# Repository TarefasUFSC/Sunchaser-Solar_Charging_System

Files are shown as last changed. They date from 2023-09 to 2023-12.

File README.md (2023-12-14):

# Sunchaser-Solar_Charging_System: Controle de Carga PWM com ESP32 e Placa Fotovoltaica

## Introdução

Este projeto foi desenvolvido como parte de um trabalho para Projeto de Sistemas Ubiquos na UFSC, para o controle eficiente da carga de baterias de chumbo-ácido ou de lítio, utilizando uma placa fotovoltaica de 20W. O sistema emprega uma metodologia de modulação de largura de pulso (PWM) controlada por um ESP32 para regular a tensão e a corrente fornecida pela placa solar, assegurando uma tensão estável na bateria. Os dados de carregamento são monitorados e transmitidos para um Broker MQTT, integrando-se ao projeto do Pluviômetro existente. Adicionalmente, um aplicativo móvel fornece acesso local aos dados através de uma API REST.

O projeto é dividido em várias etapas de desenvolvimento, com testes dedicados para cada componente, seguindo princípios de orientação a objetos. Esta documentação fornece uma visão detalhada da estrutura do projeto, descrições de hardware e software, além de instruções operacionais e de diagnóstico.

## Descrição do Projeto

O sistema é projetado para operar em locais remotos, onde a estabilidade da conexão de internet pode ser intermitente. Portanto, ele armazena dados localmente e tenta transmitir informações retroativas quando uma conexão está disponível. A abordagem de design permite o acesso local aos dados do ESP32, que pode alternar entre modos cliente e servidor para facilitar a interação com o usuário por meio de um aplicativo móvel.

### Objetivos

- Manter uma tensão estável de 12V na bateria, conforme especificações técnicas do fabricante.
- Monitorar e armazenar dados de corrente e tensão para análises de longo prazo.
- Permitir o acesso local aos dados via aplicativo móvel para monitoramento e controle.
- Transmitir dados acumulados para um sistema centralizado quando conectado à internet.

Continue lendo para uma visão detalhada da implementação do projeto, incluindo instruções de montagem de hardware, configuração de software, e operação do sistema.

### Visão de Alto Nível do Sistema

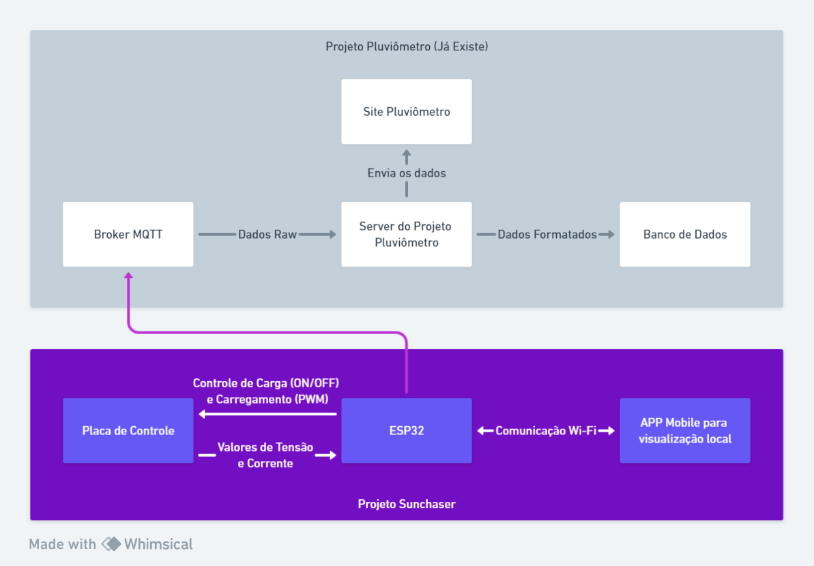
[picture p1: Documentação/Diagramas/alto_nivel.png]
Diagrama Alto Nivel


## [Hardware](https://github.com/TarefasUFSC/Sunchaser-Solar_Charging_System/tree/main/Placa%20de%20Controle/Controle%20de%20Carga%20PWM)

**FEITO COM PROTEUS 8.9**

### Visão Geral

O coração do projeto Sunchaser é uma solução de hardware meticulosamente projetada para o controle eficiente de carga de baterias através de energia solar. Este sistema é construído com um conjunto de placas interconectadas, cada uma desenhada para executar funções específicas dentro do mecanismo de carga.

### Compatibilidade do Proteus

Importante frisar que todo o design foi realizado utilizando o Proteus 8.9. Versões mais recentes do Proteus podem abrir os arquivos do projeto, mas há uma incompatibilidade retroativa: projetos salvos em versões mais novas do software não poderão ser reabertos na versão 8.9. Esta informação é crucial para a manutenção e futuras iterações do projeto por outras equipes.

### [Estruturação Modular do Projeto](https://github.com/TarefasUFSC/Sunchaser-Solar_Charging_System/tree/main/Placa%20de%20Controle/Controle%20de%20Carga%20PWM/hardware_sep_by_function)

O design inicial foi acomodado na pasta `Placa de Controle/Controle de Carga PWM/hardware proteus 8.9`. Para superar desafios encontrados durante os testes, optou-se por uma abordagem modular, segmentando o hardware em diferentes funções:

- ESP com Sensores
- Controle PWM
- Controle da Carga
- Reguladores

Esta estruturação facilitou a identificação e solução de problemas, permitindo testes isolados e otimização de cada módulo.

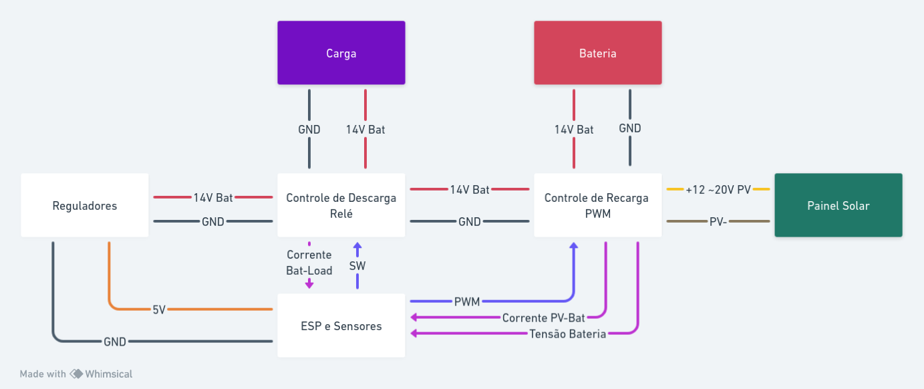
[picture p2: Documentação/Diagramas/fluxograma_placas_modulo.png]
Modularização das Placas


<details>
  <summary><b>Imagens e Descrições dos Circuitos</b></summary>
  Abaixo, as imagens dos circuitos correspondem às seções descritas, proporcionando uma representação visual dos componentes e sua disposição.

#### [ESP e Sensores](https://github.com/TarefasUFSC/Sunchaser-Solar_Charging_System/tree/main/Placa%20de%20Controle/Controle%20de%20Carga%20PWM/hardware_sep_by_function/esp_and_sensors)

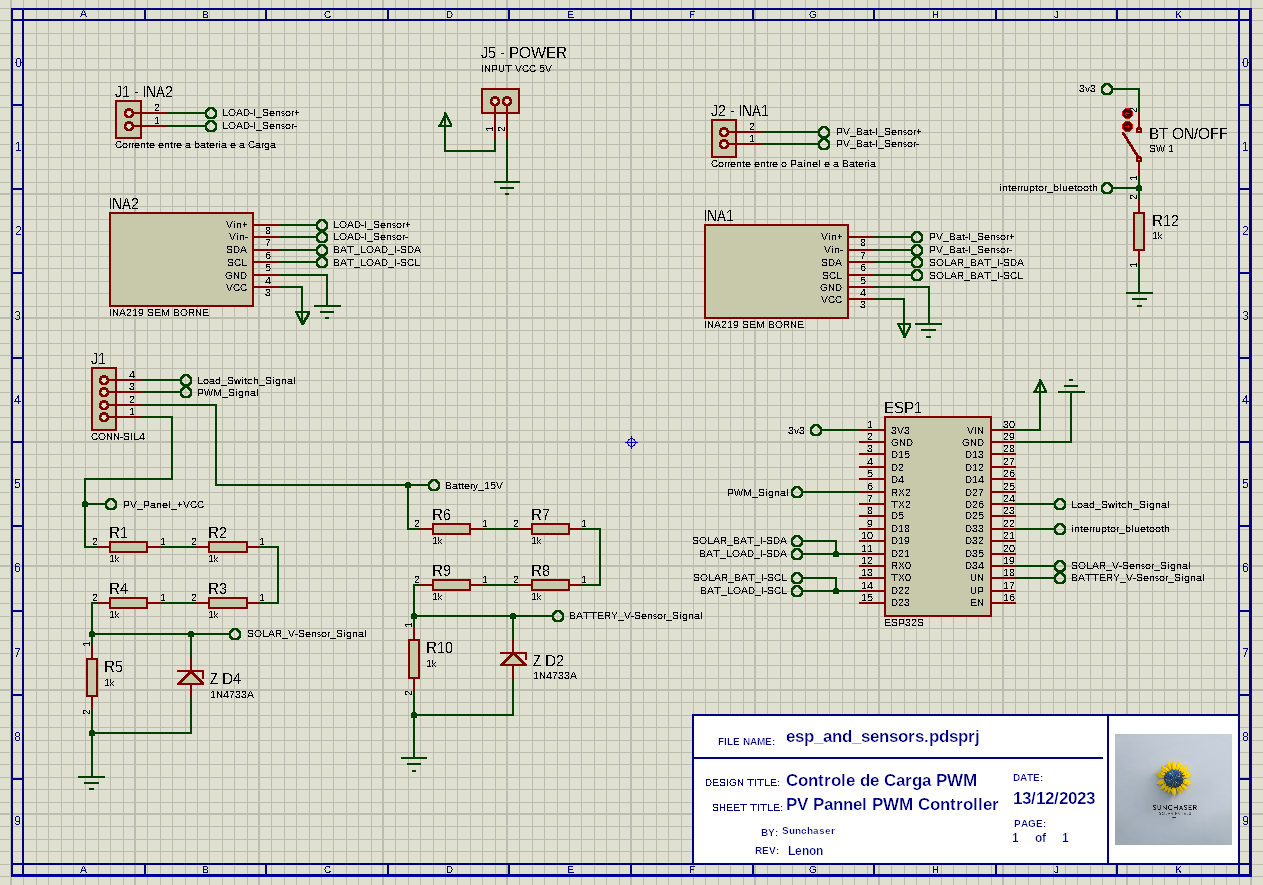
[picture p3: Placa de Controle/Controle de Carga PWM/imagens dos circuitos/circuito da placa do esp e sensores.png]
Circuito da Placa do ESP e Sensores


O circuito do ESP e sensores constitui o núcleo de processamento e coleta de dados, onde o ESP32 opera como a unidade central, gerenciando tanto a comunicação quanto o processamento dos dados de sensores.

#### [Controle PWM](https://github.com/TarefasUFSC/Sunchaser-Solar_Charging_System/tree/main/Placa%20de%20Controle/Controle%20de%20Carga%20PWM/hardware_sep_by_function/controle_de_pot-P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)

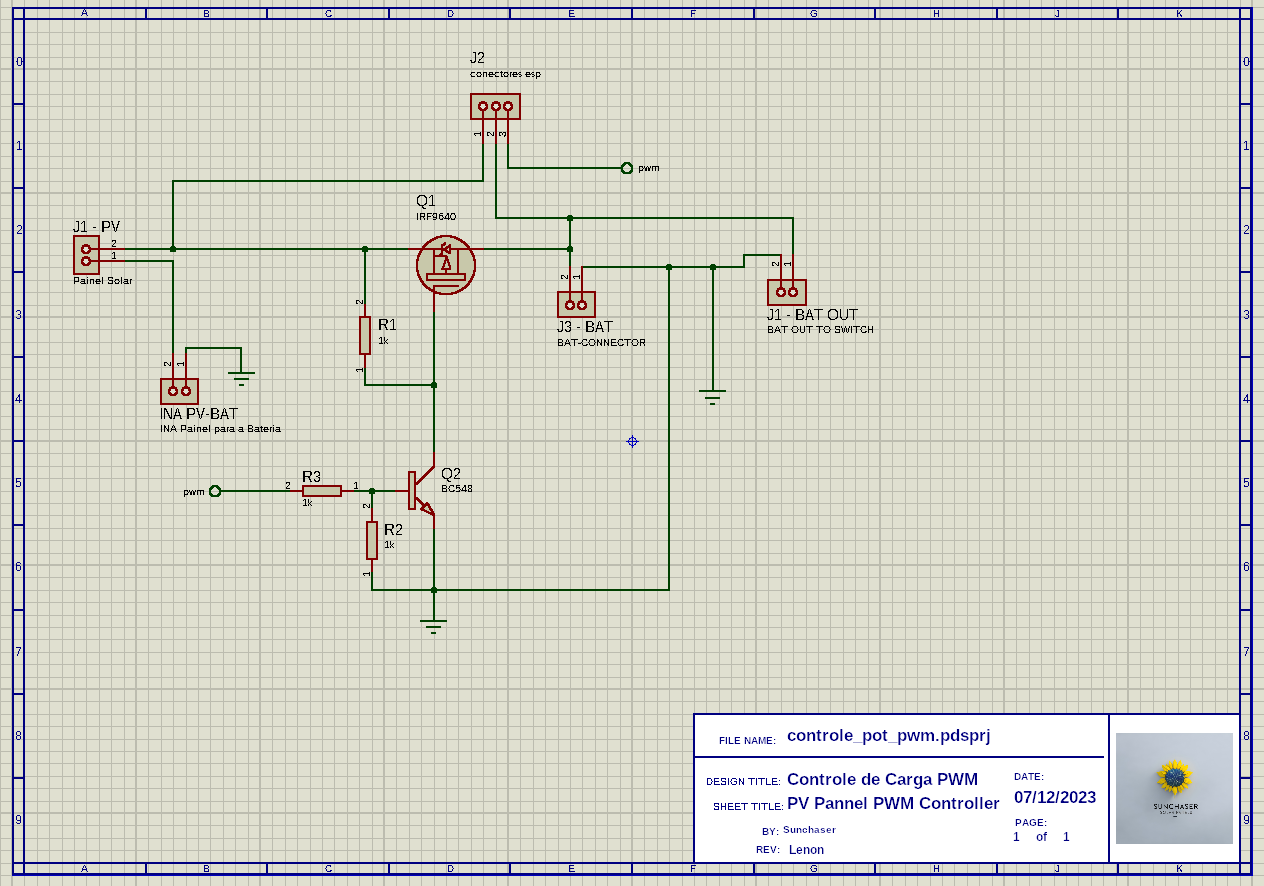
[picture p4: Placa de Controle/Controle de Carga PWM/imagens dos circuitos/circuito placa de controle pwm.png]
Circuito Controle PWM


O circuito de controle PWM manipula a tensão fornecida pela placa fotovoltaica à bateria, utilizando um MOSFET de canal P para modular a carga com precisão, baseando-se nas leituras de tensão da bateria.

#### [Controle do Switch da Carga](https://github.com/TarefasUFSC/Sunchaser-Solar_Charging_System/tree/main/Placa%20de%20Controle/Controle%20de%20Carga%20PWM/hardware_sep_by_function/controle_de_pot-S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)

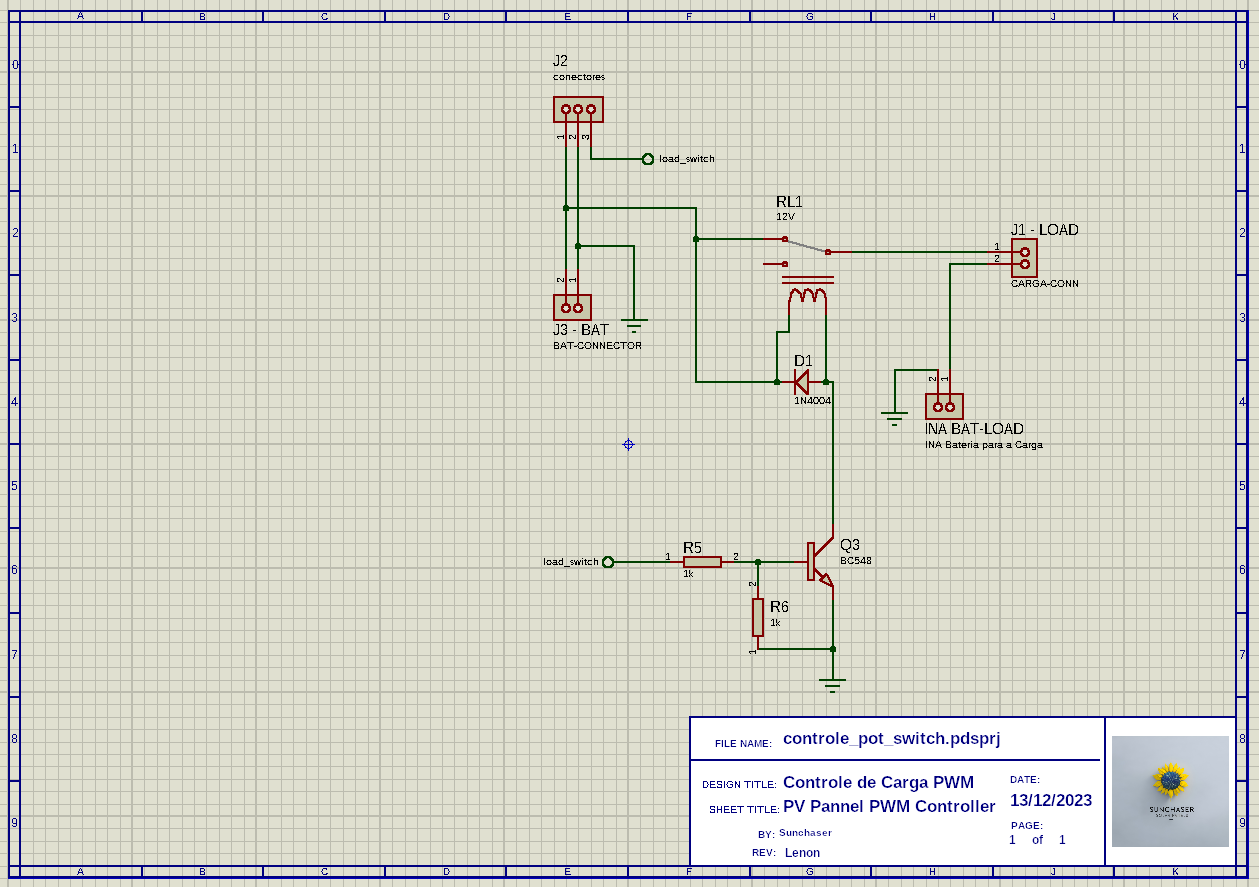
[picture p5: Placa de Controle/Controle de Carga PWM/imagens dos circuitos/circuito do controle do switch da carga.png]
Circuito Controle do Switch da Carga


Esta parte do hardware gerencia a conectividade entre a bateria e a carga, assegurando que a transferência de energia seja feita de maneira eficaz e segura, pois o Relé é aberto caso a tensão da bateria seja muito baixa (o que danifica a vida uti dela) e caso a corrente seja alta demais para a bateria.

#### [Reguladores](https://github.com/TarefasUFSC/Sunchaser-Solar_Charging_System/tree/main/Placa%20de%20Controle/Controle%20de%20Carga%20PWM/hardware_sep_by_function/reguladores_de_te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)

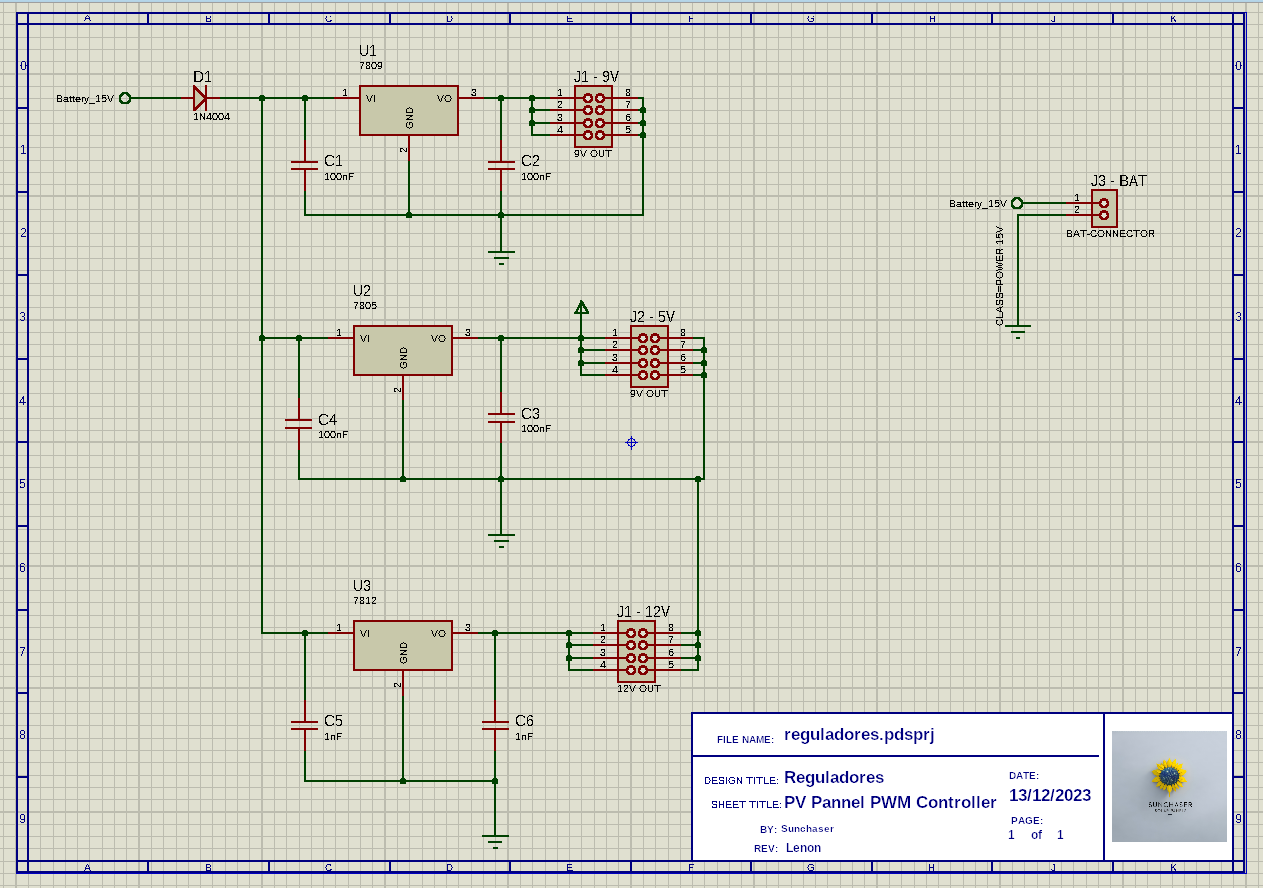
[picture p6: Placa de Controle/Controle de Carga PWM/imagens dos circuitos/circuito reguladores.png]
Circuito Reguladores


Os reguladores de tensão são componentes cruciais do projeto, desempenhando um papel vital ao fornecer tensões DC estáveis de 5V, 9V e 12V. Esta placa reguladora é uma unidade modular, projetada para ser flexível e potencialmente integrável em outros projetos. Recebendo uma tensão de entrada variando de 12 a 20V, os reguladores asseguram a estabilização nas saídas especificadas, proporcionando uma alimentação confiável e segura para todos os componentes eletrônicos do sistema.

#### [Circuito Geral](https://github.com/TarefasUFSC/Sunchaser-Solar_Charging_System/tree/main/Placa%20de%20Controle/Controle%20de%20Carga%20PWM/hardware%20proteus%208.9)

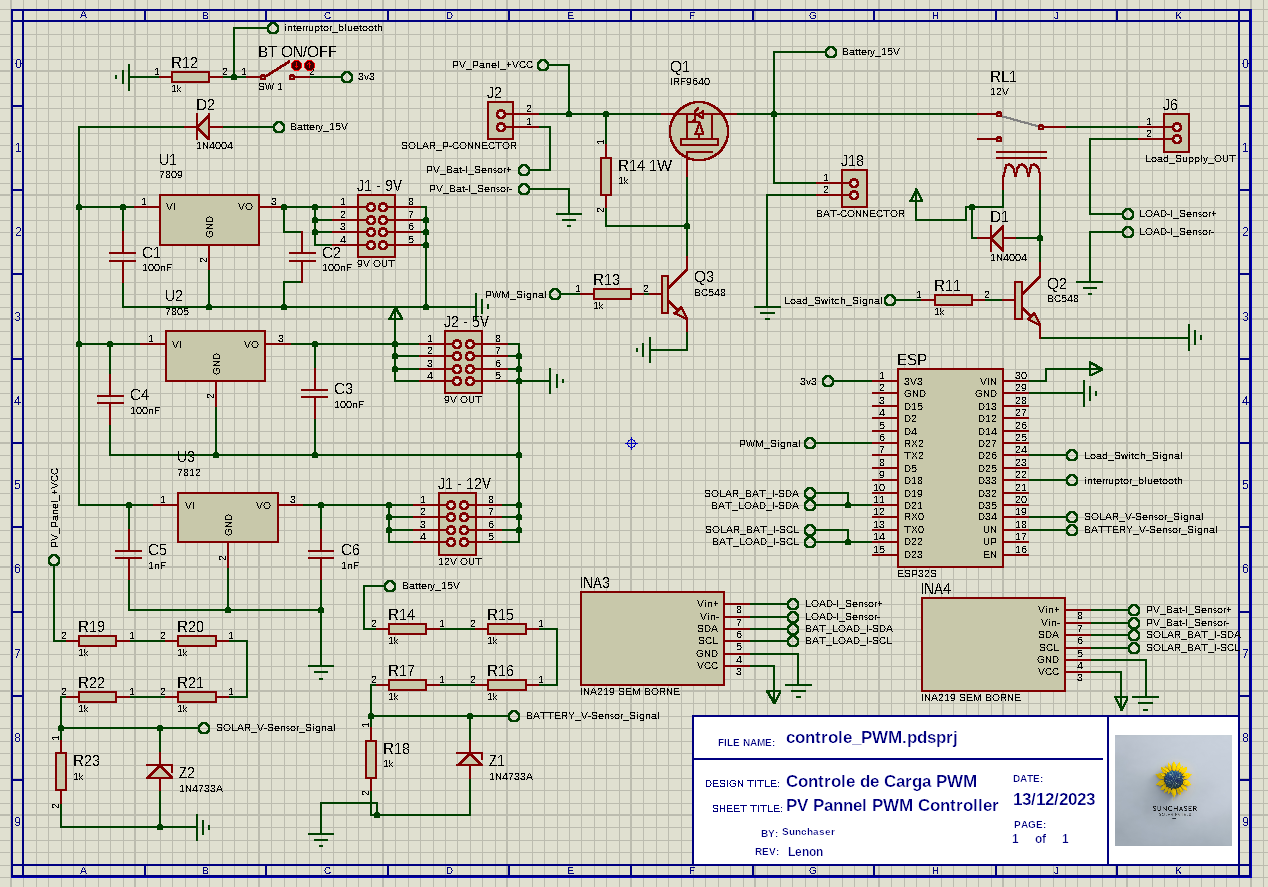
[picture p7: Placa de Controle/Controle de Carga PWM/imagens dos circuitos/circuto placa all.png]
Circuito Visão Geral


</details>

### Observações Técnicas Importantes

- A presença de uma resistência interna na simulação da bateria é vital para o comportamento adequado das tensões no circuito. A ausência desta foi contornada com a implementação de um resistor em paralelo com a fonte de alimentação durante os testes.
- A utilização do ADC1 é obrigatória para leituras analógicas, pois o ADC2 se torna inoperante quando o Wi-Fi do ESP32 está ativado. Ademais, foi observado que a entrada de 5V em qualquer pino do ADC1 pode ocasionar leituras incorretas nos outros pinos. Para resolver isso, a tensão de pulldown da interrupção foi ajustada para 3.3V.

### Futuras Melhorias e Iterações

O projeto é configurado para ser altamente escalável e adaptável. Recomenda-se que futuras equipes expandam as capacidades do sistema, incorporando novas configurações e aprimorando as especificações técnicas, como as relacionadas à bateria, para atender a novas demandas ou melhorar a eficiência do controle de carga usando MPPT.

## Configuração de Software

### Pinagem

| Pino (Nome no Código) | Número do Pino | Arquivo de Declaração | Observações |
| --- | --- | --- | --- |
| `PWM_Pin` | 16 | BatteryControl.h | Utilizado para controle PWM. |
| `S2_Pin` | 26 | BatteryControl.h | - |
| `interrupt_pin` | 33 | communicator.h | Não pode ser 5V para evitar problemas com ADC1. |
| `Battery_Voltage_Pin` | 39 | Sensors.h | Pino de leitura de tensão da bateria, deve estar no ADC1. |
| `Solar_Voltage_Pin` | 34 | Sensors.h | Pino de leitura de tensão do painel solar, deve estar no ADC1. |
| `INA219_Sensor1_SCL`  | 11 | Obrigatório | SCL do primeiro sensor INA219. |
| `INA219_Sensor1_SDA`  | 10 | Obrigatório | SDA do primeiro sensor INA219. |
| `INA219_Sensor2_SCL`  | 11 | Obrigatório | SCL do segundo sensor INA219. |
| `INA219_Sensor2_SDA`  | 10 | Obrigatório | SDA do segundo sensor INA219. |

Observações Gerais:

- Os pinos de leitura analógica devem estar no ADC1 devido ao uso do Wi-Fi, que interfere com o ADC2.
- O pino `interrupt_pin` não deve receber 5V para evitar conflitos com outras leituras no ADC1.

### Ambiente de Desenvolvimento

O código-fonte foi desenvolvido na Arduino IDE, uma plataforma de desenvolvimento que permite a escrita, compilação e upload de programas para placas compatíveis com Arduino, como o ESP32 utilizado neste projeto.

### Instalação

1. Instale a última versão da Arduino IDE a partir do [site oficial](https://www.arduino.cc/en/software).
2. Configure a Arduino IDE para suportar o ESP32 seguindo as instruções disponíveis na [documentação do ESP32](https://docs.espressif.com/projects/arduino-esp32/en/latest/installing.html).
3. Instale todas as bibliotecas necessárias mencionadas nos arquivos `package.json` e `yarn.lock` localizados na pasta `App Mobile/mobile`.

### Descrição dos Programas de Teste

Os programas de teste localizados em `Programas ESP/Desenvolvimento` são fundamentais para validar o funcionamento individual de cada componente do sistema. Cada subdiretório contém um exemplo de código que pode ser compilado e carregado separadamente para testar sensores, comunicação, controle PWM, entre outros.

### Programa Final

A pasta `Programas ESP/ProgramaFinal` contém o código-fonte consolidado que será executado no ESP32. Inclui a integração das classes desenvolvidas, a lógica de controle PWM e a comunicação com o Broker MQTT.

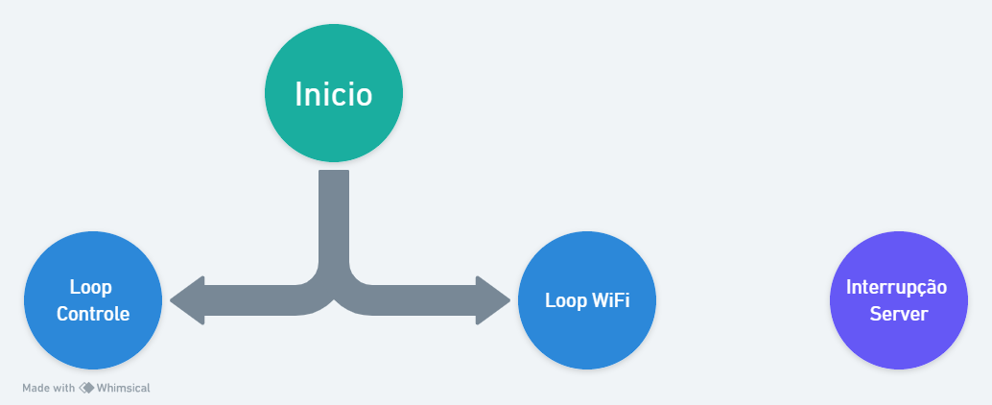
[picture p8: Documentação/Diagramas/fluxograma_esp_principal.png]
Funcionamento Geral


# Documentação do Código

O software do projeto é composto por várias classes, cada uma responsável por uma parte específica da lógica de controle e comunicação do sistema. Abaixo estão os arquivos principais e a descrição de suas responsabilidades e operações:

<details>
  <summary><b>Classe BatteryControl</b></summary>
  
  - **Arquivos**: `BatteryControl.cpp`, `BatteryControl.h`
  - **Responsabilidade**: Controla o processo de carregamento da bateria ao modular a tensão fornecida pelo painel solar. Garante a manutenção da tensão da bateria nos níveis ideais para otimizar o carregamento e a vida útil da bateria.
  - **Métodos Principais**:
    - `PWM_init()`: Inicializa a configuração do PWM.
    - `battery_loop()`: Executa o loop principal de controle da bateria, ajustando o PWM conforme necessário.
    - `check_error(float error)`: Verifica e lida com erros no sistema de carregamento.
    - `stopCharging()`: Interrompe o processo de carregamento da bateria.
    - `bulk_stage()`, `absorption_stage()`, `float_stage()`: Gerenciam as diferentes fases do processo de carregamento.
    - `charging_control()`: Controle lógico para a regulação do carregamento da bateria.
    - `load_connection()`: Gerencia a conexão e desconexão da carga da bateria.
    - `changeDutyCycle()`: Ajusta o ciclo de trabalho do PWM para regular a tensão.

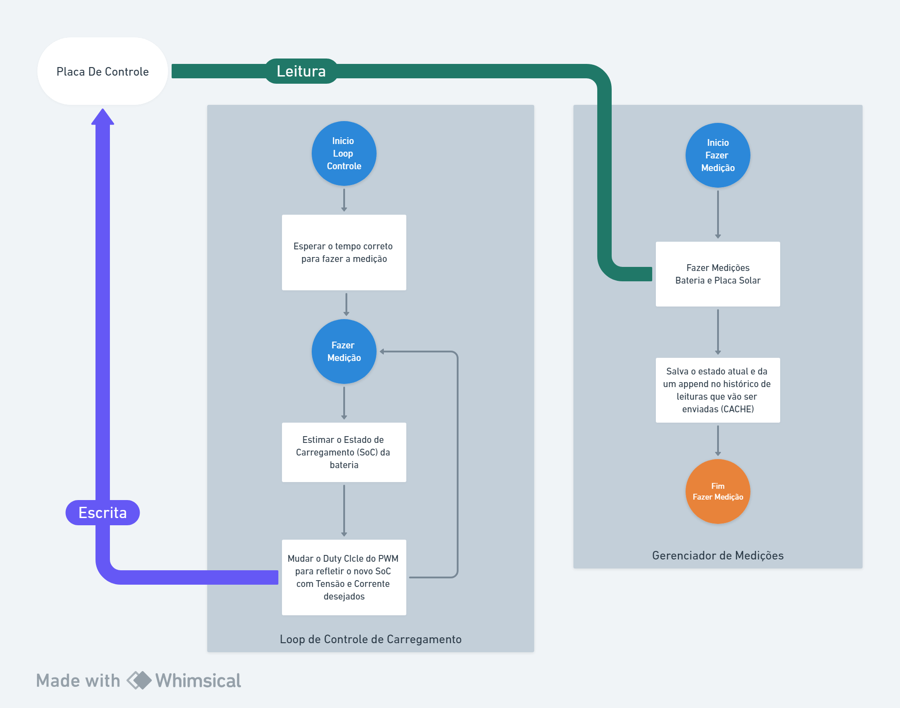
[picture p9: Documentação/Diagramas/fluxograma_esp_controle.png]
Diagrama do Cotrole de Carga


</details>

<details>
  <summary><b>Classe Sensors</b></summary>

- **Arquivos**: `Sensors.cpp`, `Sensors.h`
- **Responsabilidade**: Realiza a leitura da corrente e tensão da bateria e do painel solar.
- **Métodos Principais**:
  - `INA_init()`: Inicializa os sensores INA219.
  - `battery_current()`, `pv_current()`: Retorna a corrente medida pela bateria e pelo sensor do painel solar.
  - `battery_voltage()`, `pv_voltage()`: Retorna a tensão medida pela bateria e pelo sensor do painel solar.
  </details>

<details>
  <summary><b>Classe TimeConfigurations</b></summary>

- **Arquivo**: `TimeConfigurations.h`
- **Responsabilidade**: Armazena as configurações de tempo relacionadas ao intervalo de leitura, tamanho máximo do cache e memória de longo prazo.
</details>

<details>
  <summary><b>Classe TimerInterrupt</b></summary>

- **Arquivos**: `TimerInterrupt.cpp`, `TimerInterrupt.h`
- **Responsabilidade**: Gerencia as interrupções do temporizador para realizar operações periódicas.
- **Métodos Principais**:

  - `timer_init()`: Inicializa o timer.
  - `timer_interruption()`: Método chamado em cada interrupção do temporizador.
  - `tryToSendCacheToServer()`: Tenta enviar dados do cache para o servidor.
  </details>
  <details>
    <summary><b>Classe SaveToFlash</b></summary>

- **Arquivos**: `SaveToFlash.cpp`, `SaveToFlash.h`
- **Responsabilidade**: Gerencia o armazenamento e recuperação de dados de leituras na memória flash.
- **Métodos Principais**:
  - `mountLittleFS()`: Monta o sistema de arquivos LittleFS.
  - `saveToCache()`, `saveToLongTerm()`: Salva as leituras no cache ou na memória de longo prazo.
  - `get_readings_from_cache()`, `get_readings_from_longterm()`: Recupera leituras do cache ou da memória de longo prazo.

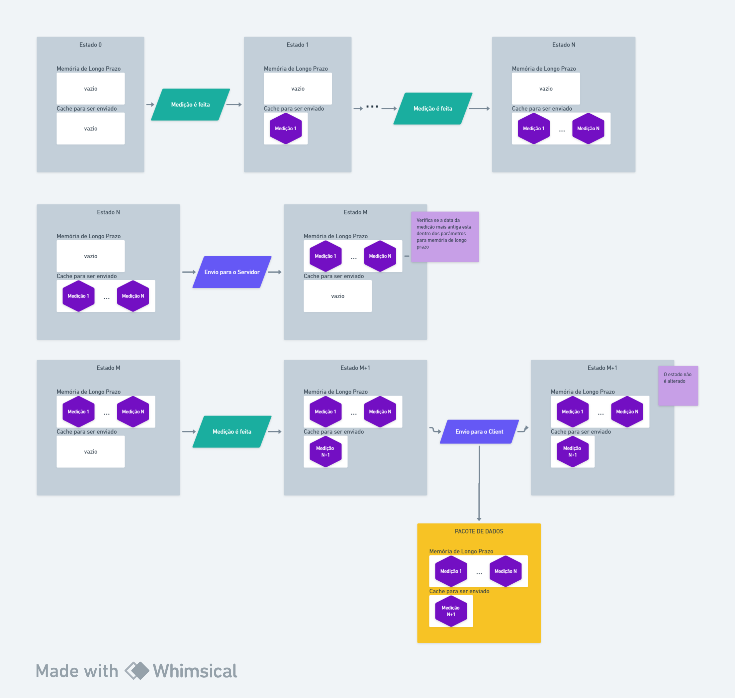
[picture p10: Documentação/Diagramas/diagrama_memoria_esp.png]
Diagrama Memoria


</details>

<details>
  <summary><b>Classe Communicator</b></summary>

- **Arquivos**: `communicator.cpp`, `communicator.h`, `communicator_client_module.cpp`, `communicator_interruption_module.cpp`, `communicator_mqtt_module.cpp`, `communicator_server_module.cpp`
- **Responsabilidade**: Esta classe gerencia toda a comunicação do ESP32, atuando como um cliente para se conectar ao Broker MQTT, e como um servidor para interagir com o aplicativo móvel. A classe também gerencia a transição entre o modo de economia de energia e operação normal e lida com interrupções externas que podem sinalizar a necessidade de mudança no estado de operação.

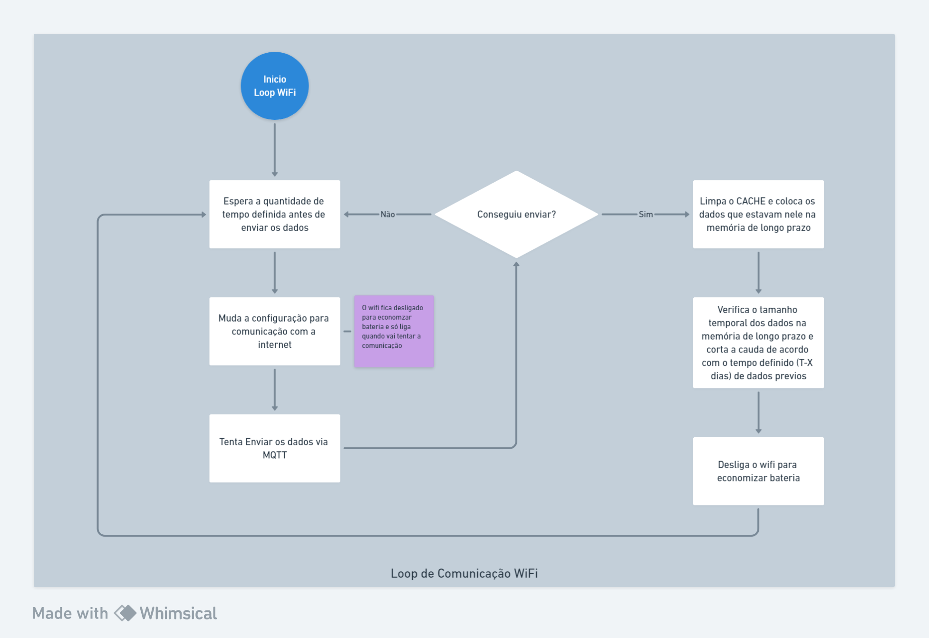
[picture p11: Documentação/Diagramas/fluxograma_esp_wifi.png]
Diagrama do Wifi Client

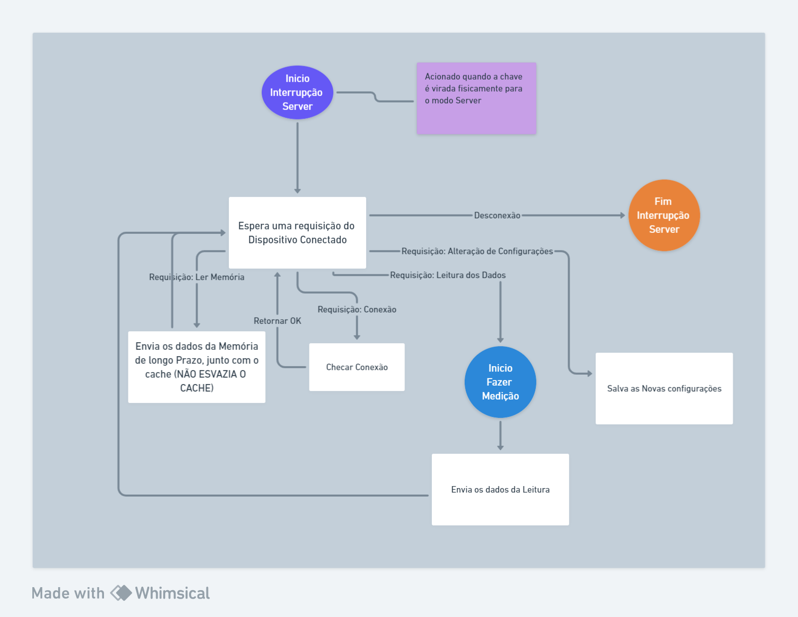
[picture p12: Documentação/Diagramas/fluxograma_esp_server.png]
Diagrama do Wifi Server


### Métodos Principais

- `init()`: Configura os componentes necessários e inicia a conexão Wi-Fi.
- `sleep()`: Desativa o Wi-Fi para economizar energia.
- `reconnect_client()`: Reconecta o ESP32 à rede Wi-Fi e ao broker MQTT após o período de sono.
- `attach_interruption()`: Configura a interrupção externa que permite ao ESP32 alternar entre os modos cliente e servidor.
- `check_interruption_flag()`: Verifica se uma interrupção ocorreu, indicando que o estado de operação deve ser alterado.
- `startServer()`: Inicia o servidor HTTP para comunicação local com o aplicativo móvel.
- `connectToMQTT()`: Estabelece conexão com o Broker MQTT e gerencia a reconexão se necessário.
- `handleClientRequests()`: Processa as requisições recebidas quando o ESP32 está operando como servidor HTTP.
- `_setup_mqtt()`: Configura o cliente MQTT com o servidor e porta corretos, e define a função de callback para mensagens recebidas.
- `_mqtt_loop()`: Mantém a conexão MQTT ativa e processa qualquer mensagem recebida.
- `_wifi_ap_config()`: Configura o ponto de acesso Wi-Fi quando o ESP32 está no modo servidor.
- `_stop_ap()`: Desativa o ponto de acesso Wi-Fi e o servidor HTTP quando não são mais necessários.

### Observações

- O método `sleep()` é crítico para a conservação de energia, especialmente em ambientes remotos onde a energia é limitada.
- O sistema de interrupção permite que o dispositivo mude dinamicamente entre os modos de operação sem a necessidade de reinicialização ou interação manual.
- A implementação do MQTT é robusta, com mecanismos de reconexão e callbacks para garantir a entrega de mensagens mesmo em condições de rede instáveis.
</details>

# Operação do Programa

O ciclo de execução principal do programa é controlado pelo arquivo `ProgramaFinal.ino`, que coordena as operações das classes e gerencia o fluxo de controle do sistema. O arquivo contém a função `setup()` para inicialização e a função `loop()` para o ciclo de execução contínuo.

- Na função `setup()`, o sistema inicia conectando-se à rede Wi-Fi e sincronizando o horário para garantir que os dados sejam timestamped corretamente.
- Em seguida, os módulos de controle de carga e sensores são inicializados, preparando o sistema para começar o monitoramento e controle.
- A função `loop()` entra em um ciclo onde:
  - A lógica de controle de carga é executada para ajustar o PWM e manter a tensão da bateria.
  - As leituras dos sensores são feitas e armazenadas periodicamente no cache local.
  - O sistema tenta enviar dados acumulados para o Broker MQTT e, em caso de sucesso, transfere esses dados para a memória de longo prazo.
  - Se o switch de acesso local for ativado, o ESP32 muda para o modo servidor, permitindo que o aplicativo móvel se conecte e interaja com o sistema.

### Documentação das APIs

A comunicação com o ESP32 pode ser realizada através das seguintes APIs, disponíveis quando o ESP está em modo servidor:

| Operação | Rota | Query Params  | Body | Retorno | Observações |
| --- | --- | --- | --- | --- | --- |
| GET | /cache | page: Numeric | - | JSON: Lista de leituras do cache, total de itens, itens por página (10) | Máximo de 10 itens por página |
| GET | /ltm | page: Numeric | - | JSON: Lista de leituras da memória, total de itens, itens por página (10) | Máximo de 10 itens por página |
| POST | /reading  | - | - | JSON: Novas medições | - |
| POST | /settings | - | JSON: Novas configurações | - | O app verifica o sucesso pela resposta do status code |
| GET | /settings | - | - | JSON: Configurações atuais | - |
| GET | /check | - | - | String: "conectado!" | Utilizado para verificar a conexão com o ESP |

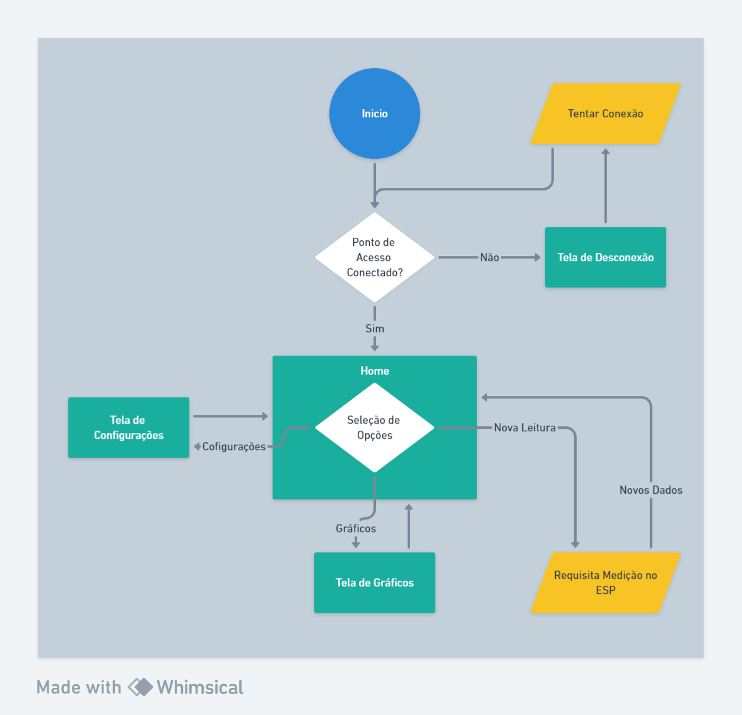
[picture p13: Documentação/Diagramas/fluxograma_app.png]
Diagrama do Aplicativo


### Diagnóstico de Problemas e Soluções

Durante o desenvolvimento, foram identificados e solucionados diversos desafios:

- **Problema de Versão do Proteus**: Limitação da versão 8.9 do Proteus para salvar e abrir arquivos sem perder a compatibilidade.
- **Comportamento Inesperado de Tensões**: Solucionado com a inclusão de uma resistência em paralelo à fonte de bancada.
- **Limitações dos ADCs do ESP32**: Ajustes nas leituras analógicas para evitar conflitos entre o ADC2 e o uso do Wi-Fi e erros causados por tensões altas nos pinos do ADC1.

### Melhorias e Manutenção

Algumas sugestões para melhorias futuras incluem:

- Inclusão de novas configurações na classe de ajustes, como especificações técnicas variáveis da bateria.
- Aumento da robustez do sistema contra falhas de conectividade.
- Interface de usuário aprimorada no aplicativo móvel para facilitar a interação e o monitoramento.

Manter a documentação atualizada e criar testes para novas funcionalidades são essenciais para a manutenção contínua do projeto.

## Estrutura de Arquivos

O projeto está organizado em diretórios que separam cada componente e fase de desenvolvimento, facilitando a navegação e compreensão do sistema como um todo. Abaixo está a árvore de arquivos com a descrição de cada diretório e arquivo-chave:

<details>
  <summary><b>Mostrar File Tree</summary>

  ```
.
├── App Mobile
│   └── mobile
│       ├── App.js
│       ├── app.json
│       ├── babel.config.js
│       ├── package.json
│       ├── src
│       │   ├── assets
│       │   │   ├── *.png
│       │   ├── components
│       │   │   └── components.js
│       │   ├── pages
│       │   │   ├── graph.js
│       │   │   ├── home.js
│       │   │   └── settings.js
│       │   └── routes
│       │       └── routes.js
│       └── yarn.lock
├── Documentação
│   ├── Cronograma/
│   ├── Diagramas/
│   ├── Planejamento/
│   ├── Relatorios/
│   └── Revisão de Lietratura/
├── logo/
├── Placa de Controle
│   ├── Controle de Carga PWM
│   │   ├── ESP32-Pinout.jpg
│   │   ├── hardware/ -> (Antigo)
│   │   ├── hardware proteus 8.9/ -> Placa Geral com tudo incluso
│   │   ├── hardware_sep_by_function
│   │   │   ├── controle_de_pot/
│   │   │   ├── controle_de_pot-PWM/
│   │   │   ├── controle_de_pot-SWITCH/
│   │   │   ├── esp_and_sensors/
│   │   │   └── reguladores_de_tensao/
│   │   ├── imagens dos circuitos/
│   │   ├── teste controle MOSFETs/
│   ├── Cuk Converter/ -> Testes do inicio do projeto usando o conversor cuk (Não é usado mais)
├── Programas ESP
│   ├── Desenvolvimento
│   │   ├── 1-CurrentSensorExample/
│   │   ├── 2-VoltageReadingExample/
│   │   ├── 3-Current_Voltage_reading/
│   │   ├── 4-PWMControlExample/
│   │   ├── 5-BatteryControl/
│   │   ├── 6-TimerInterrupt/
│   │   ├── 7-BLE_server/
│   │   ├── 8-LittleFS/
│   │   ├── ESP-GetTime/
│   │   ├── MainProject/
│   │   └── Wifi-Server_Client/
│   ├── ProgramaFinal
│   │   ├── BatteryControl.cpp
│   │   ├── BatteryControl.h
│   │   ├── communicator_client_module.cpp
│   │   ├── communicator.cpp
│   │   ├── communicator.h
│   │   ├── communicator_interruption_module.cpp
│   │   ├── communicator_mqtt_module.cpp
│   │   ├── communicator_server_module.cpp
│   │   ├── FinalProgram.md
│   │   ├── FinalProgram.xml
│   │   ├── ProgramaFinal.ino
│   │   ├── PubSubClient.cpp
│   │   ├── PubSubClient.h
│   │   ├── SaveToFlash.cpp
│   │   ├── SaveToFlash.h
│   │   ├── Sensors.cpp
│   │   ├── Sensors.h
│   │   ├── TimeConfigurations.h
│   │   ├── TimerInterrupt.cpp
│   │   └── TimerInterrupt.h
│   └── pubsubclient-master.zip
├── README.md
└── Referencias que o professor deu no inicio
    ├── *.pdf

```

</details>

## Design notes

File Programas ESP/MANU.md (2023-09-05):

Cria um branch e trabalha nessa pasta.
para cada teste crie uma pasta separada e depois junta tudo na pasta `Programa Final`

Seria interessante voce ja ir fazendo as coisas usando modularização com funções o maximo possivel, tipo `float get_voltage_value_sensorX()` (ou vc pode passar um identificador do sensor como referencia, sla. É só pra facilitar a sua vida)

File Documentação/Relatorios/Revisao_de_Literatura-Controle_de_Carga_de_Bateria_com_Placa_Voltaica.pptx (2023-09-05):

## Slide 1

Controle de Carga de Bateria com Placa Voltaica

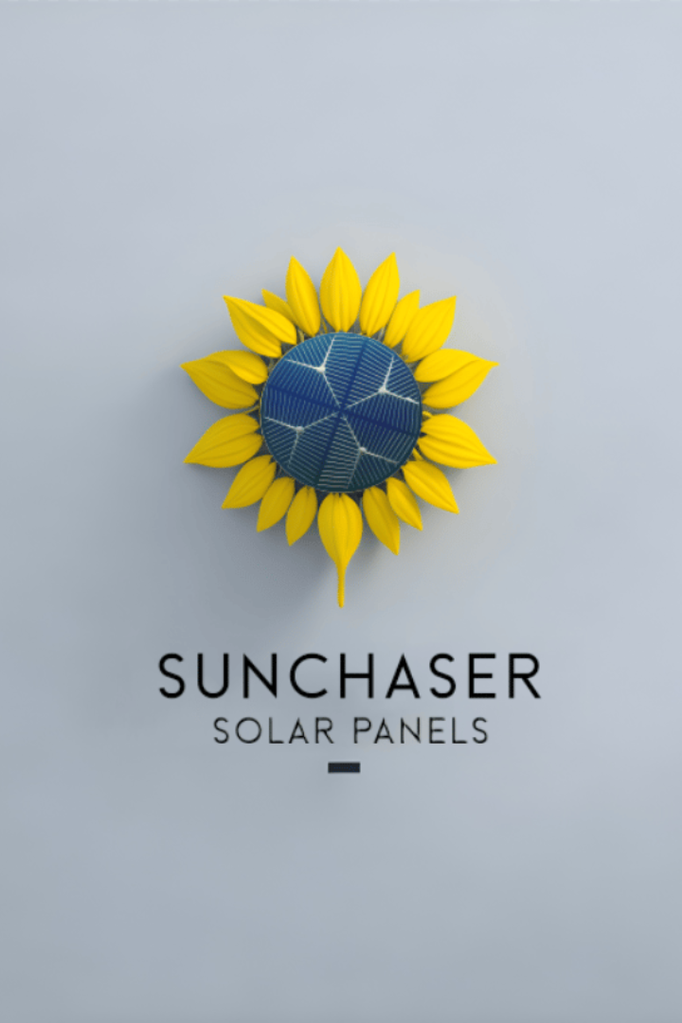
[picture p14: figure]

- Lucas Eduardo Schlenert de Oliveira

- Manoella Rockembach

- Rodrigo Ferraz Souza

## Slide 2

Introdução

Gestão eficiente de energia é uma prioridade de nosso mundo. Em um esforço para soluções mais sustentáveis, este projeto foca no controle de carga de bateria de Chumbo-Ácido (12V 5Ah) usando uma placa fotovoltaica. Com este objetivo, o controle PWM é utilizado para gerenciar tensão e corrente.

A integração com sistemas externos é possível via MQTT Broker, e o acesso local aos dados pode ser realizado através de um aplicativo móvel com Bluetooth.

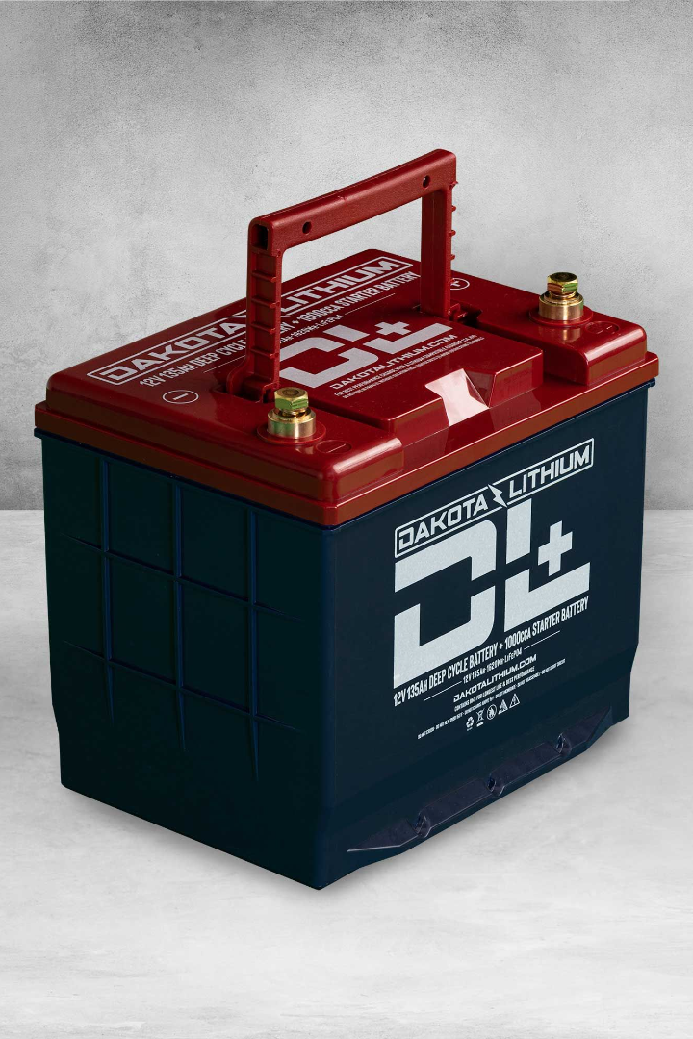
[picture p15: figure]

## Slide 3

Gerenciamento de tensão e corrente na carga da bateria usando um ESP32

Broker MQTT utilizado para comunicação com o servidor do Pluviômetro

Utilização de um aplicativo móvel com Bluetooth

Notificações push no aplicativo mobile usando o Google Firebase

Objetivos do Projeto

Uso do controle PWM

Integração com sistemas externos

Acesso local aos dados

Alertas (Opcional)

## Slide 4

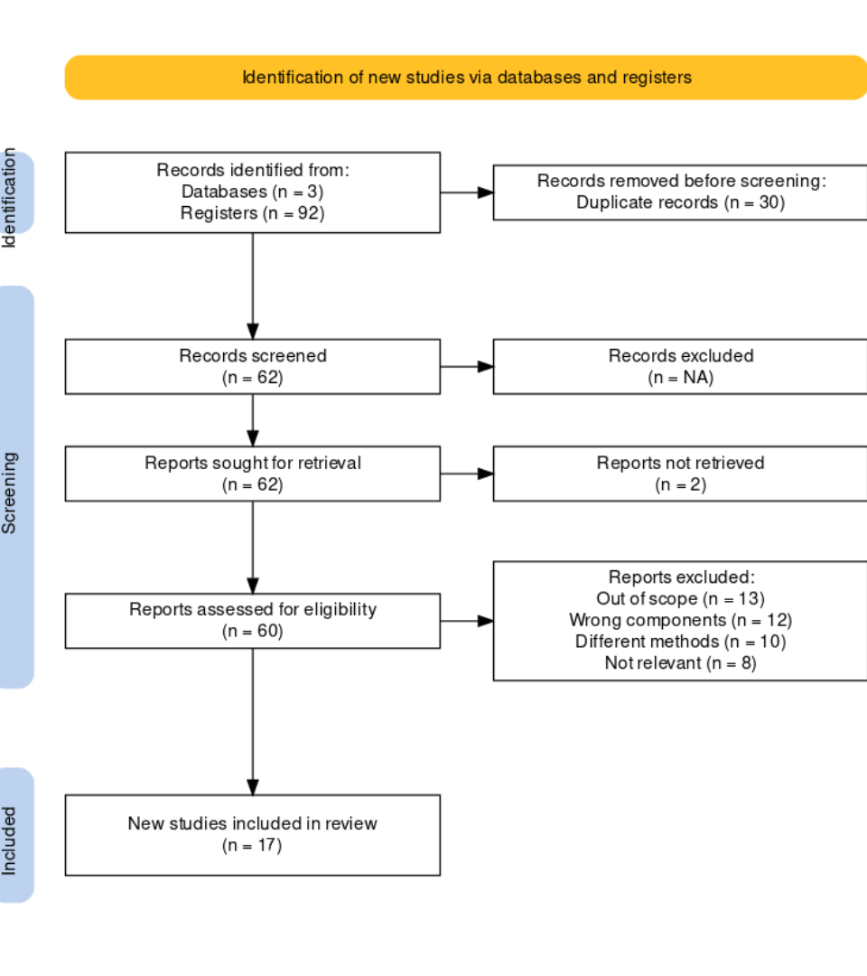
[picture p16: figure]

Revisão de Literatura

62 artigos analisados

Nas bases IEEE, Web of Science e Scopus

17 artigos inclusos

Após análise de escopo, componentes usados, metodologia e relevância

Principais temas abordados

Eficiência energética, métodos de controle e estimativa do SoC.

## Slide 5

Cronograma - Agosto, Setembro e Outubro

Aqui está o cronograma para os meses de agosto, setembro e outubro:Visualizar a planilha do cronograma (https://docs.google.com/spreadsheets/d/1eAHwZ90z7WzfCC42r8mtiiq0TJHsQQWhFocUj3pGwtQ/edit?usp=sharing)

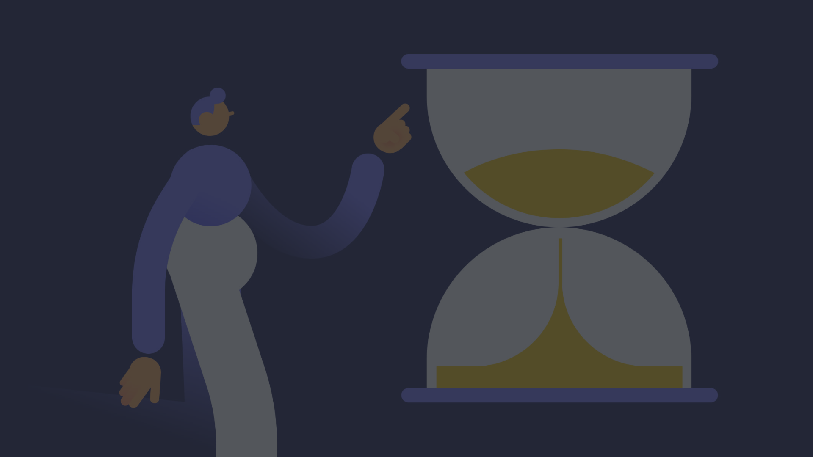
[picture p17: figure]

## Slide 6

- Carregamento adaptativo para otimizar a bateria de chumbo ácido, como destacado por [Lavety et al. 2019]

- Sistemas de monitoramento [Lin et al. 2016] para melhorar a vida útil da bateria em configurações PWM

- Algoritmos para otimizar o carregamento da bateria, enfatizados por [Belarbi et al. 2019] e [Yoomak et al. 2018]

- O projeto visa otimizar o armazenamento e uso de energia solar

- Combinação de estratégias avançadas pode levar a um sistema mais eficiente

- Recomenda-se testes para validar e refinar o sistema

Conclusão

Estratégias de Carregamento:

Monitoramento e Feedback:

Integração com Painel Solar:

Considerações Finais:

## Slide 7

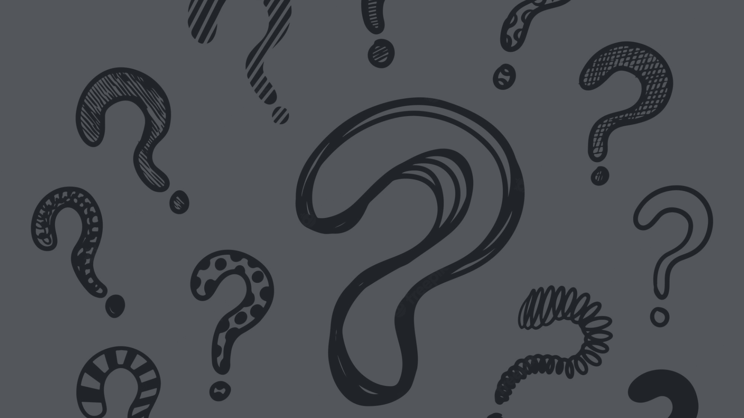
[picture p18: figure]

Perguntas?

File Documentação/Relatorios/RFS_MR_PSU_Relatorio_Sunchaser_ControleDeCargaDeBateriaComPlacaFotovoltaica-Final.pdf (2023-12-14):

## Controle de Carga de Bateria com Placa Voltaica

Lucas Eduardo Schlenert de Oliveira¹

, Manoella Rockembach¹

, Rodrigo Ferraz Souza¹

1Universidade Federal de Santa Catarina (UFSC)

engcomp.lucasedu@gmail.com

manu.rockemba@gmail.com

dev.rodrigofs@gmail.com

Abstract. This report delves into the development of a battery charge control system using a voltaic plate, specifically for a Lead-Acid battery (12V 5Ah). The core of this project revolves around the use of PWM control to manage the voltage and current from the plate to the battery, ensuring efficient energy management. The system aims to control the battery’s charging in various States of Charging, ensuring efficient and safe charging. Furthermore, the project seeks to integrate communication with external systems, transmitting voltage and current data to a rain gauge project server via an MQTT Broker. A mobile application will also allow local access to charging data via Acess point to the ESP server. Advanced features, such as alert systems, are proposed, but due to time constraints, they might not be incorporated.

Resumo. Este relatorio aprofunda-se no desenvolvimento de um sistema de ´ controle de carga de bateria usando uma placa voltaica, especificamente para uma bateria de Chumbo-Acido (12V 5Ah). O cerne deste projeto gira em torno ´ do uso do controle PWM para gerenciar a tensao e a corrente da placa para ˜ a bateria, garantindo uma gestao eficiente de energia. O sistema visa con- ˜ trolar o carregamento da bateria em varios Estados de Carga, assegurando ´ um carregamento eficiente e seguro. Alem disso, o projeto busca integrar a ´
comunicaçao com sistemas externos, transmitindo dados de tens ˜ | ao e corrente ˜
para um servidor de projeto de pluviometro via um Broker MQTT. Um aplicativo ˆ
movel tamb ´ | em permitir ´ | a o acesso local aos dados de carregamento via Ponto ´
de Acesso ao servidor do ESP. Funcionalidades avançadas, como sistemas de
alerta, sao propostas, mas devido a limitaç ˜ | oes de tempo, elas podem n ˜ | ao ser ˜
incorporadas.

### 1. Introduçaõ

Em um mundo crescentemente voltado para soluçoes sustent ˜ | aveis, a gest ´ | ao eficiente de ˜
energia torna-se uma prioridade. Neste contexto, o presente documento aborda o desenvolvimento de um sistema de controle de carga de bateria de Chumbo-Acido (12V 5Ah) ´
utilizando uma placa voltaica. O cerne deste projeto e a utilizaç ´ | ao de um controle PWM ˜
para gerenciar a tensao e corrente da placa em direç ˜ | aõ a bateria, garantindo uma gest ` | aõ
eficaz da energia.
O sistema controlara o carregamento da bateria em diversos ´ | States of Charging,
assegurando um carregamento eficiente e seguro, o que contribui para maximizar o tempo

de vida da bateria. Alem da efici ´ | encia no controle de energia, o projeto visa uma ˆ
comunicaçao integrada com sistemas externos. Os dados de tens ˜ | ao e corrente ser ˜ | ao trans- ˜
mitidos para um servidor do projeto do pluviometro por meio de um ˆ | Broker MQTT. Adi-
cionalmente, um aplicativo movel permitir ´ | a o acesso local aos dados de carregamento via ´
ponto de acesso ao servidor do ESP. Como um diferencial, ha a proposta de implementar ´ um sistema de alertas. No entanto, devido a limitaçoes de tempo, essa funcionalidade ˜
pode nao ser incorporada. Caso seja, os alertas ser ˜ | ao gerados pelo servidor j ˜ | a existente, ´
com base nas entradas de dados dos sensores. Uma inovaçao desejada ˜ | e que, ao identi- ´
ficar uma situaçao cr ˜ | ítica, uma notificaçao de alerta seja enviada ao aplicativo m ˜ | ovel do ´
usuario por meio do ´ | Google Firebase.
Neste documento, apos a introduç ´ | ao, apresentaremos uma seç ˜ | ao dedicada ˜ | a re- `
visao metodol ˜ | ogica. Nela, discutiremos a metodologia adotada para a realizaç ´ | ao da re- ˜
visao, incluindo os crit ˜ | erios de inclus ´ | ao e exclus ˜ | ao, bem como o processo de seleç ˜ | ao de ˜
estudos relevantes. Uma analise aprofundada dos resultados obtidos ser ´ | a realizada, onde ´
as principais descobertas serao sintetizadas. ˜
Na sequencia, introduziremos uma seç ˆ | ao sobre o desenvolvimento do projeto. ˜
Esta parte detalhara o planejamento, desenvolvimento e testes realizados, oferecendo uma ´
visao abrangente de todas as etapas e processos envolvidos na execuç ˜ | ao do projeto, ga- ˜
rantindo transparencia e compreens ˆ | ao claras de nossas metodologias e resultados. ˜
2. Revisao R ˜ | apida ´

### 2.1. Metodologia

Com o intuito de realizar uma revisao r ˜ apida, as seguintes strings de pesquisa foram cons- ´ truidas e aplicadas nas bases de referencia IEEE, Web of Science e Scopus: ˆ

- (”photovoltaic”OR ”solar panel”OR ”PV”) AND (”PWM”OR ”Pulse Width Modulation”) AND (”charge controller”OR ”charge regulator”OR ”charging technique”) AND (”lead-acid”OR ”VRLA”)
- (”battery charging”OR ”charge regulation”OR ”charge control”) AND (”SoC”OR ”State of Charging”OR ”charging state”OR ”battery status”) AND (”lead-acid”OR ”Pb-acid”OR ”VRLA”) AND (”efficiency”OR ”safety”OR ”parameters”OR ”measures”OR ”best practices”)

As strings encontraram ao todo 62 artigos nas bases usadas, excluindo os 30 artigos duplicados dectados pelo Rayyan, a ferramenta usada para as seleçao primaria da ˜ literatura encontrada.

2.1.1. Criterios de Inclus ´ | ao e Exclus ˜ | aõ
Para orientar a seleçao dos artigos e a extraç ˜ | ao das informaç ˜ | oes, foram utilizadas as per- ˜
guntas de pesquisa mostradas abaixo:
1. Quais sao os m ˜ | etodos mais eficientes e amplamente utilizados para controlar a ´
tensao e corrente de placas fotovoltaicas usando PWM? ˜
2. Quais sao os m ˜ | etodos mais precisos e confi ´ | aveis para estimar o estado de carre- ´
gamento (SoC) de baterias, especialmente de chumbo-acido, em sistemas fotovol- ´ taicos autonomos? ˆ

3. Quais parametros e medidas s ˆ | ao essenciais para carregar uma bateria com ˜
eficiencia e segurança utilizando controle PWM? ˆ
4. Existem diferenças significativas no carregamento de baterias de lítio e chumbo-acido quando utilizadas em sistemas fotovoltaicos com controle PWM? ´
5. Qual e a efic ´ | acia do controle PWM em comparaç ´ | ao com outros m ˜ | etodos de con- ´
trole em sistemas fotovoltaicos?
6. Considerando a flexibilidade da arquitetura proposta, quais sao os desafios asso- ˜
ciados a sua implementaç ` | ao e manutenç ˜ | ao em um ambiente real? ˜

Com base nestas perguntas, regras para seleçao foram criadas e organizadas em ˜
uma tabela de criterios de inclus ´ | ao e exclus ˜ | ao de artigos, mostrado a seguir. ˜
Criterio ´ | Cumpre o Criterio ´ | Nao Cumpre ˜ o Criterio ´
Utiliza metodos para controlar a ´ tensao e corrente de placas ˜ fotovoltaicas usando PWM? | Proximo crit ´ erio. ´ | Exclusao. ˜
Utiliza metodos para estimar o estado ´ de carregamento (SoC) de baterias em sistemas fotovoltaicos autonomos? ˆ | Proximo crit ´ erio. ´ | Exclusao. ˜
Utiliza de baterias de chumbo-acido? ´ | Inclusao. ˜ | Proximo crit ´ erio. ´
Discute quais parametros e medidas s ˆ ao essenciais ˜ para carregar uma bateria com eficiencia ˆ e segurança utilizando controle PWM? | Inclusao. ˜ | Exclusao. ˜

### 2.1.2. Seleçao de Estudos ˜

A partir da leitura dos resumos dos artigos, e considerando as perguntas de pesquisa, foram analisados todos os 62 artigos. Destes, 17 artigos foram inclusos na revisao e ˜
43 artigos foram descartados. Os motivos para exclusao s ˜ | ao os seguintes: 13 artigos ˜
estao fora do escopo de pesquisa, 12 usam componentes errados, 10 aplicam m ˜ | etodos ´
diferentes, 8 nao s ˜ | ao relevantes para esta revis ˜ | ao e 2 n ˜ | ao foi possivel obter o PDF. ˜
A analise quantitativa de cada etapa no processo de seleç ´ | ao de artigos pode ser ˜
melhor visualizada no diagrama a seguir:

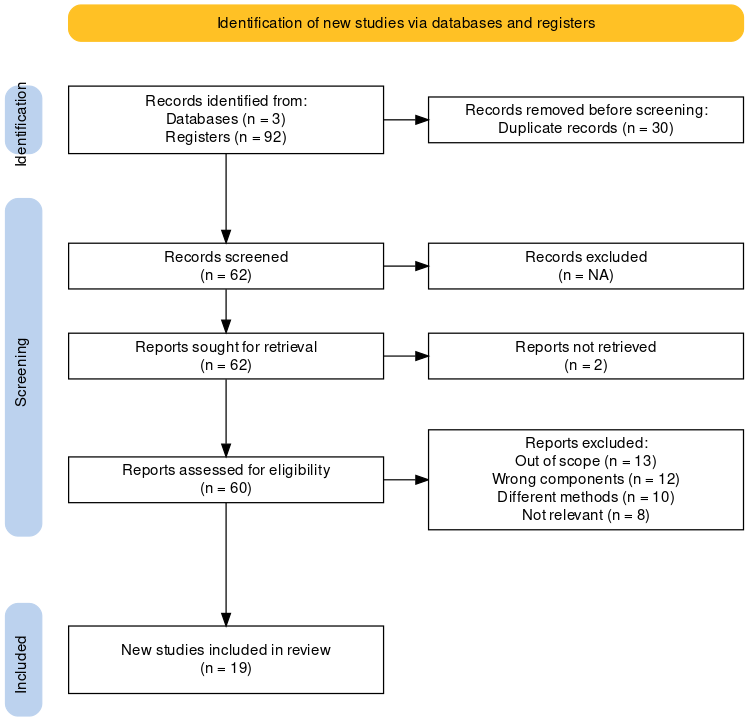
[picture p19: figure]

Figura 1. Diagrama gerado no PRISMA

### 2.2. Resultados e Discussaõ

### 2.2.1. Tipos de Baterias Estudadas

A predominancia das baterias de chumbo- ˆ | acido nos estudos reflete sua ampla utilizaç ´ | aõ
na industria e pesquisa. [Wang et al. 2021] exploraram a determinaç ´ | | | ao online do es- ˜
tado das baterias de chumbo-acido para a gest ´ | ao energ ˜ | etica de ve ´ | ículos. | No en-
tanto, baterias de lítio e VRLA tambem foram mencionadas, indicando uma diversi- ´ dade de aplicaçoes e contextos de pesquisa [Alvarez Anton et al. 2013, Faiz et al. 2021, ˜ Chmielewski et al. 2018, Lavety et al. 2019, Lin et al. 2016].

### 2.2.2. Metodos de Controle ´

Os metodos de controle variam desde t ´ | ecnicas tradicionais, como PWM, at ´ | e abor- ´
dagens mais inovadoras. [Faiz et al. 2021] utilizaram a Modulaçao por Largura de ˜ Pulso (PWM) em um controlador de carga solar, enquanto [Singh and Mishra 2013] propuseram um carregador bidirecional de bateria otimizado com feedback-clamped. Outros estudos, como [Dufo-Lopez et al. 2015, Victor et al. 2019, Antonov et al. 2019, Yoomak et al. 2018, Teo et al. 2013, Belarbi et al. 2019], tambem destacaram a im- ´
portancia e efic ˆ | acia de diferentes t ´ | ecnicas de controle para otimizar a carga da bateria. ´

### 2.2.3. Estimaçao do SoC ˜

A estimativa do SoC e crucial para a gest ´ | ao eficaz da bateria. [Wang et al. 2021] em- ˜
pregaram um algoritmo de estimativa colaborativa para determinar o estado das bate-
rias de chumbo-acido. Por outro lado, [Alvarez Anton et al. 2013] utilizaram M ´ | aquinas ´
de Vetores de Suporte para estimar o SoC de uma bateria de lítio. | Alem disso, ´
[Dufo-Lopez et al. 2015] e [Maithili et al. 2021] tambem abordaram a import ´ | ancia da es- ˆ
timativa precisa do SoC para garantir a eficiencia e longevidade da bateria. ˆ
2.2.4. Eficiencia Energ ˆ | etica ´
A eficiencia energ ˆ | etica ´ | e um pilar central nos estudos revisados. [Singh and Mishra 2013] ´
relataram eficiencias m ˆ | aximas de 90,24% e 92,7% em diferentes modos de operaç ´ | aõ
de seu prototipo. [Faiz et al. 2021] destacaram uma efici ´ | encia de 94% para carga de ˆ
bateria e 93% para carga total em seu controlador de carga solar. Outros estudos, como [Huang et al. 2010, Lin et al. 2016, Yoomak et al. 2018], tambem enfatizaram a ´
importancia da efici ˆ | encia energ ˆ | etica na gest ´ | ao de baterias. ˜

### 2.2.5. Desafios de Implementaçaõ

A implementaçao de sistemas de bateria eficientes n ˜ | ao est ˜ | a isenta de desafios. [Gies 2009] ´
explorou a necessidade de ventilaçao de g ˜ | as hidrog ´ | enio em equipamentos el ˆ | etricos con- ´
tendo baterias de chumbo-acido. Por outro lado, [Victor et al. 2019] discutiram a im- ´
portancia de escolher o controlador de carga correto para otimizar a efici ˆ | encia. Al ˆ | em´
disso, [Akbar et al. 2016] e [Teo et al. 2013] abordaram os desafios associados a modela- `
gem dinamica e otimizaç ˆ | ao de sistemas de geraç ˜ | ao de energia aut ˜ | onomos. ˆ
2.2.6. Tecnicas e Estrat ´ | egias de Carregamento ´

Diversas estrategias de carregamento foram exploradas nos estudos. [Lavety et al. 2019] ´
propos uma estrat ˆ | egia de carregamento de corrente constante multi-etapa para ba- ´
terias VRLA. [Lin et al. 2016] apresentou um sistema de carregamento de bateria
eficiente baseado em uma estrategia ideal de m ´ | ultiplos estados. | Enquanto isso, ´
[Belarbi et al. 2019] discutiu os limites operacionais dos controladores de carga da bateria, e [Yoomak et al. 2018] projetou um carregador solar que desafia varios n ´ íveis de irradiancia solar e temperatura para armazenamento de energia. ˆ

### 2.2.7. Aplicaçoes e Contextos de Pesquisa ˜

A diversidade de aplicaçoes e contextos de pesquisa em gest ˜ | ao de baterias ˜ | e evidente ´
nos estudos revisados. [Chmielewski et al. 2018] investigaram a aplicaçao de baterias em ˜ sistemas de armazenamento de energia renovavel, enquanto [Alvarez Anton et al. 2013] ´ focaram em sistemas de backup de energia para infraestruturas críticas. Alem disso, ´ [Huang et al. 2010] e [Akbar et al. 2016] exploraram a integraçao de baterias em micro- ˜
redes e sistemas de geraçao de energia distribu ˜ | ída, respectivamente.

### 2.2.8. Estrategias Avançadas de Carregamento ´

Alem das estrat ´ | egias tradicionais de carregamento, novas abordagens est ´ | ao sendo explo- ˜
radas para melhorar a eficiencia e a vida ˆ | util das baterias. [Lavety et al. 2019] introduziu ´
uma estrategia de carregamento adaptativo baseada em feedback para baterias de ´ | íon-
lítio. [Lin et al. 2016] propos um m ˆ | etodo de carregamento r ´ | apido que minimiza o estresse ´
termico na bateria. [Belarbi et al. 2019] e [Yoomak et al. 2018] discutiram estrat ´ | egias de ´
carregamento otimizadas para baterias em sistemas solares fotovoltaicos.
2.3. Conclusoes da Revis ˜ | aõ
A gestao eficiente de baterias ˜ | e fundamental para otimizar a integraç ´ | ao de fontes de ener- ˜
gia renovavel, como pain ´ | eis solares, em sistemas de armazenamento de energia. Este es- ´
tudo revisou extensivamente a literatura sobre gestao de baterias, modelagem, simulaç ˜ | ao e ˜
estrategias avançadas de carregamento. Com base nessa revis ´ | ao, podemos extrair insights ˜
cruciais para o projeto em questao, que visa desenvolver um controlador PWM usando ˜
MOSFET para uma bateria de chumbo acido estacion ´ | aria de 15V com um painel solar de ´
20W.
Estrategias de Carregamento: ´ | Como destacado por [Lavety et al. 2019], a
implementaçao de estrat ˜ | egias de carregamento adaptativo pode ser crucial para maxi- ´
mizar a eficiencia do carregamento da bateria de chumbo ˆ | acido, especialmente quando ´
alimentada por um painel solar de 20W. Considerando as variaçoes na geraç ˜ | ao de energia ˜
solar, um carregamento adaptativo pode ajustar dinamicamente a taxa de carregamento para garantir a saude da bateria. ´

Monitoramento e Feedback: A integraçao de sistemas de monitoramento, como ˜ proposto por [Lin et al. 2016], pode ser benefica para o projeto. Monitorar a temperatura ´
e outros parametros vitais da bateria pode ajudar a prevenir situaç ˆ | oes de estresse t ˜ | ermico ´
e prolongar a vida util da bateria. onfiguraç ´ | oes do controlador PWM para otimizar o ˜
desempenho da bateria.
Integraçao com Painel Solar: ˜ | O trabalho de [Belarbi et al. 2019] e
[Yoomak et al. 2018] sobre estrategias de carregamento para baterias em sistemas solares ´
fotovoltaicos e particularmente relevante. A implementaç ´ | ao de algoritmos que conside- ˜
rem a variaçao na geraç ˜ | ao de energia solar pode ajudar a otimizar o carregamento da ˜
bateria e garantir uma operaçao eficiente. ˜
Consideraçoes Finais: ˜ | O projeto proposto e uma combinaç ´ | ao de hardware e soft- ˜
ware que visa otimizar o armazenamento e a utilizaçao de energia solar. Com base na li- ˜
teratura revisada, e evidente que a combinaç ´ | ao de estrat ˜ | egias avançadas de carregamento, ´
monitoramento em tempo real e comunicaçao eficiente via MQTT pode levar a um sis- ˜
tema robusto e eficiente. Recomenda-se tambem a realizaç ´ | ao de testes extensivos em ˜
condiçoes variadas para validar e refinar o sistema proposto. ˜

### 3. Desenvolvimento do Projeto

Nesta seçao, apresentaremos a descriç ˜ | ao funcional e o diagrama de alto n ˜ | ível do sistema,
detalhando a estrutura e os requisitos fundamentais do projeto. Em seguida, exploraremos
a logica de controle e comunicaç ´ | ao do ESP, e por fim, o design e a navegabilidade do ˜
aplicativo movel e suas telas, oferecendo uma vis ´ | ao da interface do usu ˜ | ario. ´

### 3.1. Descriçao Funcional ˜

A descriçao funcional tem o objetivo de descrever todas as caracter ˜ | ísticas e restriçoes do ˜
projeto. Essa descriçaõ e comumente dividida em requisitos funcionais, requisitos n ´ | aõ
funcionais e regras de negocio. ´

### 3.1.1. Requisitos Funcionais

Os requisitos funcionais descrevem as funçoes espec ˜ | íficas que um sistema deve ter. Eles
definem o que o sistema deve fazer do ponto de vista do usuario ou de outros componen- ´
tes do sistema. Geralmente, os requisitos funcionais sao expressos em termos de aç ˜ | oes ou ˜
operaçoes que o sistema deve realizar, bem como em termos de entradas e sa ˜ | ídas espera-
das. Sao requisitos funcionais do projeto Sunchaser: ˜
1. Mediçao de Corrente e Tens ˜ | ao: ˜
- O sistema deve medir a corrente entre o painel solar e a bateria, e entre a bateria e a carga usando sensores INA219.
- Deve medir as tensoes do painel e da bateria. ˜
- Os sensores INA219 devem ser calibrados atraves de uma m ´ | edia de dez ´
mediçoes para minimizar o ru ˜ | ído.
- O ESP32 deve monitorar as mediçoes de tens ˜ | ao e corrente. ˜
2. Controle de Carga:
- O sistema deve controlar a carga de uma bateria de chumbo-acido de 12V ´ usando um painel solar e um ESP32.
- A carga deve ser controlada via PWM utilizando um MOSFET IRF9640.
- O sistema deve ter a capacidade de ligar/desligar a carga atraves de um ´ rele.´
- O ESP32 deve abrir o rele para interromper o uso da bateria pela carga ´ caso a corrente entre a bateria e a carga atingir ou exceder 1.1A.
3. Segurança e Precisao: ˜
- O sistema deve garantir a precisao das mediç ˜ | oes de tens ˜ | ao atrav ˜ | es de divi- ´
sores de tensao. ˜
- Diodos zener devem ser utilizados para proteger o ESP32 contra sobretensoes. ˜
4. Gerenciamento de Dados:
- O ESP32 deve armazenar dados de mediçao em uma mem ˜ | oria cache antes ´
de envia-los para o broker. ´
- Os dados do cache devem ser transferidos para a memoria de longo prazo ´ apos o envio, e o cache deve ser limpo. ´
5. Aplicativo Movel: ´
- Tela Sem Conexao: ˜ | Exibida quando o ponto de acesso ao servidor do ESP
esta desconectado, com um bot ´ | ao para tentar a conex ˜ | ao. ˜
- Tela Home: Exibida quando conectado, permite aos usuarios ver os valo- ´
res da ultima mediç ´ | ao, solicitar uma nova mediç ˜ | ao e acessar outras opç ˜ | oes. ˜
- Tela de Graficos: ´ | Acessível atraves da barra de opç ´ | oes, permite visualizar ˜
diferentes medidas.

- Tela de Configuraçoes: ˜ Permite aos usuarios ajustar o intervalo entre as ´ mediçoes, o intervalo entre os envios ao servidor e o tempo de dados ar- ˜ mazenados na memoria de longo prazo. ´
6. Integraçao e Compatibilidade: ˜
- O sistema deve ser integrado ao sistema existente do pluviometro e ao ˆ broker MQTT ja estabelecido. ´
- Deve aderir aos protocolos de comunicaçao preestabelecidos para garantir ˜ compatibilidade e interoperabilidade.
7. Gestao de Conectividade: ˜
- O WiFi e o Ponto de Acesso ao servidor do ESP devem permanecer desli-
gados ate que sejam necess ´ | arios. ´
- O WiFi deve ser ativado de acordo com o intervalo estabelecido para as tentativas de envio ao servidor.
- O ponto de acesso ao servidor do ESP deve ser ativado apenas quando um interruptor físico na placa for acionado, gerando uma interrupçao no ˜ ESP32 e colocando-o no loop de comunicaçao do ponto de acesso ao ser- ˜ vidor do ESP.
- O Ponto de Acesso ao servidor do ESP deve ser desligado quando a chave estiver desligada.

### 3.1.2. Requisitos Nao Funcionais ˜

Os requisitos nao funcionais descrevem as caracter ˜ | | ísticas do sistema que afetam a quali-
dade, o desempenho, a segurança e outros aspectos do sistema que nao est ˜ | ao diretamente ˜
relacionadas as funç ` | oes espec ˜ | íficas. Estes requisitos se concentram em qualidades do sis-
tema, como escalabilidade, disponibilidade, usabilidade, desempenho, segurança e confi-
abilidade. Os requisitos nao funcionais podem ser mais dif ˜ | íceis de medir e testar do que
os requisitos funcionais, pois muitas vezes envolvem criterios subjetivos. S ´ | ao requisitos ˜
nao funcionais do projeto Sunchaser: ˜
1. Hardware:
- A placa de circuito impresso personalizada deve ser de dupla face e feita de fenolite.
- Trilhas de 60th para ser possível fazer PCBs com o metodo de trans- ´
ferencia t ˆ | ermica sem erros e para que elas n ´ | ao descolem da placa de feno- ˜
lite ao serem soldadas.
2. Operacional:
- O sistema naõ possui mecanismos específicos para lidar com variaçoes ˜
extremas de temperatura ou interferencias eletromagn ˆ | eticas externas. ´
- Esta destinado a operar em ´ | | areas remotas e deve ser alojado em uma caixa ´
protetora contra os elementos.
3. Manutençao e Atualizaç ˜ | | oes: ˜
- O sistema naõ requer gestao espec ˜ | ífica do desgaste da memoria flash. ´
- As atualizaçoes de software, se necess ˜ | arias, devem ser realizadas manual- ´
mente.
4. Segurança:

- Deve utilizar logicas booleanas integradas para alertar os usu ´ | arios sobre ´
possíveis problemas ou falhas.
- O layout da placa deve ser projetado para minimizar a interferencia no ˆ ESP32 causada pelo chaveamento PWM do circuito de potencia. ˆ
5. Desempenho:
- O sistema deve garantir a eficiencia energ ˆ | etica e a segurança operacional. ´
- O ESP32 e respons ´ | avel por garantir que a bateria nunca atinja um n ´ | ível
criticamente baixo e por administrar o carregamento seguro e eficiente da bateria.

### 3.1.3. Regras de Negocio ´

Regras de negocio s ´ | ao diretrizes que estabelecem os procedimentos e as restriç ˜ | oes que ˜
governam as operaçoes e o comportamento de um sistema. Elas desempenham um papel ˜ fundamental na definiçao de como um sistema opera e interage com outros sistemas. As ˜
regras de negocio orientam como o software deve funcionar e interagir com os usu ´ | arios e ´
outros sistemas. Sao regras de neg ˜ | ocio do projeto Sunchaser: ´
1. Controle de Energia:
- A energia do painel solar so deve ser usada para carregar a bateria quando ´ a condiçao de carga for adequada, conforme determinado pelo ESP32. ˜
- O sistema deve colocar o carregamento em estado de Flutuaçaõ para evitar sobrecarga.
2. Mediçoes: ˜
- As mediçoes de corrente e tens ˜ | ao devem ser realizadas em intervalos es- ˜
pecíficos, conforme configurado no aplicativo movel. ´
- As mediçoes devem ser calibradas para garantir precis ˜ | ao e minimizar o ˜
ruído.
3. Conectividade:
- O WiFi deve ser ativado apenas durante os períodos de envio de dados ao servidor, conforme configurado no aplicativo movel. ´
- O ponto de acesso ao servidor do ESP so pode ser ativado por meio de ´ um interruptor físico na placa e deve ser desativado quando o interruptor estiver desligado.
- O sistema deve ser compatível com o sistema existente do pluviometro e o ˆ broker MQTT, aderindo aos protocolos de comunicaçao preestabelecidos. ˜
4. Aplicativo Movel: ´
- O aplicativo movel deve permitir aos usu ´ | arios visualizar dados de mediç ´ | aõ
e configurar intervalos de mediçao e envio de dados ˜
- O aplicativo so pode se conectar ao ESP32 via ponto de acesso ao servidor ´ do ESP quando o interruptor físico na placa estiver ativado.
5. Segurança:
- Mecanismos de segurança, como diodos zener e dividores de tensao, de- ˜ vem ser implementados para proteger o ESP32 e outros componentes sensíveis de sobretensoes. ˜
6. Armazenamento de Dados:

- Os dados de mediçao devem ser armazenados temporariamente em um ˜ cache antes de serem enviados ao broker MQTT.
- Apos o envio, os dados devem ser transferidos para a mem ´ | oria de longo ´
prazo no ESP32.

### 3.2. Diagrama de Alto Nível do Sistema

A Figura 2 ilustra o Diagrama de Alto Nível do Sistema, proporcionando uma visaõ simplificada da arquitetura integrada do projeto em desenvolvimento e do projeto do
pluviometro existente. Neste diagrama, os componentes em ˆ | | | roxo representam as par-
tes que estao sendo desenvolvidas neste projeto, focadas no ESP, na placa de controle e ˜
no aplicativo mobile. Eles sao respons ˜ | aveis pelo gerenciamento e controle eficiente da ´
energia, garantindo operaçao otimizada e segura. ˜ | Os elementos em cinza, por outro
lado, sao componentes j ˜ | a existentes do ´ | projeto do pluviometro ˆ | , incluindo o broker, o
servidor e o site, que facilitam a comunicaçao e o armazenamento de dados. ˜

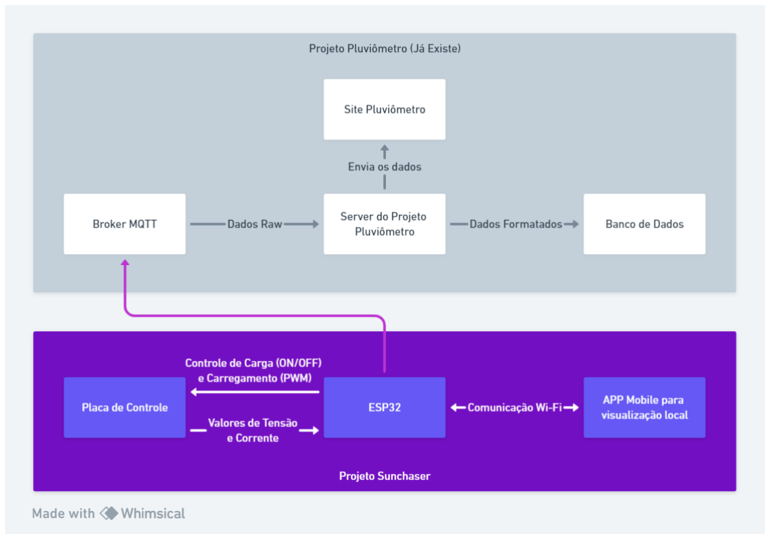
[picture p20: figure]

Figura 2. Diagrama do Sistema de Alto Nível

### 3.3. Funcionamento e Diagramas do programa do ESP

A logica de controle e comunicaç ´ | ao do ESP ˜ | e detalhadamente ilustrada atrav ´ | es de uma ´
serie de fluxogramas, cada um destacando um aspecto espec ´ | | | ífico do funcionamento in-
terno do ESP.

Na Figura 3, e apresentada a estrutura principal do programa do ESP. O ESP opera ´
em dois loops principais simultaneos: o loop de controle e o loop de WiFi, al ˆ | | | em de uma ´
interrupçao ativada fisicamente, que gera o ponto de acesso (AP) ao servidor do ESP. ˜

A Figura 4 detalha o loop de controle. Este loop inicia requisitando uma mediçao, ˜ processa os dados coletados para ajustar o PWM conforme os estados de carga da bate-
ria e, em seguida, altera o duty cycle do PWM antes de requisitar a proxima mediç ´ | ao, ˜
respeitando o intervalo de tempo definido no aplicativo.
Esse controle e feito por software atrav ´ | es da classe ´ | BatteryControl, que realiza o
controle de carregamento da bateria atraves dos seguintes m ´ | etodos: ´
PWM init() e respons ´ | avel por inicializar o PWM (Pulse Width Modulation) para ´
controlar a tensao de carga da bateria. Ele configura o pino ˜ | S2 Pin, o qual e o pino que ´
controla o rele que conecta a carga, como sa ´ | ída e configura as funcionalidades do PWM

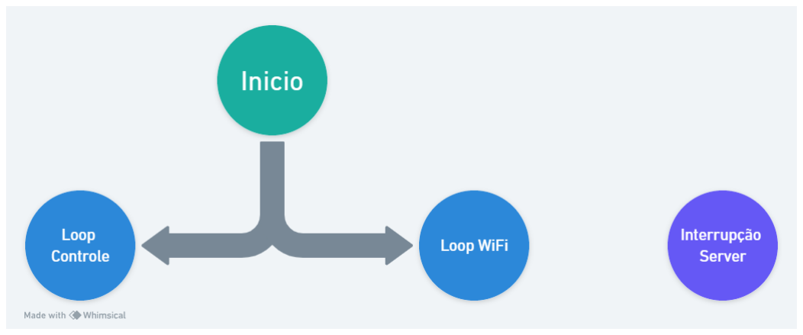
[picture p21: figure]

Figura 3. Fluxograma Principal do ESP

usando a funçaõ ledcSetup(). Em seguida, o canal PWM e anexado ao pino ´ | PWM Pin
usando a funçaõ ledcAttachPin().
changeDutyCycle() e respons ´ | avel por alterar o ciclo de trabalho do sinal PWM. ´
Ele verifica se o ciclo de trabalho esta acima de 255 e o limita para 255. Da mesma forma, ´
se o ciclo de trabalho estiver abaixo de 0, ele e limitado para 1. Em seguida, o m ´ | etodo usa ´
a funçaõ ledcWrite() para definir o ciclo de trabalho do canal PWM.
check error() e respons ´ | avel por verificar o erro entre a tens ´ | ao da bateria e um ˜
valor de referencia. Se o erro for maior que 0, o ciclo de trabalho ˆ | e diminu ´ | ído em 1 para
reduzir a tensao de carga. Se o erro for menor que 0, o ciclo de trabalho ˜ | e aumentado em ´
1 para aumentar a tensao de carga. ˜
bulk stage() e respons ´ | avel por definir o ciclo de trabalho como 255, que repre- ´
senta a fase de carga em massa da bateria. Ele chama o metodo ´ | changeDutyCycle() para
atualizar o ciclo de trabalho.
absorption stage() e respons ´ | avel por manter a tens ´ | ao da bateria com um valor ˜
de referencia chamado ˆ | AV (Absorption Voltage: 12 V) durante a fase de absorçao. Ele ˜
calcula o erro entre a tensao da bateria e AV, chama o m ˜ | etodo ´ | check error() para ajustar
o ciclo de trabalho e, em seguida, chama o metodo ´ | changeDutyCycle() para atualizar o
ciclo de trabalho.
float stage() e respons ´ | avel por manter a tens ´ | ao da bateria no n ˜ | ível de tensao de ˜
flutuaçaõ FV (Float Voltage: 10V) durante a fase de flutuaçao. Ele calcula o erro entre ˜
a tensao da bateria e FV, chama o m ˜ | etodo ´ | check error() para ajustar o ciclo de trabalho
e, em seguida, chama o metodo ´ | changeDutyCycle() para atualizar o ciclo de trabalho.
Contudo, como o datasheet da Bateria que utilizamos nao possui indicaç ˜ | ao do uso de uma ˜
tensao de Flutuaç ˜ | ao, seguimos as recomendaç ˜ | oes do Fabricante e mantivemos a Tens ˜ | aõ
na bateria na Absorption Voltage de 12V.
charging control() e respons ´ | avel por controlar o processo de carga da bateria. Ele ´
le a corrente da bateria e a tens ˆ | ao da bateria usando o objeto ˜ | read sensors da classe Sen-
sors. Em seguida, ele verifica as condiçoes para determinar em qual fase de carga a bateria ˜
esta e chama os m ´ | etodos correspondentes ´ | (bulk stage(), absorption stage(), float stage())
para ajustar o ciclo de trabalho do PWM.
A funçaõ load connection() e respons ´ | avel por controlar a conex ´ | ao da carga com ˜

a bateria, verificando a tensao e a corrente por meio do objeto ˜ | read sensors. Ela decide
sobre a desconexao ou reconex ˜ | ao da carga com base em duas condiç ˜ | oes espec ˜ | íficas: a
funçao desconecta a carga se a tens ˜ | ao da bateria for inferior ˜ | a tens ` | ao m ˜ | ínima de descarga
de 9V, conforme especificado pelo fabricante, ou se a corrente exceder o limite maximo ´
de 1.1A. Esse controle e realizado atrav ´ | es da atuaç ´ | ao no pino ˜ | S2 Pin.
battery loop() e respons ´ | avel por executar o loop principal do controle da bate- ´
ria. Ele verifica se o processo de carga ja foi iniciado. Se n ´ | ao, ele define o ciclo de ˜
trabalho como 255 para a fase de carga em massa. Em seguida, ele chama os metodos ´ charging control() e load connection() para controlar o processo de carga e a conexao da ˜ carga, respectivamente.
stopCharging() e respons ´ | avel por interromper o processo de carga da bateria. Ele ´
define o ciclo de trabalho como 0 para desligar completamente o PWM.
O codigo de funcionamento completo pode ser visto na p ´ | agina do GitHub ´
| | | | 1 do
projeto, assim como todas as outras funcionalidades do sistema criado.


Figura 4. Fluxograma do Loop de Controle do ESP

O loop de WiFi, como mostrado na Figura 5, e respons ´ | avel pela comunicaç ´ | ao com ˜
o broker. Ele aguarda o tempo definido, tenta enviar os dados armazenados no cache para o broker e, se bem-sucedido, move os dados para a memoria de longo prazo e limpa o ´ cache.
A interrupçao para o AP do servidor do ESP ˜ | e detalhada na Figura 6. Quando ´
ativada, o ESP entra em um loop onde aguarda requisiçoes do aplicativo m ˜ | ovel, podendo ´
enviar dados, realizar mediçoes manuais ou alterar configuraç ˜ | oes. As rotas da API REST ˜
no Access Point do ESP32 pode ser vista na Tabela 1

1https://github.com/TarefasUFSC/Sunchaser-Solar Charging System

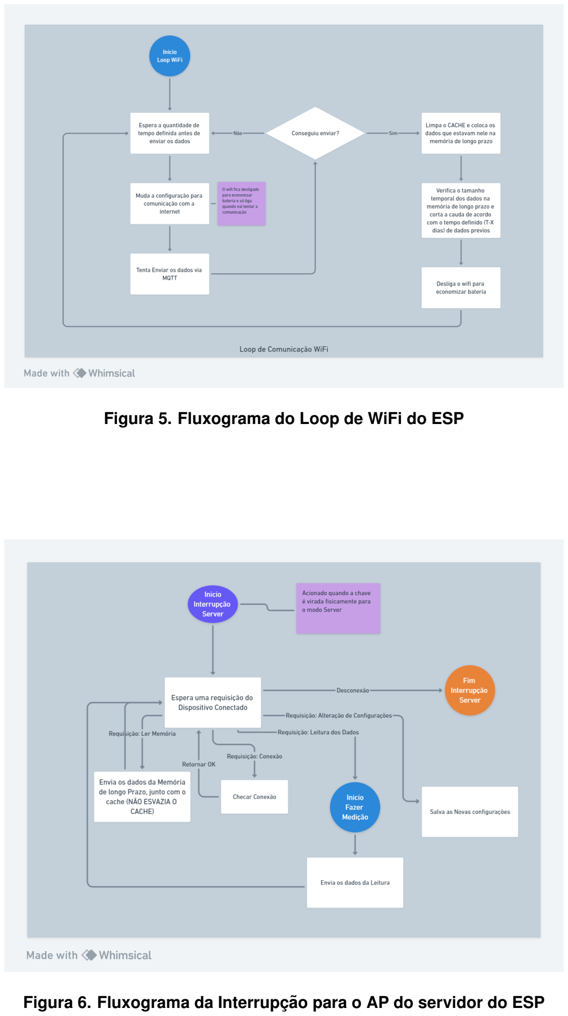
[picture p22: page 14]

Figura 5. Fluxograma do Loop de WiFi do ESP

Figura 6. Fluxograma da Interrupçao para o AP do servidor do ESP ˜

Tipo | Rota | Query Params | Body | Retorno | Observaçoes ˜
GET | /cache | page: Numeric | - | JSON: Lista de leituras do cache, total de itens, itens por pagina ´ (10) | Maximo de ´ 10 itens por pagina ´
GET | /ltm | page: Numeric | - | JSON: Lista de leituras da memoria, total de ´ itens, itens por pagina (10) ´ | Maximo de ´ 10 itens por pagina ´
POST | /reading | - | - | JSON: Novas mediçoes ˜ | -
POST | /settings | - | JSON: Novas configuraçoes ˜ | - | O app verifica o sucesso pela res-posta do status code
GET | /settings | - | - | JSON: Configuraçoes ˜ atuais | -
GET | /check | - | - | String: ”conec-tado!” | Utilizado para ve-rificar a conexaõ com o ESP
Tabela 1. Descriçao das Operaç ˜ | oes e Rotas ˜

3.3.1. Gestao da Mem ˜ | oria do ESP ´
A gestao da mem ˜ | oria do ESP ´ | e ilustrada em um conjunto adicional de diagramas. A Fi- ´
gura 7 mostra o preenchimento do cache durante as mediçoes. A Figura 8 ilustra a trans- ˜
ferencia de dados do cache para a mem ˆ | oria de longo prazo durante o envio bem-sucedido ´
ao broker. A Figura 9 destaca que as operaçoes ao servidor do ESP n ˜ | ao afetam o cache ˜
ou a memoria de longo prazo, mas podem acessar e transmitir os dados armazenados. ´

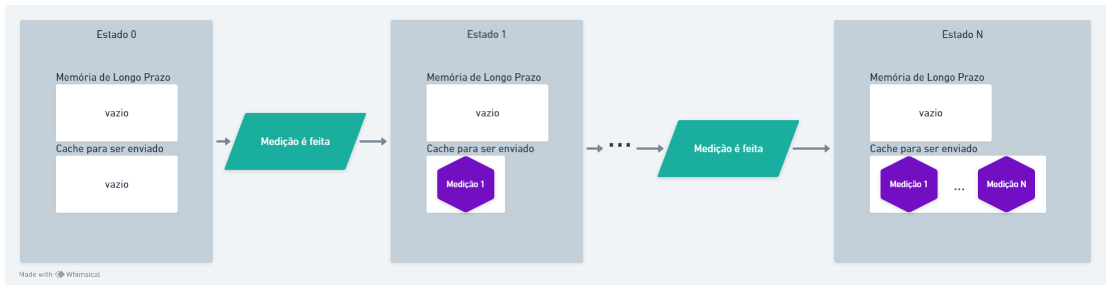
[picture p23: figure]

Figura 7. Diagrama da Memoria do ESP durante as Mediç ´ | oes ˜

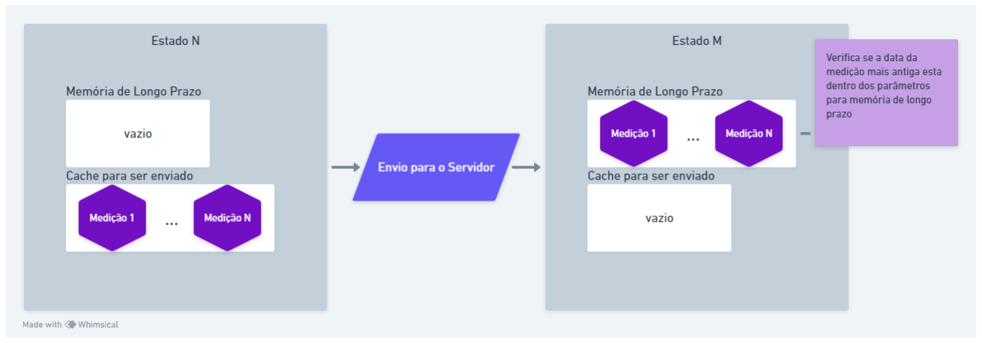
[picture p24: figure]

Figura 8. Diagrama da Memoria do ESP durante o Envio ao Servidor ´

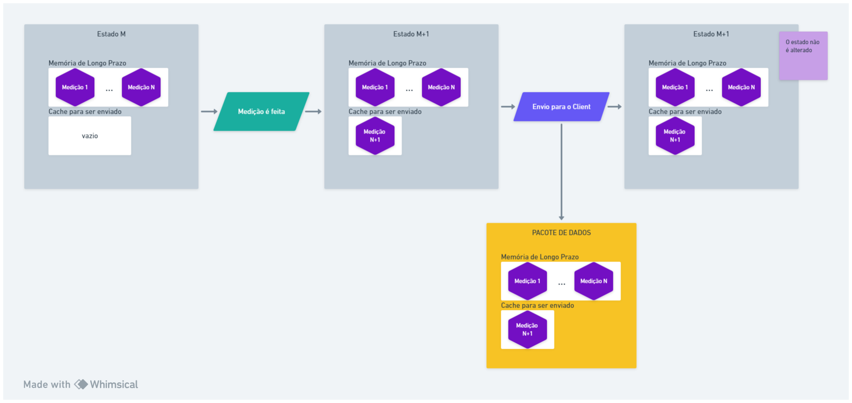
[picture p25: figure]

Figura 9. Diagrama da Memoria do ESP durante a Comunicaç ´ | ao com o servidor ˜
do ESP

### 3.4. Funcionamento e Diagramas do Aplicativo Mobile

O aplicativo movel, cujo fluxograma de navegaç ´ | aõ e mostrado na Figura 10, ´ | e projetado ´
para oferecer acesso local aos dados de carregamento atraves de um ponto de acesso ao ´

servidor gerado localmente no ESP. A primeira tela solicita ao usuario que estabeleça uma ´
conexao com o servidor do ESP. Uma vez conectado, o usu ˜ | ario ´ | e levado para a tela inicial, ´
onde pode navegar para outras seçoes do aplicativo que oferecem insights detalhados e ˜ visualizaçoes gr ˜ aficas dos dados de carregamento. ´


Figura 10. Fluxograma de Navegaçao no Aplicativo Mobile ˜

### 3.4.1. Design Final das Telas do Aplicativo Mobile

As Figuras 11 a 14 mostram o design final das telas do aplicativo movel. A Tela 1 ´ | é
a interface inicial onde os usuarios s ´ | ao solicitados a conectar o aplicativo ao ESP. Uma ˜
vez estabelecida a conexao, os usu ˜ | arios s ´ | ao direcionados para a Tela 2, a tela inicial, ˜
que oferece uma visao geral das leituras mais recentes e opç ˜ | oes para navegar para outras ˜
seçoes do aplicativo. ˜
A Tela 3 apresenta graficos detalhados das leituras de carregamento. Os usu ´ | arios ´
podem selecionar diferentes metricas atrav ´ | es de um menu dropdown para visualizar ´
graficos espec ´ | íficos. A navegabilidade entre as telas e facilitada por uma barra de menu ´
na parte inferior, permitindo aos usuarios alternar facilmente entre as diferentes seç ´ | oes do ˜
aplicativo.

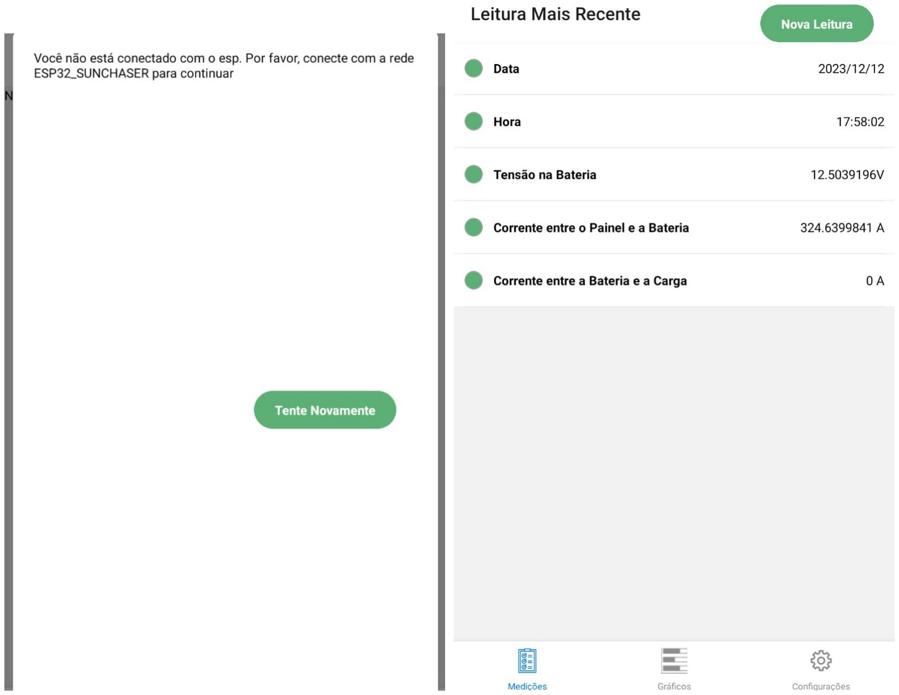
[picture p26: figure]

Figura 11. Tela Sem
Conexaõ

Figura 12. Home com
Leitura mais Recente

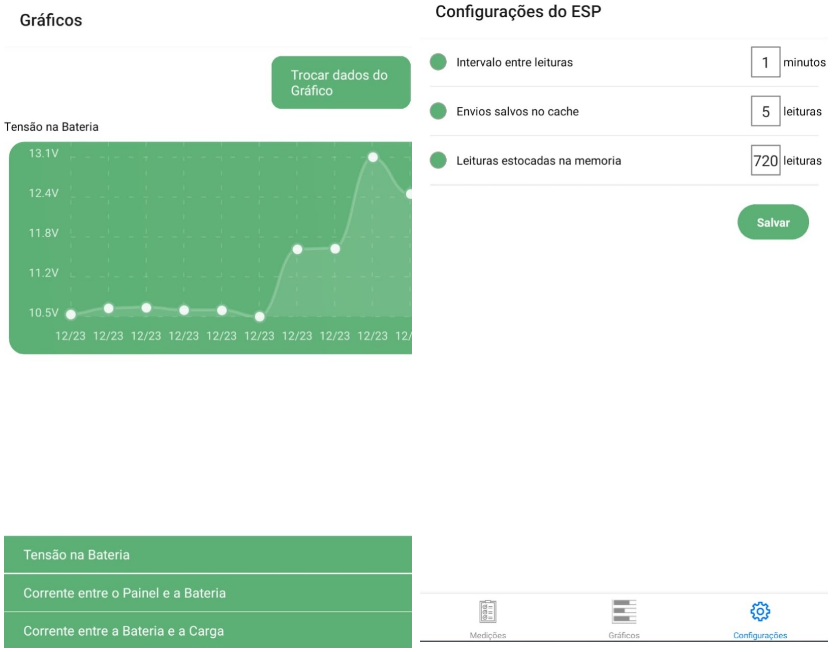
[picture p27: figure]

Figura 13. Graficos ´
de Leituras

Figura 14. Tela de
Configuraçoes ˜

Figura 15. Design Final das Telas do Aplicativo Mobile

### 3.5. Desenvolvimento da Placa de Controle

A placa de controle foi desenvolvida utilizando Proteus 8.9, com o intuito de facilitar
a implementaçao pr ˜ | atica do projeto. Esta placa engloba todos os circuitos e componen- ´
tes necessarios para atingir os objetivos do projeto. Ela se conecta ao ´ | Painel Solar e à
Bateria, incluindo tambem um conector para uma ´ | Saída para Carga de Alta Potencia ˆ | ,
controlada por um switch.
O circuito e respons ´ | avel por regular o carregamento da bateria a partir da energia ´
solar, utilizando um PWM controlado por um MOSFET Canal-P IRF9640. Alem disso, ´
gerencia o uso da bateria na carga, atraves de um rel ´ | e, que se abre quando a tens ´ | ao na ˜
bateria esta muito baixa ( ´ | LDV no codigo) ou quando a corrente excede o limite seguro ´
para a bateria (LDC no codigo). ´

Inicialmente, o circuito completo, incluindo as conexoes para o ESP, os INA’s, ˜
reguladores e controles de potencia, foi implementado em uma ˆ | unica placa de fenolite de ´
dupla face, produzida na UFSC de Florianopolis. Contudo, enfrentamos problemas du- ´
rante os testes, cujas causas nao foram identificadas. Isso nos levou a optar pela divis ˜ | ao do ˜
circuito em placas modulares, com objetivos específicos, facilitando assim a identificaçaõ
e correçao de erros. A divis ˜ | ao modular est ˜ | a ilustrada no diagrama da figura 16. ´

As placas desenvolvidas incluem:

- Placa do ESP e Sensores (Figura 17): A placa principal, contendo dois INA219 para medir as correntes entre o Painel Solar e a Bateria, e entre a Bateria e a Carga. Esta placa controla a Placa de Controle de Descarga e Carregamento.
- Placa de Controle de Carregamento PWM (Figura 18): Possui conexoes para o ˜
Painel Solar e para a Bateria, alem de uma conex ´ | ao para o INA219 localizado na ˜
Placa do ESP e Sensores.
- Placa de Controle de Descarga com Rele ( ´ Figura 19): Conecta-se a Bateria e ` | à
carga, controlando a abertura ou fechamento desta conexao, conforme a tens ˜ | ao e ˜
a corrente adequadas para a bateria. Dispoe tamb ˜ | em de uma sa ´ | ída de tensao da ˜
bateria para a placa de Reguladores e uma saída para conectar o INA219 da Placa do ESP e Sensores.
- Placa de Reguladores de Tensao ( ˜ | Figura 20): Recebe a tensao da Bateria, forne- ˜
cendo tensao est ˜ | avel de 5V, 9V e 12V. ´

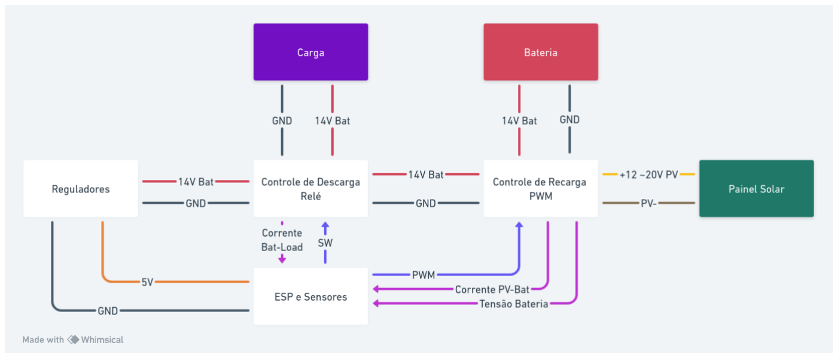
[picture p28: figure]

Figura 16. Diagrama da Divisao das Placas de Forma Modular ˜

### 3.5.1. Placa do ESP e Sensores


Figura 17. Circuito no Proteus da Placa do ESP e Sensores

A Figura 17 ilustra o circuito da Placa do ESP e Sensores no Proteus. Esta placa é
essencial para a conexao dos sensores INA219, configurados nos endereços ˜ | | 0x40 e 0x41.
Ela tambem inclui divisores de tens ´ | ao, protegidos por diodos Zener, garantindo que o ESP ˜
leia as tensoes da bateria e do painel solar de forma segura. Outro componente importante ˜ nesta placa e a chave que alterna o comportamento do ESP entre Cliente e Servidor WiFi. ´
A implementaçao desta placa foi crucial para o diagn ˜ | ostico de dois problemas es- ´
pecíficos. Primeiramente, observamos que o uso do pino 33 para interrupçao, que faz ˜ parte do ADC1, interferia nas leituras do painel solar e da bateria. Isso ocorria porque o circuito de pulldown aplicava 5V ao pino 33, prejudicando as leituras analogicas do Con- ´
versor Analogico Digital do ESP. Al ´ | em disso, constatamos que, ao empregar a biblioteca ´
WiFi.h do ESP32, torna-se impossível a utilizaçao de qualquer pino do ADC2. ˜

A Tabela 2 detalha os pinos utilizados no ESP:

### 3.6. Placa de Controle de Carregamento PWM

O circuito de controle de carregamento PWM e detalhadamente representado na ´ | Figura

### 18. Este utiliza um MOSFET Canal-P, especificamente o modelo IRF9640, para gerir

o controle PWM da corrente entre o Painel Solar e a Bateria. A escolha do Canal P é estrategica, visto que o Projeto SUNCHASER adota um sistema de controle PWM em ´
serie para o carregamento. Como o circuito apresenta duas fontes de tens ´ | ao, apenas um ˜
MOSFET do tipo Canal P pode efetivamente gerir a corrente em serie. Isso se deve ao ´ fato de que o MOSFET Canal-N exige que o seu terminal Source esteja conectado ao Ground, o que, neste caso, resultaria em um curto-circuito.
Alem disso, o comportamento do Gate do MOSFET ´ | e tal que ele se torna con- ´
dutor (”abre”) quando a tensao entre o Gate e o Source ˜ | e 0V, e se torna n ´ | ao-condutor ˜

Pino (Nome no Codigo) ´ | Numero do ´ Pino GPIO | Arquivo de Declaraçaõ | Observaçoes ˜
PWM Pin | 16 | BatteryControl.h | Utilizado para controle PWM.
S2 Pin | 26 | BatteryControl.h | -
interrupt pin | 33 | communicator.h | Nao deve receber 5V para ˜ evitar problemas com ADC1.
Battery Voltage Pin | 39 | Sensors.h | Pino de leitura de tensao da ˜ bateria, deve estar no ADC1.
Solar Voltage Pin | 34 | Sensors.h | Pino de leitura de tensao do ˜ painel solar, deve estar no ADC1.
INA219 Sensor1 SCL | 11 | Obrigatorio ´ | SCL do primeiro sensor INA219.
INA219 Sensor1 SDA | 10 | Obrigatorio ´ | SDA do primeiro sensor INA219.
INA219 Sensor2 SCL | 11 | Obrigatorio ´ | SCL do segundo sensor INA219.
INA219 Sensor2 SDA | 10 | Obrigatorio ´ | SDA do segundo sensor INA219.

Tabela 2. Pinagem do ESP no Projeto SUNCHASER

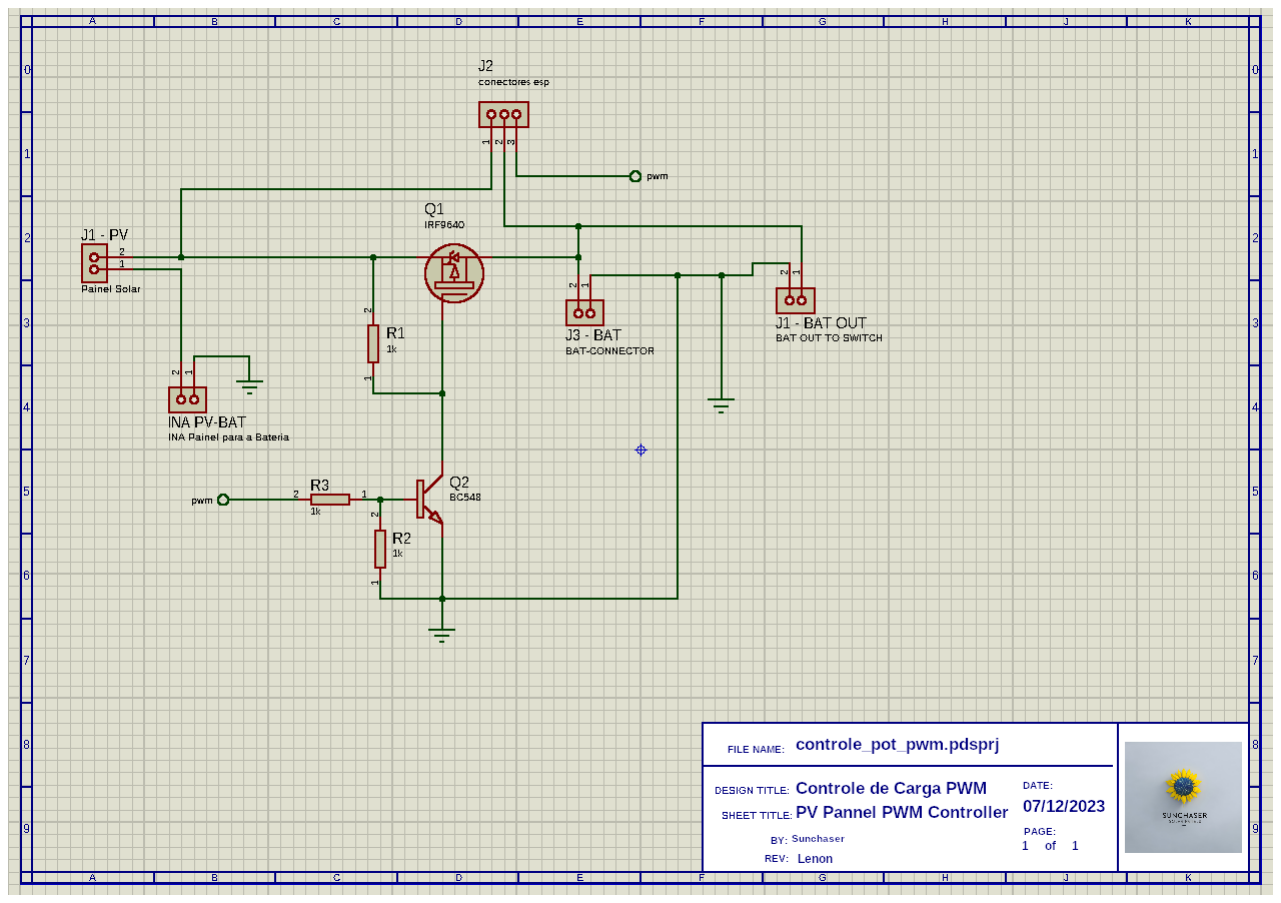
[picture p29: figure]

Figura 18. Circuito no Proteus da Placa de Controle de Carregamento PWM

(”fecha”) com uma tensao de ˜ | -15V (quinze volts negativos) entre o Gate e o Source. Essa
característica e descrita pela equaç ´ | ao: ˜

Vg − Vs

Para adequar o sinal PWM gerado pelo ESP ao controle do MOSFET, foi implementado um circuito inversor utilizando um transistor BC548. Este circuito converte o sinal PWM de forma a controlar efetivamente o MOSFET.

Durante os testes desta placa, identificou-se uma peculiaridade: o circuito naõ opera conforme o esperado quando o dispositivo conectado ao terminal da Bateria naõ possui uma carga significativa. Exemplificando, uma bateria convencional, devido a sua ` capacidade de ser recarregada e de demandar corrente, apresenta uma resistencia interna ˆ inerente. No entanto, ao substituir a bateria por uma fonte de bancada, que atua exclusivamente como um gerador de tensao e corrente sem consumir corrente do circuito, o ˜ comportamento do sistema se torna anormal. Para contornar essa situaçao, sempre que ˜
uma fonte de bancada for utilizada no lugar de uma bateria, e recomend ´ | avel a inclus ´ | ao de ˜
uma carga em paralelo com o circuito. No nosso caso, utilizamos um resistor de 1k5 ohm para esta finalidade.

### 3.6.1. Placa de Controle de Descarga com Relé


Figura 19. Circuito no Proteus da Placa de Controle de Descarga

O circuito de controle de descarga com relé e ilustrado na ´ | Figura 19. Este circuito
incorpora um diodo 1N4004, cuja funçaõ e proteger contra a corrente reversa gerada pela ´
transiçao de estados do solenoide do rel ˜ | e. Tal solenoide ´ | e capaz de gerar uma tens ´ | aõ
transiente extremamente alta (teoricamente infinita) durante a mudança de estado, o que demanda a proteçao mencionada. ˜

### 3.6.2. Placa de Reguladores de Tensaõ

A Placa de Reguladores de Tensao, representada na ˜ | Figura 20, emprega reguladores de
tensaõ 7805, 7809 e 7812 para converter uma tensao de entrada superior a 12V nas tens ˜ | oes ˜
de saída de 5V, 9V e 12V. Alem disso, a placa integra um diodo 1N4004 para prevenir a ´ corrente reversa que pode ser gerada pelo ESP, especialmente quando este e alimentado ´ simultaneamente por uma conexao USB e pelos 5V fornecidos por esta placa. ˜


Figura 20. Circuito no Proteus da Placa de Reguladores

### 3.6.3. Unificaçao das Placas Modulares Com os Problemas Corrigidos ˜

Apos a conclus ´ | ao dos testes em todas as placas modulares e a resoluç ˜ | ao de todos os ˜
problemas, procedemos a unificaç ` | ao dos circuitos em uma ˜ | unica placa. Devido ´ | a comple- `
xidade e ao tamanho significativamente maior desta placa unificada, tornou-se inviavel a ´
confecçao em uma ˜ | unica camada de cobre, sendo necess ´ | ario o uso de, no m ´ | ínimo, duas
camadas. O circuito completo desta placa unificada e apresentado na ´ | Figura 21, e o seu
layout de Placa de Circuito Impresso (PCB) e exibido na ´ | Figura 22.

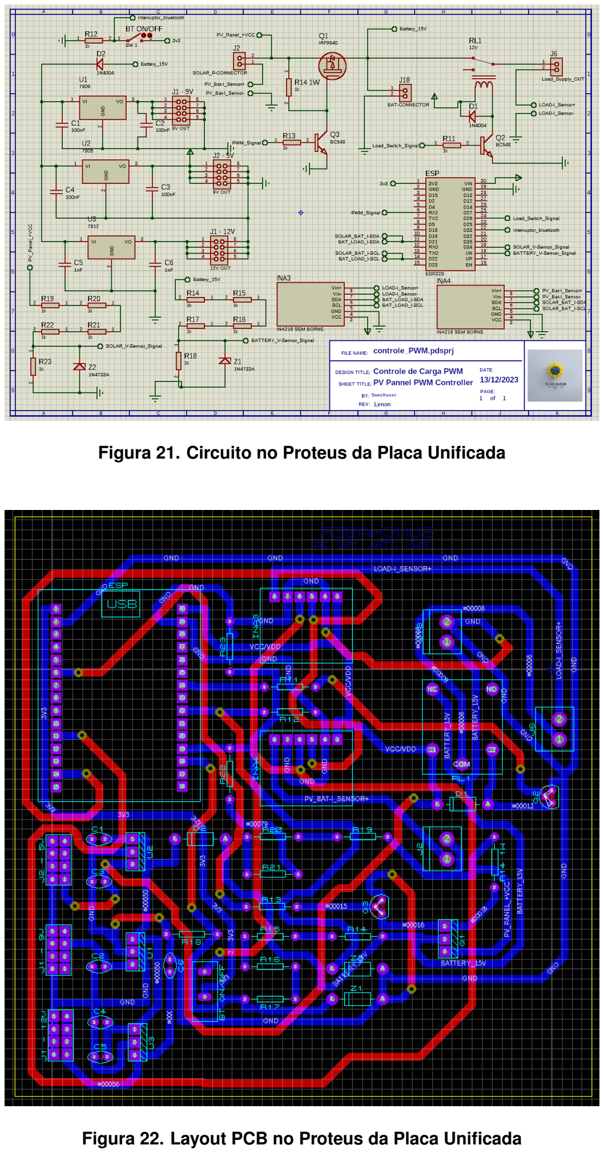
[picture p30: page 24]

Figura 21. Circuito no Proteus da Placa Unificada

Figura 22. Layout PCB no Proteus da Placa Unificada

### 3.7. Desafios e Soluçoes ˜

A adoçao de uma estrutura modular no projeto de hardware, que segmenta as funç ˜ | oes em ˜
modulos distintos (ESP com sensores, controle do PWM, controle da carga e reguladores ´
de tensao), revelou-se uma estrat ˜ | egia eficaz na identificaç ´ | ao e resoluç ˜ | ao de problemas. ˜
Esta abordagem permitiu testes isolados e a otimizaçao de cada m ˜ | odulo individualmente. ´
A analise detalhada de cada m ´ | odulo conduziu a descobertas t ´ | ecnicas significativas: ´
- Identificou-se a importancia de uma resist ˆ | encia interna na simulaç ˆ | ao da bateria ˜
para o comportamento adequado das tensoes no circuito. A aus ˜ | encia dessa re- ˆ
sistencia foi contornada com a inclus ˆ | ao de um resistor em paralelo ˜ | a fonte de `
alimentaçao durante os testes. ˜
- Constatou-se que o uso do ADC1 e essencial para leituras anal ´ | ogicas, dado que o ´
ADC2 torna-se inoperante quando o Wi-Fi do ESP32 esta ativo. ´
- Observou-se que a aplicaçao de 5V em qualquer pino do ADC1 pode resultar ˜ em leituras incorretas nos outros pinos. Para mitigar esse problema, ajustou-se a
tensao de pulldown da interrupç ˜ | ao para 3.3V. ˜

Inicialmente, o projeto visava estabelecer uma conexao entre o aplicativo e o ˜ ESP via Bluetooth Low Energy (BLE). No entanto, diante dos desafios encontrados na
implementaçao dessa tecnologia, optou-se por estabelecer a comunicaç ˜ | | | ao entre o ESP e o ˜
aplicativo por meio de uma rede de internet. Neste cenario, o ESP atua como servidor e ´ ponto de acesso, enquanto o aplicativo funciona como cliente.

Um aspecto adicional merece destaque no contexto da impressao de placas: trilhas ˜ com largura de 30 mils (milesimos de polegada) apresentam maior complexidade e sensi- ´ bilidade durante o processo de soldagem em placas de fenolite. Essa característica exige
especial atençao e experi ˜ | encia para assegurar uma conex ˆ | ao adequada, evitando o risco ˜
de as trilhas se soltarem e danificarem permanentemente a PCB. Assim, recomenda-se a
fabricaçao de placas de circuito impresso com trilhas de no m ˜ | | | ínimo 40 mils, idealmente
60 mils, para prevenir danos durante a montagem. Adicionalmente, as trilhas de 30 mils foram produzidas com uma fresa industrial na UFSC de Florianopolis. Para PCBs con- ´
feccionadas pelo metodo de transfer ´ | encia t ˆ | ermica em placas de fenolite, recomenda-se ´
trilhas com no mínimo 60 mils.

### 4. Conclusoes e Trabalhos Futuros ˜

Este relatorio tem o objetivo de apresentar a proposta de desenvolvimento de um con- ´ trole por modulaçao de largura de pulso (PWM), voltado para o eficiente gerenciamento ˜
da tensao e corrente em uma bateria de Chumbo- ˜ | Acido de 12V 5Ah. Para alcançar ´
esse proposito, utilizou-se a combinaç ´ | ao de um microcontrolador ESP32 com sensores ˜
INA219, responsaveis pela supervis ´ | ao e controle dos processos. A equipe de desenvol- ˜
vimento teve sucesso na concepçao do sistema, composto por quatro placas distintas e ˜ um aplicativo movel. Testes minuciosos foram realizados para verificar o desempenho do ´ sistema, o qual se mostrou eficaz em diversas condiçoes de teste. ˜
No entanto, devido as restritas limitaç ` | oes temporais, a implementaç ˜ | aõ opcional do
sistema de alertas tornou-se impraticavel, permanecendo como um t ´ | opico adequado para ´
investigaçoes futuras. Outros temas recomendados para an ˜ | alise subsequente incluem: ´
- Incorporaçao de um Sistema Operacional para Paralelizar as Verificaç ˜ | oes: ˜
Explorar a introduçao de um sistema operacional com o prop ˜ | osito de realizar ´
verificaçoes de forma paralela, buscando uma otimizaç ˜ | ao adicional do processo. ˜
Essa abordagem tem o potencial de aprimorar a eficiencia do controle e monitora- ˆ mento do sistema em diversas situaçoes. ˜
- Inserçao de um Cart ˜ | ao SD para Armazenamento de Dados: ˜
Investigar a possibilidade de integrar um cartao SD para substituir o armazena- ˜ mento em memoria flash, proporcionando uma capacidade de armazenamento ´ prolongada para os dados coletados. Essa medida visa atender as demandas de ` registro de informaçoes em longo prazo de maneira mais eficiente. ˜
- Adiçao de Funcionalidades para Alteraç ˜ | ao de Configuraç ˜ | oes da Bateria: ˜
Desenvolver e implementar funcionalidades que permitam a personalizaçao das ˜
configuraçoes da bateria, como a tens ˜ | ao de carga final, corrente m ˜ | axima de des- ´
carga, tensao m ˜ | ínima de descarga e tensao de reconex ˜ | ao da carga. Essa flexibi- ˜
lidade proporcionaria uma adaptaçao mais espec ˜ | ífica as caracter ` | ísticas da bateria
em questao. ˜
Essas consideraçoes indicam direç ˜ | oes promissoras para o aprimoramento futuro ˜
do sistema, ampliando sua funcionalidade e robustez diante das exigencias operacionais ˆ e expectativas.

Referencias ˆ

[Akbar et al. 2016] Akbar, N., Islam, M., Ahmed, S., and Hye, A. (2016). Dynamic model of battery charging. IEEE Region 10 Annual International Conference, Proceedings/TENCON, 2016. Export Date: 03 September 2023; Cited By: 4.
[Alvarez Anton et al. 2013] Alvarez Anton, J., Garcia Nieto, P., Blanco Viejo, C., and Vilan Vilan, J. (2013). Support vector machines used to estimate the battery state of charge. IEEE Transactions on Power Electronics, 28(12):5919–5926. Export Date: 03 September 2023; Cited By: 316 — RAYYAN-LABELS: to find out the difference between state of CHARGE and state of CHARGING.
[Antonov et al. 2019] Antonov, I., Kanchev, H., and Hinov, N. (2019). Study of pwm solar charge controller operation modes in autonomous dc system. 2019 International Conference on High Technology for Sustainable Development, HiTech 2019. Export Date: 03 September 2023; Cited By: 4.

[Belarbi et al. 2019] Belarbi, M., Kacher, A. D. E., and Hallouz, Z. (2019). Operating limits of battery charge controllers - 2019 8th international conference on renewable energy research and applications (icrera 2019). pages 749–754. International Conference on Renewable Energy Research and Applications, Brasov, ROMANIA, NOV 03-06, 2019.
[Chmielewski et al. 2018] Chmielewski, A., Mozaryn, J., Piorkowski, P., and ´ Bogdzinski, K. (2018). Comparison of narx and dual polarization models for esti- ´ mation of the vrla battery charging/discharging dynamics in pulse cycle. Energies, 11(11). Export Date: 03 September 2023; Cited By: 3.
[Dufo-Lopez et al. 2015] Dufo-Lopez, R., Artal-Sevil, J., Bernal-Agustin, J., and Dominguez-Navarro, J. (2015). Effect of the mppt and soc control of the charge controller in pv systems. 2015 17th European Conference on Power Electronics and Applications, EPE-ECCE Europe 2015. Export Date: 03 September 2023; Cited By: 2.
[Faiz et al. 2021] Faiz, M., Kusumaningdyah, J., and Razak, F. (2021). Charging characteristics of solar panels with charging system using pulse width modulation control. 7th International Conference on Electrical, Electronics and Information Engineering: Technological Breakthrough for Greater New Life, ICEEIE 2021. Export Date: 03 September 2023; Cited By: 0.
[Gies 2009] Gies, D. (2009). Safety of electrical equipment containing lead acid batteries. 2009 IEEE Symposium on Product Compliance Engineering, pages 1–7. [Huang et al. 2010] Huang, B., Hsu, P., Wu, M., and Ho, P. (2010). System dynamic model and charging control of lead-acid battery for stand-alone solar pv system. Solar Energy, 84(5):822–830. Export Date: 03 September 2023; Cited By: 43.
[Lavety et al. 2019] Lavety, S., hya, Keshri, R. K., and Given, M. A. C. (2019). Multistep constant current charging strategy for a valve regulated lead-acid battery - 2019 ieee transportation electrification conference (itec-india). IEEE Transportation Electrification Conference (ITEC-India), Bengaluru, INDIA, DEC 17-19, 2019.
[Lin et al. 2016] Lin, H. C., He, Y. J., and Liu, C. W. (2016). Design of an efficient battery charging system based on ideal multi-state strategy - 2016 international symposium on computer, consumer and control (is3c). pages 956–959. 3rd International Symposium on Computer, Consumer and Control (IS3C), Natl Chin Yi Univ Technol, Xian, PEOPLES R CHINA, JUL 04-06, 2016.
[Maithili et al. 2021] Maithili, P., Kavitha, R., Nithishkumar, R., Ganeshbharathi, T., Kannan, S. V., and Kumar, R. M. (2021). Intelligent battery management system. 2021 International Conference on Advancements in Electrical, Electronics, Communication, Computing and Automation (ICAECA), pages 1–5.
[Singh and Mishra 2013] Singh, R. and Mishra, S. (2013). A magnetically coupled feedback-clamped optimal bidirectional battery charger. IEEE Transactions on Industrial Electronics, 60(2):422–432. Export Date: 03 September 2023; Cited By: 69. [Teo et al. 2013] Teo, K. T. K., Goh, H. H., Chua, B. L., Tang, S. K., and Tan, M. K. (2013). Modelling and optimisation of stand alone power generation at rural area. 2013 IEEE International Conference on Consumer Electronics - China, pages 51–56. RAYYAN-LABELS: it’s possible to learn about the SoC with fuzy logic.
[Victor et al. 2019] Victor, A., Mahato, D., Pundir, A., and Saxena, G. (2019). Design, simulation and comparative analysis of different types of solar charge controllers for optimized efficiency. Proceedings - 2019 Women Institute of Technology Conference on Electrical and Computer Engineering, WITCON ECE 2019, pages 17–21. Export Date: 03 September 2023; Cited By: 1.
[Wang et al. 2021] Wang, Y., Huang, F., Pan, B., Li, Y., and Liu, B. (2021). Augmented system model-based online collaborative determination of lead–acid battery states for energy management of vehicles. Measurement and Control (United Kingdom), 54(1):88–101. Export Date: 03 September 2023; Cited By: 4.
[Yoomak et al. 2018] Yoomak, S., Jettanasen, C., and Ngaopitakkul, A. (2018). Design of solar charger challenging various solar irradiance and temperature levels for energy storage. INTERNATIONAL JOURNAL OF INNOVATIVE COMPUTING INFORMA-TION AND CONTROL, 14(6):2071–2090.

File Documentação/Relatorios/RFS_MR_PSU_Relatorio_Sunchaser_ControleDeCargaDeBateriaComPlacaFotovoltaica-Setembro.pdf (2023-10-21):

## Controle de Carga de Bateria com Placa Voltaica

Lucas Eduardo Schlenert de Oliveira¹

, Manoella Rockembach¹

, Rodrigo Ferraz Souza¹

1Universidade Federal de Santa Catarina (UFSC)

engcomp.lucasedu@gmail.com

manu.rockemba@gmail.com

dev.rodrigofs@gmail.com

Abstract. This report delves into the development of a battery charge control system using a voltaic plate, specifically for a Lead-Acid battery (12V 5Ah). The core of this project revolves around the use of PWM control to manage the voltage and current from the plate to the battery, ensuring efficient energy management. The system aims to control the battery’s charging in various States of Charging, ensuring efficient and safe charging. Furthermore, the project seeks to integrate communication with external systems, transmitting voltage and current data to a rain gauge project server via an MQTT Broker. A mobile application will also allow local access to charging data via Bluetooth. Advanced features, such as alert systems, are proposed, but due to time constraints, they might not be incorporated.

Resumo. Este relatorio aprofunda-se no desenvolvimento de um sistema de ´ controle de carga de bateria usando uma placa voltaica, especificamente para uma bateria de Chumbo-Acido (12V 5Ah). O cerne deste projeto gira em torno ´ do uso do controle PWM para gerenciar a tensao e a corrente da placa para ˜ a bateria, garantindo uma gestao eficiente de energia. O sistema visa con- ˜ trolar o carregamento da bateria em varios Estados de Carga, assegurando ´ um carregamento eficiente e seguro. Alem disso, o projeto busca integrar a ´
comunicaçao com sistemas externos, transmitindo dados de tens ˜ | ao e corrente ˜
para um servidor de projeto de pluviometro via um Broker MQTT. Um aplicativo ˆ
movel tamb ´ | em permitir ´ | a o acesso local aos dados de carregamento via Blueto- ´
oth. Funcionalidades avançadas, como sistemas de alerta, sao propostas, mas ˜
devido a limitaçoes de tempo, elas podem n ˜ | ao ser incorporadas. ˜

### 1. Introduçaõ

Em um mundo crescentemente voltado para soluçoes sustent ˜ | aveis, a gest ´ | ao eficiente de ˜
energia torna-se uma prioridade. Neste contexto, o presente documento aborda o desenvolvimento de um sistema de controle de carga de bateria de Chumbo-Acido (12V 5Ah) ´
utilizando uma placa voltaica. O cerne deste projeto e a utilizaç ´ | ao de um controle PWM ˜
para gerenciar a tensao e corrente da placa em direç ˜ | aõ a bateria, garantindo uma gest ` | aõ
eficaz da energia.
O sistema controlara o carregamento da bateria em diversos ´ | States of Charging,
assegurando um carregamento eficiente e seguro, o que contribui para maximizar o tempo
de vida da bateria. Alem da efici ´ | encia no controle de energia, o projeto visa uma ˆ

comunicaçao integrada com sistemas externos. Os dados de tens ˜ | ao e corrente ser ˜ | ao trans- ˜
mitidos para um servidor do projeto do pluviometro por meio de um ˆ | Broker MQTT. Adi-
cionalmente, um aplicativo movel permitir ´ | a o acesso local aos dados de carregamento via ´
bluetooth. Como um diferencial, ha a proposta de implementar um sistema de alertas. ´
No entanto, devido a limitaçoes de tempo, essa funcionalidade pode n ˜ | ao ser incorporada. ˜
Caso seja, os alertas serao gerados pelo servidor j ˜ | a existente, com base nas entradas de ´
dados dos sensores. Uma inovaçao desejada ˜ | e que, ao identificar uma situaç ´ | ao cr ˜ | ítica,
uma notificaçao de alerta seja enviada ao aplicativo m ˜ | ovel do usu ´ | ario por meio do ´ | Google
Firebase.
Neste documento, apos a introduç ´ | ao, apresentaremos uma seç ˜ | ao dedicada ˜ | a re- `
visao metodol ˜ | ogica. Nela, discutiremos a metodologia adotada para a realizaç ´ | ao da re- ˜
visao, incluindo os crit ˜ | erios de inclus ´ | ao e exclus ˜ | ao, bem como o processo de seleç ˜ | ao de ˜
estudos relevantes. Uma analise aprofundada dos resultados obtidos ser ´ | a realizada, onde ´
as principais descobertas serao sintetizadas. ˜
Na sequencia, introduziremos uma seç ˆ | ao sobre o desenvolvimento do projeto. ˜
Esta parte detalhara o planejamento, desenvolvimento e testes realizados, oferecendo uma ´
visao abrangente de todas as etapas e processos envolvidos na execuç ˜ | ao do projeto, ga- ˜
rantindo transparencia e compreens ˆ | ao claras de nossas metodologias e resultados. ˜
2. Revisao R ˜ | apida ´

### 2.1. Metodologia

Com o intuito de realizar uma revisao r ˜ apida, as seguintes strings de pesquisa foram cons- ´ truidas e aplicadas nas bases de referencia IEEE, Web of Science e Scopus: ˆ

- (”photovoltaic”OR ”solar panel”OR ”PV”) AND (”PWM”OR ”Pulse Width Modulation”) AND (”charge controller”OR ”charge regulator”OR ”charging technique”) AND (”lead-acid”OR ”VRLA”)
- (”battery charging”OR ”charge regulation”OR ”charge control”) AND (”SoC”OR ”State of Charging”OR ”charging state”OR ”battery status”) AND (”lead-acid”OR ”Pb-acid”OR ”VRLA”) AND (”efficiency”OR ”safety”OR ”parameters”OR ”measures”OR ”best practices”)

As strings encontraram ao todo 62 artigos nas bases usadas, excluindo os 30 artigos duplicados dectados pelo Rayyan, a ferramenta usada para as seleçao primaria da ˜ literatura encontrada.

2.1.1. Criterios de Inclus ´ | ao e Exclus ˜ | aõ
Para orientar a seleçao dos artigos e a extraç ˜ | ao das informaç ˜ | oes, foram utilizadas as per- ˜
guntas de pesquisa mostradas abaixo:
1. Quais sao os m ˜ | etodos mais eficientes e amplamente utilizados para controlar a ´
tensao e corrente de placas fotovoltaicas usando PWM? ˜
2. Quais sao os m ˜ | etodos mais precisos e confi ´ | aveis para estimar o estado de carre- ´
gamento (SoC) de baterias, especialmente de chumbo-acido, em sistemas fotovol- ´ taicos autonomos? ˆ

3. Quais parametros e medidas s ˆ | ao essenciais para carregar uma bateria com ˜
eficiencia e segurança utilizando controle PWM? ˆ
4. Existem diferenças significativas no carregamento de baterias de lítio e chumbo-acido quando utilizadas em sistemas fotovoltaicos com controle PWM? ´
5. Qual e a efic ´ | acia do controle PWM em comparaç ´ | ao com outros m ˜ | etodos de con- ´
trole em sistemas fotovoltaicos?
6. Considerando a flexibilidade da arquitetura proposta, quais sao os desafios asso- ˜
ciados a sua implementaç ` | ao e manutenç ˜ | ao em um ambiente real? ˜

Com base nestas perguntas, regras para seleçao foram criadas e organizadas em ˜
uma tabela de criterios de inclus ´ | ao e exclus ˜ | ao de artigos, mostrado a seguir. ˜
Criterio ´ | Cumpre o Criterio ´ | Nao Cumpre ˜ o Criterio ´
Utiliza metodos para controlar a ´ tensao e corrente de placas ˜ fotovoltaicas usando PWM? | Proximo crit ´ erio. ´ | Exclusao. ˜
Utiliza metodos para estimar o estado ´ de carregamento (SoC) de baterias em sistemas fotovoltaicos autonomos? ˆ | Proximo crit ´ erio. ´ | Exclusao. ˜
Utiliza de baterias de chumbo-acido? ´ | Inclusao. ˜ | Proximo crit ´ erio. ´
Discute quais parametros e medidas s ˆ ao essenciais ˜ para carregar uma bateria com eficiencia ˆ e segurança utilizando controle PWM? | Inclusao. ˜ | Exclusao. ˜

### 2.1.2. Seleçao de Estudos ˜

A partir da leitura dos resumos dos artigos, e considerando as perguntas de pesquisa, foram analisados todos os 62 artigos. Destes, 17 artigos foram inclusos na revisao e ˜
43 artigos foram descartados. Os motivos para exclusao s ˜ | ao os seguintes: 13 artigos ˜
estao fora do escopo de pesquisa, 12 usam componentes errados, 10 aplicam m ˜ | etodos ´
diferentes, 8 nao s ˜ | ao relevantes para esta revis ˜ | ao e 2 n ˜ | ao foi possivel obter o PDF. ˜
A analise quantitativa de cada etapa no processo de seleç ´ | ao de artigos pode ser ˜
melhor visualizada no diagrama a seguir:


Figura 1. Diagrama gerado no PRISMA

### 2.2. Resultados e Discussaõ

### 2.2.1. Tipos de Baterias Estudadas

A predominancia das baterias de chumbo- ˆ | acido nos estudos reflete sua ampla utilizaç ´ | aõ
na industria e pesquisa. [Wang et al. 2021] exploraram a determinaç ´ | | | ao online do es- ˜
tado das baterias de chumbo-acido para a gest ´ | ao energ ˜ | etica de ve ´ | ículos. | No en-
tanto, baterias de lítio e VRLA tambem foram mencionadas, indicando uma diversi- ´ dade de aplicaçoes e contextos de pesquisa [Alvarez Anton et al. 2013, Faiz et al. 2021, ˜ Chmielewski et al. 2018, Lavety et al. 2019, Lin et al. 2016].

### 2.2.2. Metodos de Controle ´

Os metodos de controle variam desde t ´ | ecnicas tradicionais, como PWM, at ´ | e abor- ´
dagens mais inovadoras. [Faiz et al. 2021] utilizaram a Modulaçao por Largura de ˜ Pulso (PWM) em um controlador de carga solar, enquanto [Singh and Mishra 2013] propuseram um carregador bidirecional de bateria otimizado com feedback-clamped. Outros estudos, como [Dufo-Lopez et al. 2015, Victor et al. 2019, Antonov et al. 2019, Yoomak et al. 2018, Teo et al. 2013, Belarbi et al. 2019], tambem destacaram a im- ´
portancia e efic ˆ | acia de diferentes t ´ | ecnicas de controle para otimizar a carga da bateria. ´

### 2.2.3. Estimaçao do SoC ˜

A estimativa do SoC e crucial para a gest ´ | ao eficaz da bateria. [Wang et al. 2021] em- ˜
pregaram um algoritmo de estimativa colaborativa para determinar o estado das bate-
rias de chumbo-acido. Por outro lado, [Alvarez Anton et al. 2013] utilizaram M ´ | aquinas ´
de Vetores de Suporte para estimar o SoC de uma bateria de lítio. | Alem disso, ´
[Dufo-Lopez et al. 2015] e [Maithili et al. 2021] tambem abordaram a import ´ | ancia da es- ˆ
timativa precisa do SoC para garantir a eficiencia e longevidade da bateria. ˆ
2.2.4. Eficiencia Energ ˆ | etica ´
A eficiencia energ ˆ | etica ´ | e um pilar central nos estudos revisados. [Singh and Mishra 2013] ´
relataram eficiencias m ˆ | aximas de 90,24% e 92,7% em diferentes modos de operaç ´ | aõ
de seu prototipo. [Faiz et al. 2021] destacaram uma efici ´ | encia de 94% para carga de ˆ
bateria e 93% para carga total em seu controlador de carga solar. Outros estudos, como [Huang et al. 2010, Lin et al. 2016, Yoomak et al. 2018], tambem enfatizaram a ´
importancia da efici ˆ | encia energ ˆ | etica na gest ´ | ao de baterias. ˜

### 2.2.5. Desafios de Implementaçaõ

A implementaçao de sistemas de bateria eficientes n ˜ | ao est ˜ | a isenta de desafios. [Gies 2009] ´
explorou a necessidade de ventilaçao de g ˜ | as hidrog ´ | enio em equipamentos el ˆ | etricos con- ´
tendo baterias de chumbo-acido. Por outro lado, [Victor et al. 2019] discutiram a im- ´
portancia de escolher o controlador de carga correto para otimizar a efici ˆ | encia. Al ˆ | em´
disso, [Akbar et al. 2016] e [Teo et al. 2013] abordaram os desafios associados a modela- `
gem dinamica e otimizaç ˆ | ao de sistemas de geraç ˜ | ao de energia aut ˜ | onomos. ˆ
2.2.6. Tecnicas e Estrat ´ | egias de Carregamento ´

Diversas estrategias de carregamento foram exploradas nos estudos. [Lavety et al. 2019] ´
propos uma estrat ˆ | egia de carregamento de corrente constante multi-etapa para ba- ´
terias VRLA. [Lin et al. 2016] apresentou um sistema de carregamento de bateria
eficiente baseado em uma estrategia ideal de m ´ | ultiplos estados. | Enquanto isso, ´
[Belarbi et al. 2019] discutiu os limites operacionais dos controladores de carga da bateria, e [Yoomak et al. 2018] projetou um carregador solar que desafia varios n ´ íveis de irradiancia solar e temperatura para armazenamento de energia. ˆ

### 2.2.7. Aplicaçoes e Contextos de Pesquisa ˜

A diversidade de aplicaçoes e contextos de pesquisa em gest ˜ | ao de baterias ˜ | e evidente ´
nos estudos revisados. [Chmielewski et al. 2018] investigaram a aplicaçao de baterias em ˜ sistemas de armazenamento de energia renovavel, enquanto [Alvarez Anton et al. 2013] ´ focaram em sistemas de backup de energia para infraestruturas críticas. Alem disso, ´ [Huang et al. 2010] e [Akbar et al. 2016] exploraram a integraçao de baterias em micro- ˜
redes e sistemas de geraçao de energia distribu ˜ | ída, respectivamente.

### 2.2.8. Estrategias Avançadas de Carregamento ´

Alem das estrat ´ | egias tradicionais de carregamento, novas abordagens est ´ | ao sendo explo- ˜
radas para melhorar a eficiencia e a vida ˆ | util das baterias. [Lavety et al. 2019] introduziu ´
uma estrategia de carregamento adaptativo baseada em feedback para baterias de ´ | íon-
lítio. [Lin et al. 2016] propos um m ˆ | etodo de carregamento r ´ | apido que minimiza o estresse ´
termico na bateria. [Belarbi et al. 2019] e [Yoomak et al. 2018] discutiram estrat ´ | egias de ´
carregamento otimizadas para baterias em sistemas solares fotovoltaicos.
2.3. Conclusoes da Revis ˜ | aõ
A gestao eficiente de baterias ˜ | e fundamental para otimizar a integraç ´ | ao de fontes de ener- ˜
gia renovavel, como pain ´ | eis solares, em sistemas de armazenamento de energia. Este es- ´
tudo revisou extensivamente a literatura sobre gestao de baterias, modelagem, simulaç ˜ | ao e ˜
estrategias avançadas de carregamento. Com base nessa revis ´ | ao, podemos extrair insights ˜
cruciais para o projeto em questao, que visa desenvolver um controlador PWM usando ˜
MOSFET para uma bateria de chumbo acido estacion ´ | aria de 15V com um painel solar de ´
20W.
Estrategias de Carregamento: ´ | Como destacado por [Lavety et al. 2019], a
implementaçao de estrat ˜ | egias de carregamento adaptativo pode ser crucial para maxi- ´
mizar a eficiencia do carregamento da bateria de chumbo ˆ | acido, especialmente quando ´
alimentada por um painel solar de 20W. Considerando as variaçoes na geraç ˜ | ao de energia ˜
solar, um carregamento adaptativo pode ajustar dinamicamente a taxa de carregamento para garantir a saude da bateria. ´

Monitoramento e Feedback: A integraçao de sistemas de monitoramento, como ˜ proposto por [Lin et al. 2016], pode ser benefica para o projeto. Monitorar a temperatura ´
e outros parametros vitais da bateria pode ajudar a prevenir situaç ˆ | oes de estresse t ˜ | ermico ´
e prolongar a vida util da bateria. onfiguraç ´ | oes do controlador PWM para otimizar o ˜
desempenho da bateria.
Integraçao com Painel Solar: ˜ | O trabalho de [Belarbi et al. 2019] e
[Yoomak et al. 2018] sobre estrategias de carregamento para baterias em sistemas solares ´
fotovoltaicos e particularmente relevante. A implementaç ´ | ao de algoritmos que conside- ˜
rem a variaçao na geraç ˜ | ao de energia solar pode ajudar a otimizar o carregamento da ˜
bateria e garantir uma operaçao eficiente. ˜
Consideraçoes Finais: ˜ | O projeto proposto e uma combinaç ´ | ao de hardware e soft- ˜
ware que visa otimizar o armazenamento e a utilizaçao de energia solar. Com base na li- ˜
teratura revisada, e evidente que a combinaç ´ | ao de estrat ˜ | egias avançadas de carregamento, ´
monitoramento em tempo real e comunicaçao eficiente via MQTT pode levar a um sis- ˜
tema robusto e eficiente. Recomenda-se tambem a realizaç ´ | ao de testes extensivos em ˜
condiçoes variadas para validar e refinar o sistema proposto. ˜

### 3. Desenvolvimento do Projeto

Nesta seçao, apresentaremos a descriç ˜ | ao funcional e o diagrama de alto n ˜ | ível do sistema,
detalhando a estrutura e os requisitos fundamentais do projeto. Em seguida, exploraremos
a logica de controle e comunicaç ´ | ao do ESP, e por fim, o design e a navegabilidade do ˜
aplicativo movel e suas telas, oferecendo uma vis ´ | ao da interface do usu ˜ | ario. ´

### 3.1. Descriçao Funcional ˜

A descriçao funcional tem o objetivo de descrever todas as caracter ˜ | ísticas e restriçoes do ˜
projeto. Essa descriçaõ e comumente dividida em requisitos funcionais, requisitos n ´ | aõ
funcionais e regras de negocio. ´

### 3.1.1. Requisitos Funcionais

Os requisitos funcionais descrevem as funçoes espec ˜ | íficas que um sistema deve ter. Eles
definem o que o sistema deve fazer do ponto de vista do usuario ou de outros componentes ´ do sistema.
Geralmente, os requisitos funcionais sao expressos em termos de aç ˜ | oes ou ˜
operaçoes que o sistema deve realizar, bem como em termos de entradas e sa ˜ | ídas es-
peradas.

Sao requisitos funcionais do projeto Sunchaser: ˜

1. Controle de Carga:
- O sistema deve controlar a carga de uma bateria de chumbo-acido de 12V ´ usando um painel solar e um ESP32.
- A carga deve ser controlada via PWM utilizando um MOSFET IRF540.
- O sistema deve ter a capacidade de ligar/desligar a carga atraves de um ´ rele.´
2. Mediçao de Corrente e Tens ˜ | ao: ˜
- O sistema deve medir a corrente entre o painel solar e a bateria, e entre a bateria e a carga usando sensores INA219.
- Deve medir as tensoes do painel solar e da bateria. ˜
- Os sensores INA219 devem ser calibrados atraves de uma m ´ | edia de dez ´
mediçoes para minimizar o ru ˜ | ído.
- O ESP32 deve monitorar as mediçoes de tens ˜ | ao e corrente. ˜
3. Segurança e Precisao: ˜
- O sistema deve garantir a precisao das mediç ˜ | oes de tens ˜ | ao atrav ˜ | es de divi- ´
dores de tensao. ˜
- Diodos zener devem ser utilizados para proteger o ESP32 contra sobretensoes. ˜
4. Gerenciamento de Dados:
- O ESP32 deve armazenar dados de mediçao em uma mem ˜ | oria cache antes ´
de envia-los para o broker. ´
- Os dados do cache devem ser transferidos para a memoria de longo prazo ´ apos o envio, e o cache deve ser limpo. ´
5. Aplicativo Movel: ´
- Tela Inicial: Exibida quando o Bluetooth esta desconectado, com um ´
botao para tentar a conex ˜ | ao. ˜
- Tela Home: Exibida quando conectado, permite aos usuarios ver os valo- ´
res da ultima mediç ´ | ao, solicitar uma nova mediç ˜ | ao e acessar outras opç ˜ | oes. ˜
- Tela de Graficos: ´ | Acessível atraves da barra de opç ´ | oes, permite visualizar ˜
diferentes medidas.

- Tela de Configuraçoes: ˜ Permite aos usuarios ajustar o intervalo entre as ´ mediçoes, o intervalo entre os envios ao servidor e o tempo de dados ar- ˜ mazenados na memoria de longo prazo. ´
6. Alertas e Monitoramento:
- O sistema deve emitir um Alerta Laranja quando a bateria estiver baixa (menos de 30%).
- Um Alerta Vermelho deve ser emitido se a bateria e a geraçao de ener- ˜ gia estiverem baixas, ou se a corrente entre a bateria e a carga atingir ou exceder 50A.
- O ESP32 deve abrir o rele para interromper o uso da bateria pela carga em ´ caso de Alerta Vermelho.
7. Integraçao e Compatibilidade: ˜
- O sistema deve ser integrado ao sistema existente do pluviometro e ao ˆ broker MQTT ja estabelecido. ´
- Deve aderir aos protocolos de comunicaçao preestabelecidos para garantir ˜ compatibilidade e interoperabilidade.
8. Gestao de Conectividade: ˜
- O WiFi e o Bluetooth devem permanecer desligados ate que sejam ne- ´ cessarios. ´
- O WiFi deve ser ativado de acordo com o intervalo estabelecido para as tentativas de envio ao servidor.
- O Bluetooth deve ser ativado apenas quando um interruptor físico na placa for acionado, gerando uma interrupçao no ESP32 e colocando-o no loop ˜ de comunicaçao Bluetooth. ˜
- O Bluetooth deve ser desligado quando tanto a chave estiver desligada quanto o dispositivo movel estiver desconectado. ´

### 3.1.2. Requisitos Nao Funcionais ˜

Os requisitos nao funcionais descrevem as caracter ˜ | ísticas do sistema que afetam a quali-
dade, o desempenho, a segurança e outros aspectos do sistema que nao est ˜ | ao diretamente ˜
relacionadas as funç ` | oes espec ˜ | íficas.

Estes requisitos se concentram em qualidades do sistema, como escalabilidade, disponibilidade, usabilidade, desempenho, segurança e confiabilidade. Os requisitos naõ funcionais podem ser mais difíceis de medir e testar do que os requisitos funcionais, pois muitas vezes envolvem criterios subjetivos. ´

Sao requisitos n ˜ | ao funcionais do projeto Sunchaser: ˜
1. Hardware:
- A placa de circuito impresso personalizada deve ser de dupla face e feita
| de fenolite.
- Trilhas de 30 mil sao usadas para sinais, 40 mil para alimentaç ˜ | ao digital e ˜
60 mil para potencia para evitar desgaste devido ˆ | a corrente. `
2. Operacional:
- O sistema naõ possui mecanismos específicos para lidar com variaçoes ˜
extremas de temperatura ou interferencias eletromagn ˆ | eticas externas. ´

- Esta destinado a operar em ´ | areas remotas e deve ser alojado em uma caixa ´
protetora contra os elementos.
3. Manutençao e Atualizaç ˜ | oes: ˜
- O sistema naõ requer gestao espec ˜ | ífica do desgaste da memoria flash. ´
- As atualizaçoes de software, se necess ˜ | arias, devem ser realizadas manual- ´
mente.
4. Segurança:
- Deve utilizar logicas booleanas integradas para alertar os usu ´ | arios sobre ´
possíveis problemas ou falhas.
- O layout da placa deve ser projetado para minimizar a interferencia no ˆ ESP32 causada pelo chaveamento PWM do circuito de potencia. ˆ
5. Desempenho:
- O sistema deve garantir a eficiencia energ ˆ | etica e a segurança operacional. ´
- O ESP32 e respons ´ | avel por garantir que a bateria nunca atinja um n ´ | ível
criticamente baixo e por administrar o carregamento seguro e eficiente da bateria.

### 3.1.3. Regras de Negocio ´

Regras de negocio s ´ | ao diretrizes que estabelecem os procedimentos e as restriç ˜ | oes que ˜
governam as operaçoes e o comportamento de um sistema. Elas desempenham um papel ˜ fundamental na definiçao de como um sistema opera e interage com outros sistemas. ˜

As regras de negocio orientam como o software deve funcionar e interagir com os ´ usuarios e outros sistemas. ´

Sao regras de neg ˜ | ocio do projeto Sunchaser: ´
1. Controle de Energia:
- A energia do painel solar so deve ser usada para carregar a bateria quando ´ a condiçao de carga for adequada, conforme determinado pelo ESP32. ˜
- O sistema deve interromper o carregamento da bateria quando ela estiver totalmente carregada para evitar sobrecarga.
2. Mediçoes: ˜
- As mediçoes de corrente e tens ˜ | ao devem ser realizadas em intervalos es- ˜
pecíficos, conforme configurado no aplicativo movel. ´
- As mediçoes devem ser calibradas para garantir precis ˜ | ao e minimizar o ˜
ruído.
3. Conectividade:
- O WiFi deve ser ativado apenas durante os períodos de envio de dados ao servidor, conforme configurado no aplicativo movel. ´
- O Bluetooth so pode ser ativado por meio de um interruptor f ´ | ísico na placa
e deve ser desativado quando o dispositivo movel estiver desconectado e o ´ interruptor estiver desligado.
4. Alertas:
- Alertas específicos devem ser emitidos com base no status da bateria e da geraçao de energia. ˜

- Os alertas devem ser claramente comunicados ao usuario via aplicativo ´ movel. ´
5. Aplicativo Movel: ´
- O aplicativo movel deve permitir aos usu ´ | arios visualizar dados de ´
mediçao, configurar intervalos de mediç ˜ | ao e envio, e visualizar alertas. ˜
- O aplicativo so pode se conectar ao ESP32 via Bluetooth quando o inter- ´ ruptor físico na placa estiver ativado.
6. Segurança:
- Mecanismos de segurança, como diodos zener e dividores de tensao, de- ˜ vem ser implementados para proteger o ESP32 e outros componentes sensíveis de sobretensoes. ˜
7. Integraçao: ˜
- O sistema deve ser compatível e interoperavel com o sistema existente do ´
pluviometro e o broker MQTT, aderindo aos protocolos de comunicaç ˆ | aõ
preestabelecidos.
8. Armazenamento de Dados:
- Os dados de mediçao devem ser armazenados temporariamente em um ˜ cache antes de serem enviados ao broker MQTT.
- Apos o envio, os dados devem ser transferidos para a mem ´ | oria de longo ´
prazo no ESP32.
9. Manutençao: ˜
- Nao h ˜ | a um plano formal de manutenç ´ | ao; no entanto, os usu ˜ | arios devem ser ´
alertados sobre possíveis problemas ou falhas atraves de l ´ | ogicas booleanas ´
integradas.
10. Operaçao: ˜
- O sistema e destinado a operar em ´ | areas remotas e deve ser alojado em ´
uma caixa protetora para garantir sua integridade contra os elementos.

### 3.2. Diagrama de Alto Nível do Sistema

A Figura 2 ilustra o Diagrama de Alto Nível do Sistema, proporcionando uma visaõ simplificada da arquitetura integrada do projeto em desenvolvimento e do projeto do
pluviometro existente. Neste diagrama, os componentes em ˆ | | | roxo representam as par-
tes que estao sendo desenvolvidas neste projeto, focadas no ESP, na placa de controle e ˜
no aplicativo mobile. Eles sao respons ˜ | aveis pelo gerenciamento e controle eficiente da ´
energia, garantindo operaçao otimizada e segura. ˜ | Os elementos em cinza, por outro
lado, sao componentes j ˜ | a existentes do ´ | projeto do pluviometro ˆ | , incluindo o broker, o
servidor e o site, que facilitam a comunicaçao e o armazenamento de dados. ˜

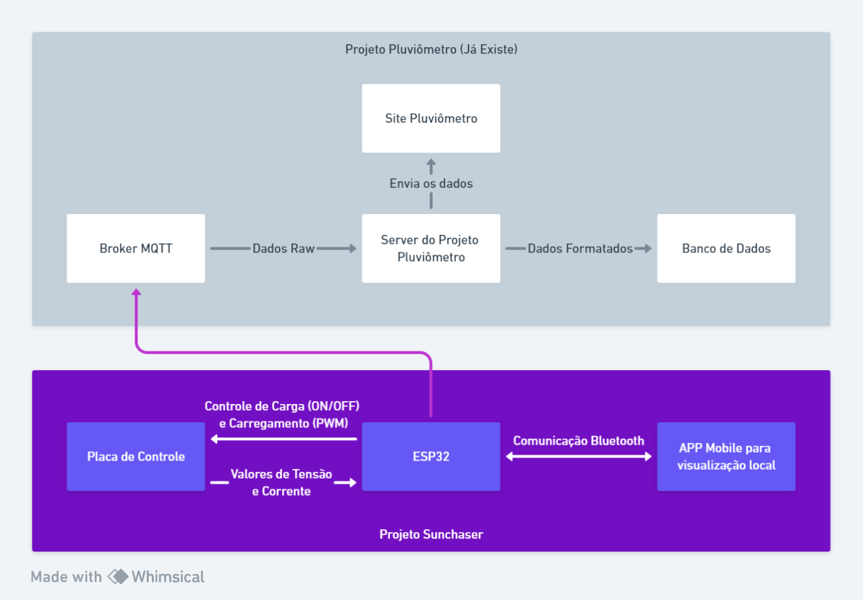
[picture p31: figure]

Figura 2. Diagrama do Sistema de Alto Nível

### 3.3. Funcionamento e Diagramas do programa do ESP

A logica de controle e comunicaç ´ | ao do ESP ˜ | e detalhadamente ilustrada atrav ´ | es de uma ´
serie de fluxogramas, cada um destacando um aspecto espec ´ | | | ífico do funcionamento in-
terno do ESP.

Na Figura 3, e apresentada a estrutura principal do programa do ESP. O ESP opera ´
em dois loops principais simultaneos: o loop de controle e o loop de WiFi, al ˆ | | | em de uma ´
interrupçao Bluetooth que ˜ | e ativada fisicamente. ´

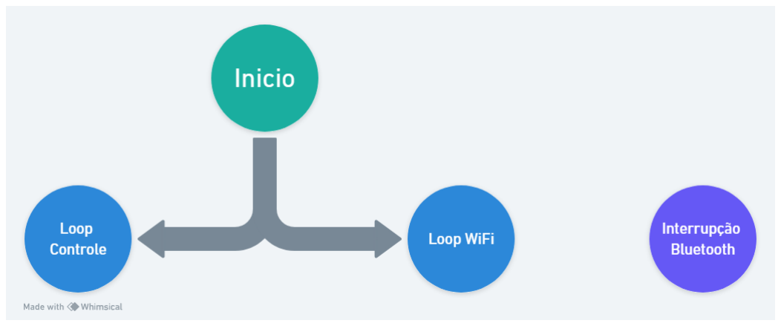
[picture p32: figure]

Figura 3. Fluxograma Principal do ESP

A Figura 4 detalha o loop de controle. Este loop inicia requisitando uma mediçao, ˜ processa os dados coletados para ajustar o PWM conforme os estados de carga da bate-
ria e, em seguida, altera o duty cycle do PWM antes de requisitar a proxima mediç ´ | ao, ˜
respeitando o intervalo de tempo definido no aplicativo.


Figura 4. Fluxograma do Loop de Controle do ESP

O loop de WiFi, como mostrado na Figura 5, e respons ´ | avel pela comunicaç ´ | ao com ˜
o broker. Ele aguarda o tempo definido, tenta enviar os dados armazenados no cache para o broker e, se bem-sucedido, move os dados para a memoria de longo prazo e limpa o ´ cache.

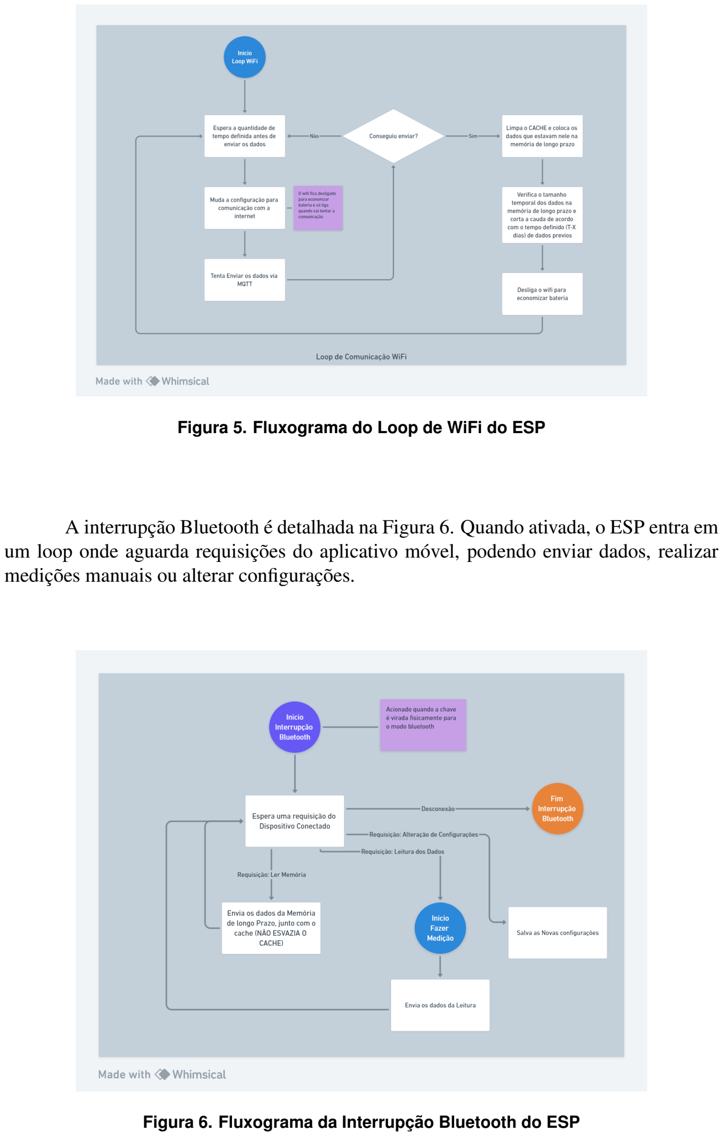
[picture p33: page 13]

Figura 5. Fluxograma do Loop de WiFi do ESP

A interrupçao Bluetooth ˜ | e detalhada na Figura 6. Quando ativada, o ESP entra em ´
um loop onde aguarda requisiçoes do aplicativo m ˜ | ovel, podendo enviar dados, realizar ´
mediçoes manuais ou alterar configuraç ˜ | oes. ˜

Figura 6. Fluxograma da Interrupçao Bluetooth do ESP ˜

3.3.1. Gestao da Mem ˜ | oria do ESP ´
A gestao da mem ˜ | oria do ESP ´ | e ilustrada em um conjunto adicional de diagramas. A ´
Figura 7 mostra o preenchimento do cache durante as mediçoes. A Figura 8 ilustra a ˜
transferencia de dados do cache para a mem ˆ | oria de longo prazo durante o envio bem- ´
sucedido ao broker. A Figura 9 destaca que as operaçoes Bluetooth n ˜ | ao afetam o cache ˜
ou a memoria de longo prazo, mas podem acessar e transmitir os dados armazenados. ´


Figura 7. Diagrama da Memoria do ESP durante as Mediç ´ | oes ˜


Figura 8. Diagrama da Memoria do ESP durante o Envio ao Servidor ´

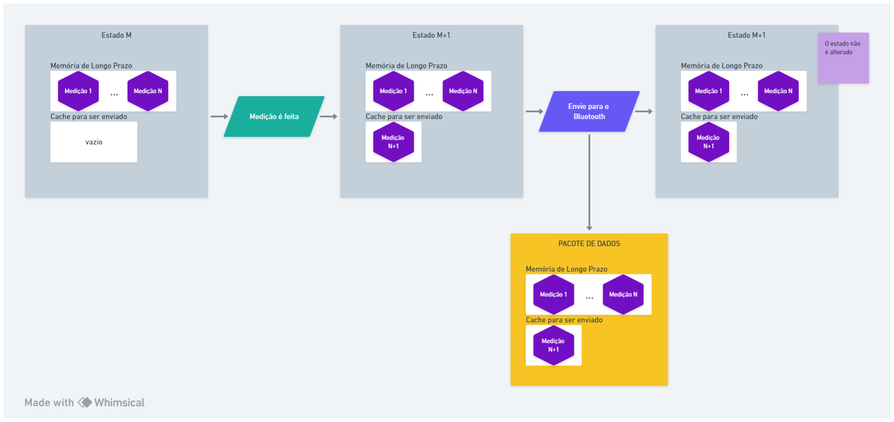
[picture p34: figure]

Figura 9. Diagrama da Memoria do ESP durante a Comunicaç ´ | ao Bluetooth ˜

### 3.4. Funcionamento e Diagramas do Aplicativo Mobile

O aplicativo movel, cujo fluxograma de navegaç ´ | aõ e mostrado na Figura 10, ´ | e projetado ´
para oferecer acesso local aos dados de carregamento via Bluetooth. A primeira tela

solicita ao usuario que estabeleça uma conex ´ | ao Bluetooth com o ESP. Uma vez conectado, ˜
o usuario ´ | e levado para a tela inicial, onde pode navegar para outras seç ´ | oes do aplicativo ˜
que oferecem insights detalhados e visualizaçoes gr ˜ | aficas dos dados de carregamento. ´

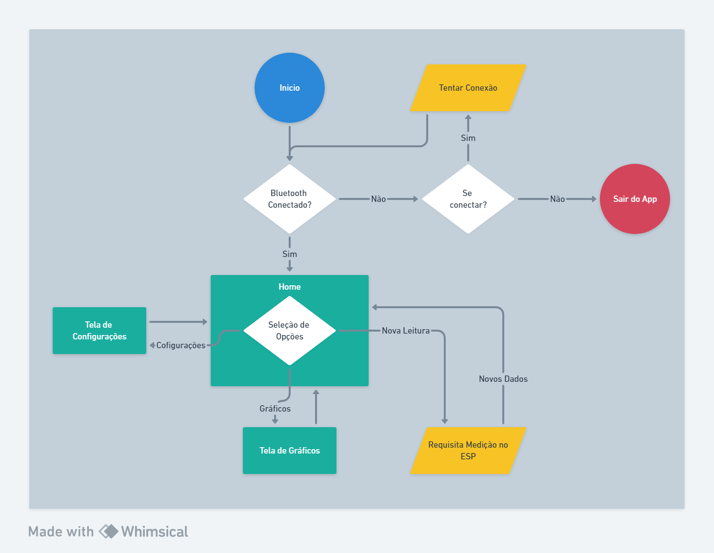
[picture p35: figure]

Figura 10. Fluxograma de Navegaçao no Aplicativo Mobile ˜

### 3.4.1. Design Preliminar das Telas do Aplicativo Mobile

As Figuras 11 a 14 mostram o design preliminar das telas do aplicativo movel. A Tela 1 ´
e a interface inicial onde os usu ´ | arios s ´ | ao solicitados a conectar o aplicativo ao ESP via ˜
Bluetooth. Uma vez estabelecida a conexao, os usu ˜ | arios s ´ | ao direcionados para a Tela 2, a ˜
tela inicial, que oferece uma visao geral das leituras mais recentes e opç ˜ | oes para navegar ˜
para outras seçoes do aplicativo. ˜
A Tela 3 apresenta graficos detalhados das leituras de carregamento. Os usu ´ | arios ´
podem selecionar diferentes metricas atrav ´ | es de um menu dropdown para visualizar ´
graficos espec ´ | íficos. A navegabilidade entre as telas e facilitada por uma barra de menu ´
na parte inferior, permitindo aos usuarios alternar facilmente entre as diferentes seç ´ | oes do ˜
aplicativo.

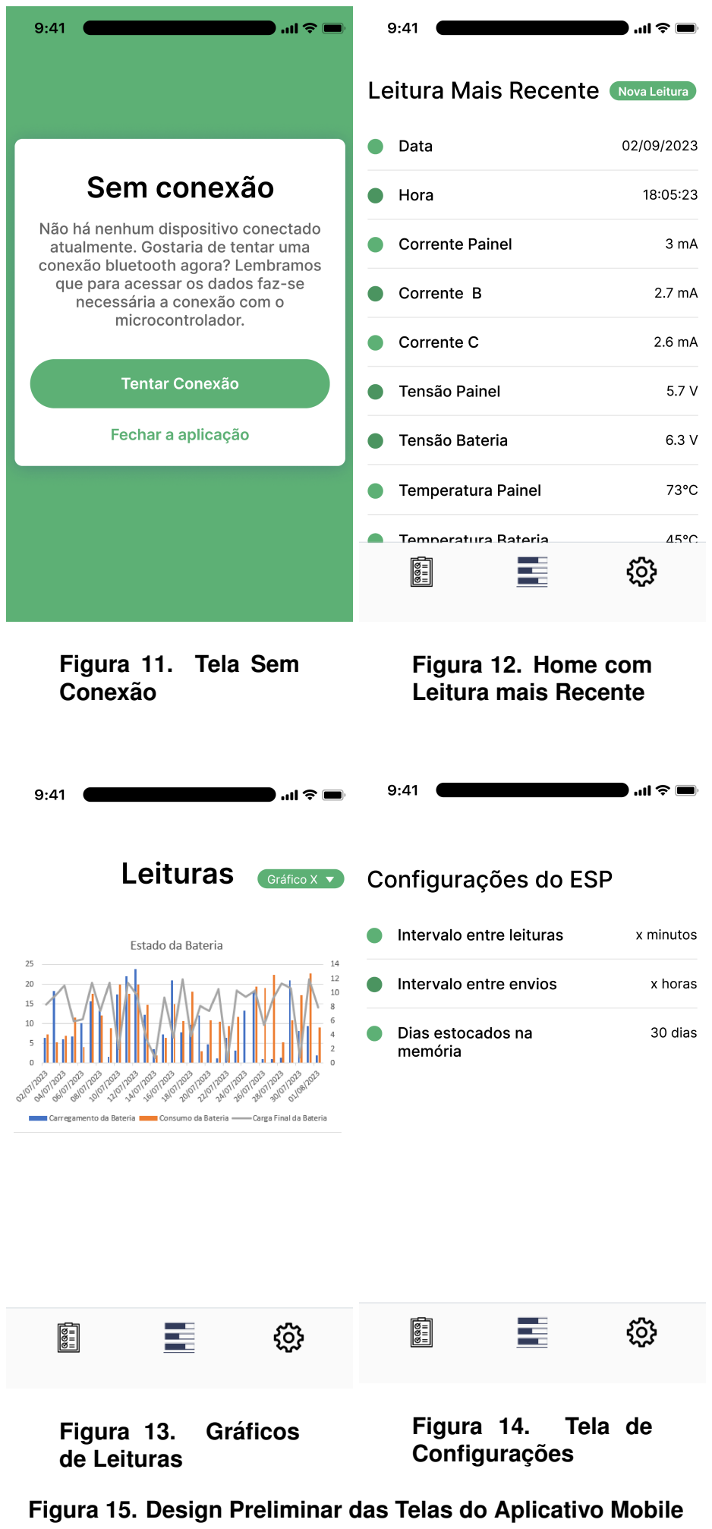
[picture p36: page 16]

Figura 11. Tela Sem
Conexaõ

Figura 12. Home com
Leitura mais Recente

Figura 13. Graficos ´
de Leituras

Figura 14. Tela de
Configuraçoes ˜

Figura 15. Design Preliminar das Telas do Aplicativo Mobile

### 3.5. Desenvolvimento da Placa de Controle

A placa de controle foi meticulosamente desenvolvida utilizando o software Proteus 8.9, resultando em um design de PCB de dupla face compacto e eficiente. A Figura 16 ilustra
o circuito eletrico de controle, que incorpora o n ´ | ucleo do sistema de gerenciamento de ´
energia. Este circuito inclui a entrada do painel solar, o conector da bateria e a saída da carga, todos gerenciados pelo MOSFET de canal P IRF 9640, que e modulado pelo ESP. ´
Um switch, tambem presente neste circuito, ´ | e respons ´ | avel por acionar a interrupç ´ | ao para ˜
o loop Bluetooth.

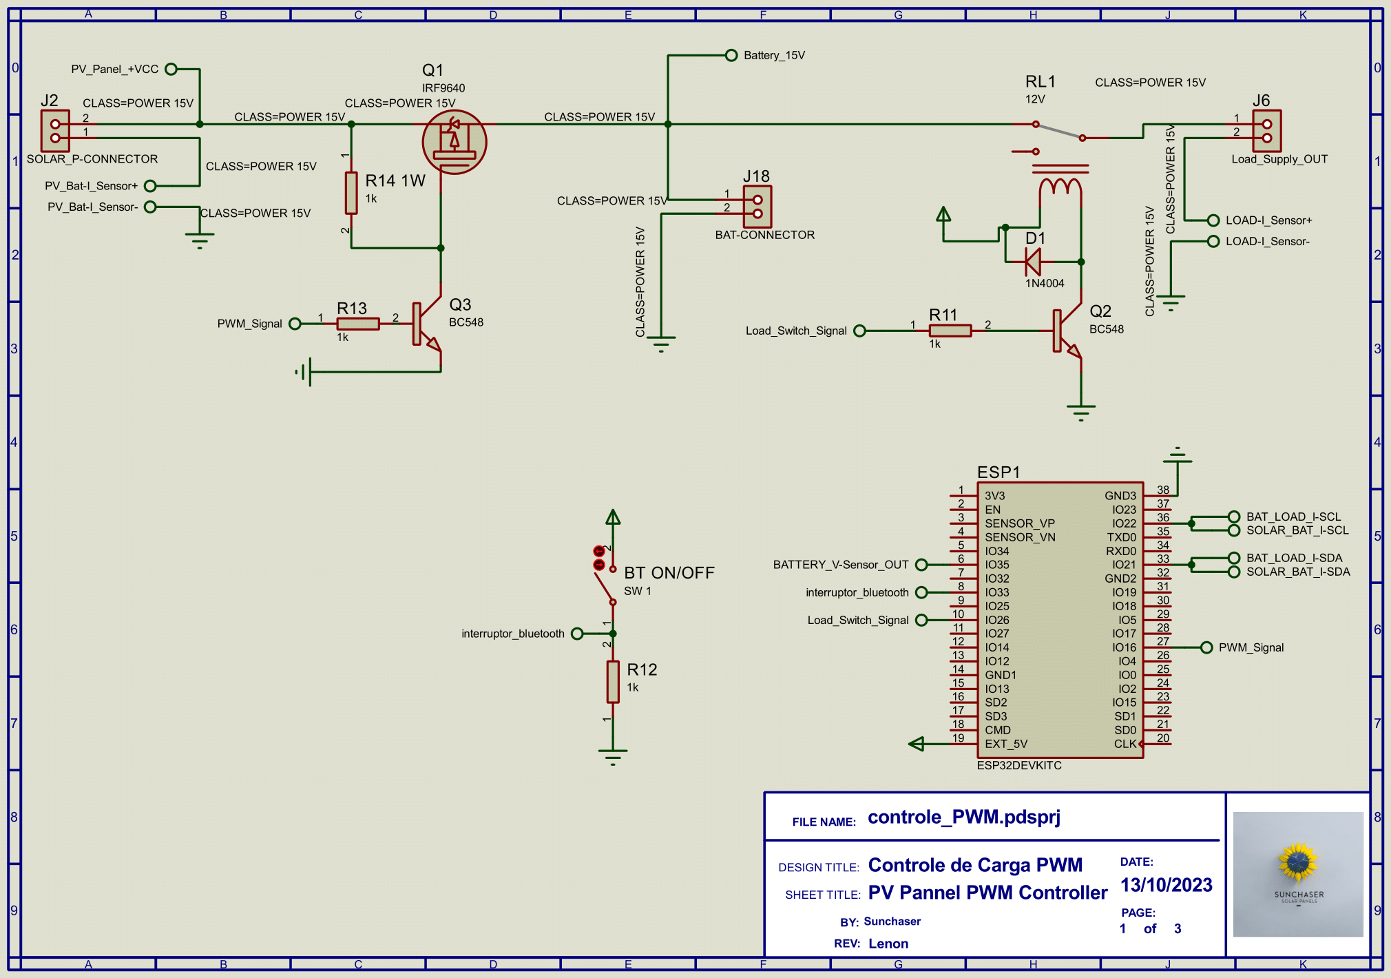
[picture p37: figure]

Figura 16. Circuito Eletrico de Controle ´

Um rele controla a sa ´ | ída da bateria para a carga, garantindo que a bateria nao seja ˜
excessivamente descarregada e oferecendo proteçao contra curtos-circuitos. O MOSFET ˜ e o rele s ´ ao acionados por transistores BC548. ˜

A Figura 17 apresenta os reguladores de tensao de 9V e 5V. O regulador de 5V ˜
e dedicado ´ | a alimentaç ` | ao do ESP, enquanto o de 9V est ˜ | a dispon ´ | ível para usos genericos, ´
facilitando a expansao e a modificaç ˜ | ao do sistema. Os reguladores est ˜ | ao conectados a ˜
uma barra de pinos, proporcionando facil acesso para futuras integraç ´ | oes. ˜


Figura 17. Circuito Eletrico dos Reguladores de Tens ´ | aõ
O circuito eletrico dos sensores ´ | e mostrado na Figura 18. Inclui conectores para ´
os sensores que enviam sinais ao ESP, dois INA219 para monitoramento de corrente e
tensao, e dois divisores de tens ˜ | ao para medir as tens ˜ | oes da bateria e do painel solar. Um ˜
diodo Zener de 5V protege o ESP contra sobretensoes. ˜

Figura 18. Circuito Eletrico dos Sensores ´

A integraçao desses circuitos levou ˜ | a criaç ` | ao da PCB, ilustrada na Figura 19. Com ˜
dimensoes de 9.5cm x 10cm, a placa de dupla face hospeda o ESP e os INAs em barras ˜

de pinos, garantindo uma montagem e manutençao simplificadas. ˜


Figura 19. Placa de Circuito Impresso

Referencias ˆ

[Akbar et al. 2016] Akbar, N., Islam, M., Ahmed, S., and Hye, A. (2016). Dynamic model of battery charging. IEEE Region 10 Annual International Conference, Proceedings/TENCON, 2016. Export Date: 03 September 2023; Cited By: 4.
[Alvarez Anton et al. 2013] Alvarez Anton, J., Garcia Nieto, P., Blanco Viejo, C., and Vilan Vilan, J. (2013). Support vector machines used to estimate the battery state of charge. IEEE Transactions on Power Electronics, 28(12):5919–5926. Export Date: 03 September 2023; Cited By: 316 — RAYYAN-LABELS: to find out the difference between state of CHARGE and state of CHARGING.
[Antonov et al. 2019] Antonov, I., Kanchev, H., and Hinov, N. (2019). Study of pwm solar charge controller operation modes in autonomous dc system. 2019 International Conference on High Technology for Sustainable Development, HiTech 2019. Export Date: 03 September 2023; Cited By: 4.
[Belarbi et al. 2019] Belarbi, M., Kacher, A. D. E., and Hallouz, Z. (2019). Operating limits of battery charge controllers - 2019 8th international conference on renewable energy research and applications (icrera 2019). pages 749–754. International Conference on Renewable Energy Research and Applications, Brasov, ROMANIA, NOV 03-06, 2019.
[Chmielewski et al. 2018] Chmielewski, A., Mozaryn, J., Piorkowski, P., and ´ Bogdzinski, K. (2018). Comparison of narx and dual polarization models for esti- ´ mation of the vrla battery charging/discharging dynamics in pulse cycle. Energies, 11(11). Export Date: 03 September 2023; Cited By: 3.
[Dufo-Lopez et al. 2015] Dufo-Lopez, R., Artal-Sevil, J., Bernal-Agustin, J., and Dominguez-Navarro, J. (2015). Effect of the mppt and soc control of the charge controller in pv systems. 2015 17th European Conference on Power Electronics and Applications, EPE-ECCE Europe 2015. Export Date: 03 September 2023; Cited By: 2.
[Faiz et al. 2021] Faiz, M., Kusumaningdyah, J., and Razak, F. (2021). Charging characteristics of solar panels with charging system using pulse width modulation control. 7th International Conference on Electrical, Electronics and Information Engineering: Technological Breakthrough for Greater New Life, ICEEIE 2021. Export Date: 03 September 2023; Cited By: 0.
[Gies 2009] Gies, D. (2009). Safety of electrical equipment containing lead acid batteries. 2009 IEEE Symposium on Product Compliance Engineering, pages 1–7. [Huang et al. 2010] Huang, B., Hsu, P., Wu, M., and Ho, P. (2010). System dynamic model and charging control of lead-acid battery for stand-alone solar pv system. Solar Energy, 84(5):822–830. Export Date: 03 September 2023; Cited By: 43.
[Lavety et al. 2019] Lavety, S., hya, Keshri, R. K., and Given, M. A. C. (2019). Multistep constant current charging strategy for a valve regulated lead-acid battery - 2019 ieee transportation electrification conference (itec-india). IEEE Transportation Electrification Conference (ITEC-India), Bengaluru, INDIA, DEC 17-19, 2019.
[Lin et al. 2016] Lin, H. C., He, Y. J., and Liu, C. W. (2016). Design of an efficient battery charging system based on ideal multi-state strategy - 2016 international symposium on computer, consumer and control (is3c). pages 956–959. 3rd International Symposium on Computer, Consumer and Control (IS3C), Natl Chin Yi Univ Technol, Xian, PEOPLES R CHINA, JUL 04-06, 2016.

[Maithili et al. 2021] Maithili, P., Kavitha, R., Nithishkumar, R., Ganeshbharathi, T., Kannan, S. V., and Kumar, R. M. (2021). Intelligent battery management system. 2021 International Conference on Advancements in Electrical, Electronics, Communication, Computing and Automation (ICAECA), pages 1–5.
[Singh and Mishra 2013] Singh, R. and Mishra, S. (2013). A magnetically coupled feedback-clamped optimal bidirectional battery charger. IEEE Transactions on Industrial Electronics, 60(2):422–432. Export Date: 03 September 2023; Cited By: 69. [Teo et al. 2013] Teo, K. T. K., Goh, H. H., Chua, B. L., Tang, S. K., and Tan, M. K. (2013). Modelling and optimisation of stand alone power generation at rural area. 2013 IEEE International Conference on Consumer Electronics - China, pages 51–56. RAYYAN-LABELS: it’s possible to learn about the SoC with fuzy logic.
[Victor et al. 2019] Victor, A., Mahato, D., Pundir, A., and Saxena, G. (2019). Design, simulation and comparative analysis of different types of solar charge controllers for optimized efficiency. Proceedings - 2019 Women Institute of Technology Conference on Electrical and Computer Engineering, WITCON ECE 2019, pages 17–21. Export Date: 03 September 2023; Cited By: 1.
[Wang et al. 2021] Wang, Y., Huang, F., Pan, B., Li, Y., and Liu, B. (2021). Augmented system model-based online collaborative determination of lead–acid battery states for energy management of vehicles. Measurement and Control (United Kingdom), 54(1):88–101. Export Date: 03 September 2023; Cited By: 4.
[Yoomak et al. 2018] Yoomak, S., Jettanasen, C., and Ngaopitakkul, A. (2018). Design of solar charger challenging various solar irradiance and temperature levels for energy storage. INTERNATIONAL JOURNAL OF INNOVATIVE COMPUTING INFORMA-TION AND CONTROL, 14(6):2071–2090.

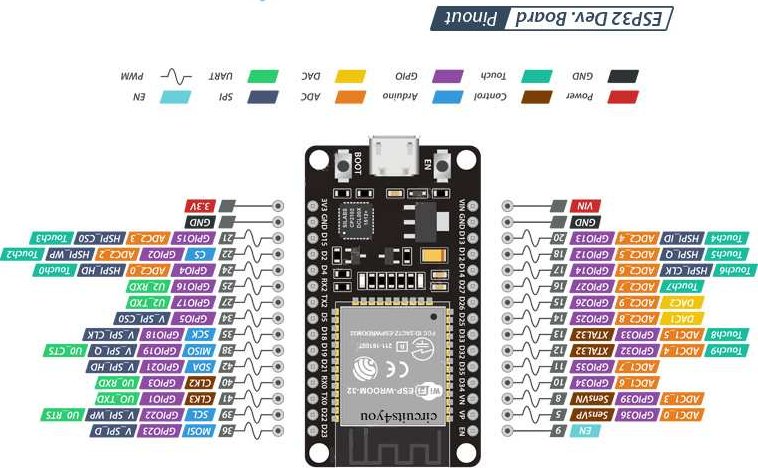
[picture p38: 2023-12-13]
Placa de Controle/Controle de Carga PWM/ESP32-Pinout.jpg

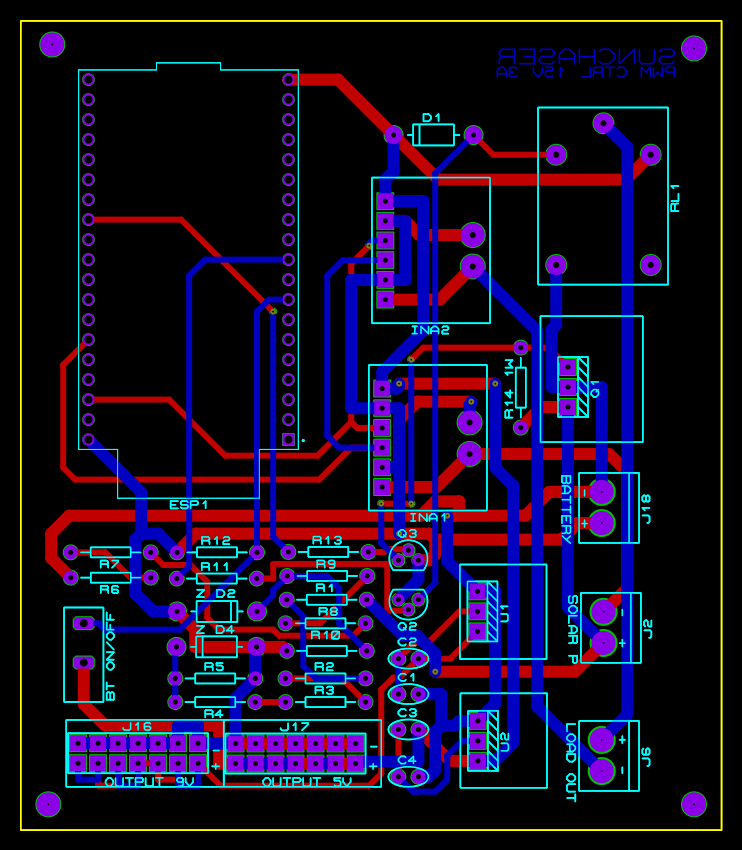
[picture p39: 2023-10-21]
Documentação/Diagramas/circuito_pcb.png

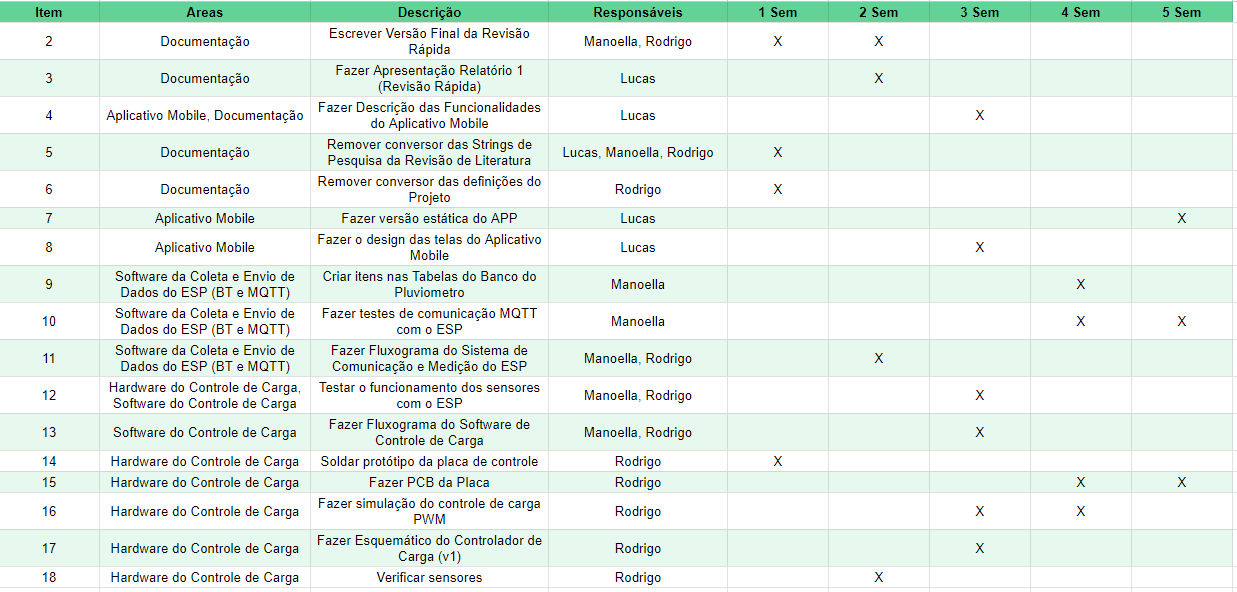
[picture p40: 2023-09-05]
Documentação/Diagramas/setembro.png

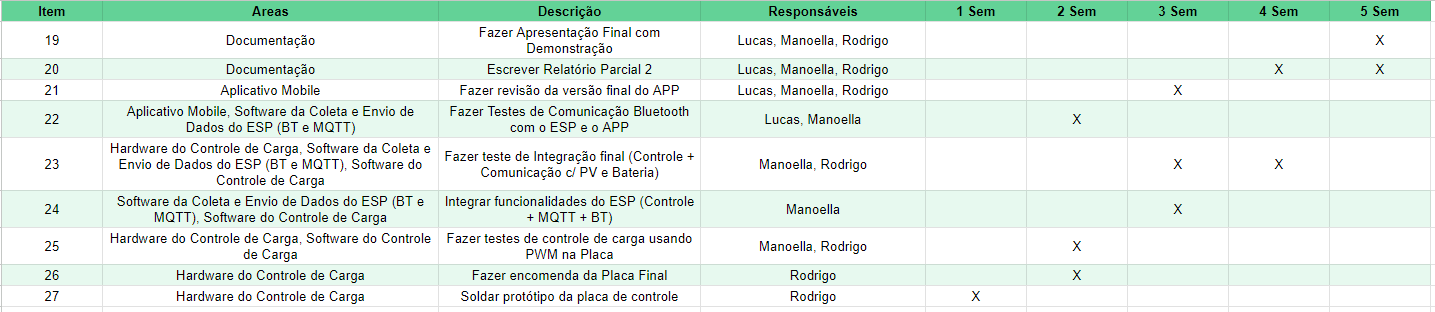
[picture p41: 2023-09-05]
Documentação/Diagramas/outubro.png

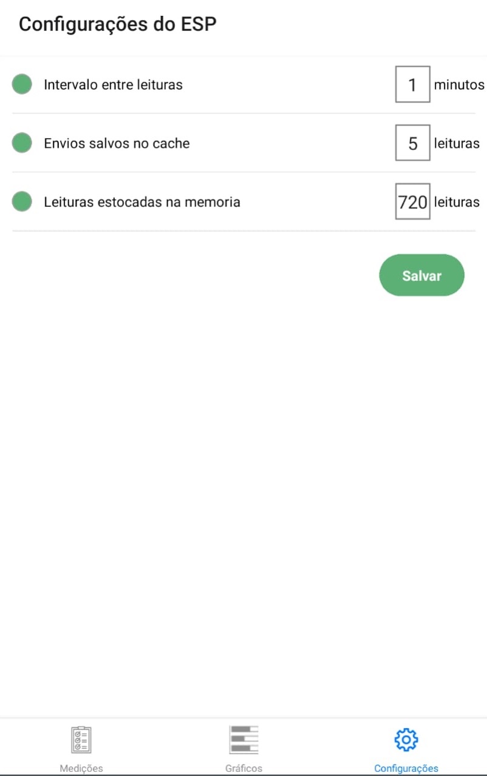
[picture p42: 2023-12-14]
Documentação/Diagramas/tela4.png

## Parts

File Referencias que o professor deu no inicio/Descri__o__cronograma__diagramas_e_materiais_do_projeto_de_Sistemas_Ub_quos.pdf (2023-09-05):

## Descric¸ao, cronograma, diagramas e materiais do projeto de ˜ Sistemas Ub´ıquos

Felipe Canever Fernandes¹

, Henrique Honorato¹

, Willian A. Pizoni¹

1Universidade Federal de Santa Catarina (UFSC) Ararangua – SC – Brazil ´

felipe.canever.fernandes@outlook.comm

henriquehrh@hotmail.com

willianaurelio@live.com

### 1. Descric¸ao˜

A gerac¸ao de energia solar por meio de placas fotovoltaicas se torna cada dia mais efi- ˜ ciente e entrega maior custo-benef´ıcio. Um dos problemas nos quais se pode esbarrar
em um sistema de carregamento fotovoltaico e como extrair a m ´ | axima pot ´ | encia de uma ˆ
placa para que o sistema seja alimentado de forma cont´ınua e eficiente. Para isso, foi
desenvolvido um modelo de rastreador de carga maxima que mostrar ´ | a a m ´ | axima pot ´ | encia ˆ
de um modulo fotovoltaico de 20 W utilizando um microcontrolador para ler a corrente ´
e a tensao do m ˜ | odulo. O sistema fotovoltaico carregar ´ | a uma bateria de ´ | ´ıons de l´ıtio (Li-
ion) ou, alternativamente, um conjunto de capacitores, que, por sua vez, contara com um ´ controlador ou estimador do estado de carga, de modo que o carregamento seja seguro, verificando-se continuamente a quantidade de carga armazenada na bateria, e garantir a sua operac¸ao segura, evitando-se a sobrecarga durante o carregamento. ˜

### 2. Cronograma

A Tabela 1 apresenta o cronograma das atividades a serem realizadas, com suas datas previstas e respectivos responsaveis. ´

Data limite | Atividade | Responsavel ´
27/05/2022 | Calculos da bateria ´ | Henrique, Willian
27/05/2022 | Calculos das placas ´ | Henrique, Willian
27/05/2022 | Calculos do circuito ´ | Henrique, Willian
27/05/2022 | Definic¸ao dos componentes ˜ | Henrique, Willian
27/05/2022 | Definic¸ao das ferramentas de desenvolvimento ˜ | Felipe
11/06/2022 | Testes e simulac¸ao no Proteus e Eagle ˜ | Felipe, Henrique, Willian
01/07/2022 | Desenvolvimento do prototipo ´ | Henrique, Willian
20/07/2022 | Versao final ˜ | Felipe, Henrique, Willian

Tabela 1. Cronograma de atividades

### 3. Diagrama

O diagrama da Figura 1 apresenta uma visao esquem ˜ | atica do sistema, composto de seus ´
dois modulos principais, o estimador de estado de carga de bateria, ´ | a esquerda, e o rastre- `
ador de maxima pot ´ | encia para a placa fotovoltaica, ˆ | a direita. `

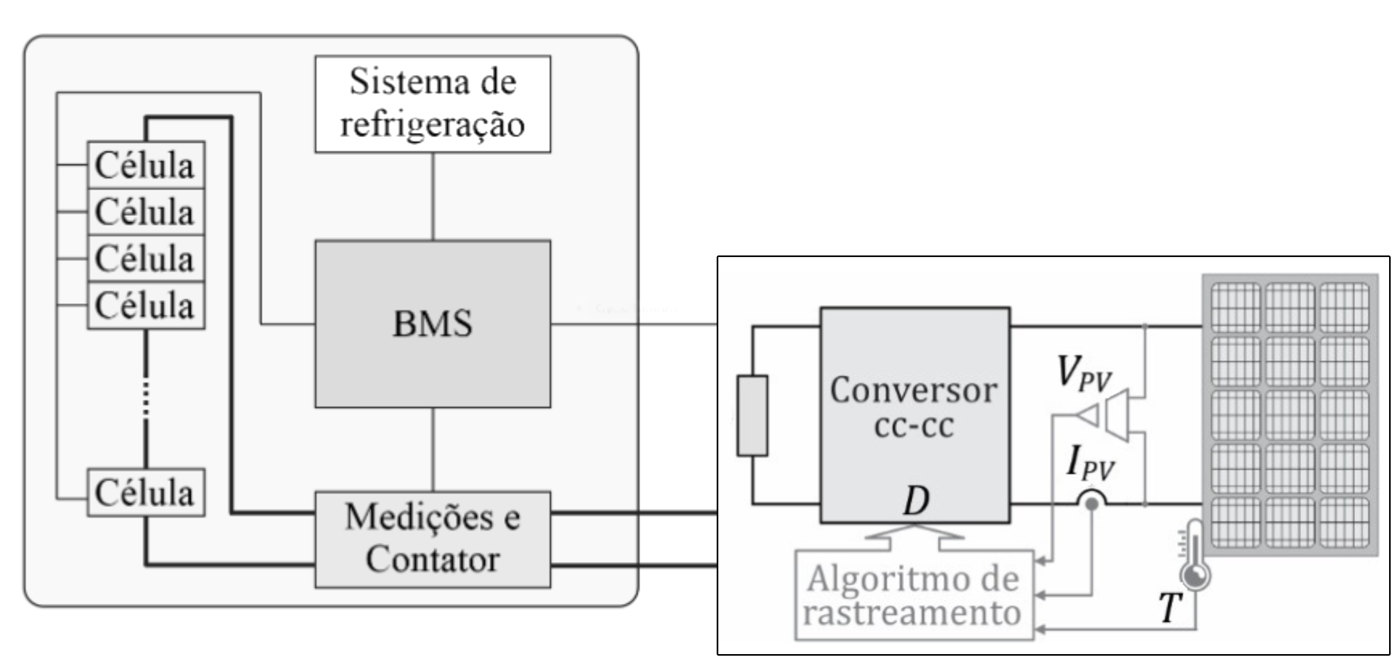
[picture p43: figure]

Figura 1. Diagrama do sistema

### 4. Materiais

Abaixo enumeram-se, de forma preliminar, os materiais necessarios para a realizac¸ ´ | ao do ˜
modulo do estimador de estado de carga de bateria. ´
- Microcontrolador; e
- Baterias de ´ıons de l´ıtio.
Caso se opte pela utilizac¸ao de capacitores, as baterias de l ˜ | ´ıtios seriam substitu´ıdas
por
- Resistores; e
- Capacitores.
Para o rastreador de maxima pot ´ | encia, os materiais seriam ˆ
- Microcontrolador;
- Modulo fotovoltaico de 20 W; ´
- Indutor;
- Diodo;
- Capacitor; e
- Resistor.

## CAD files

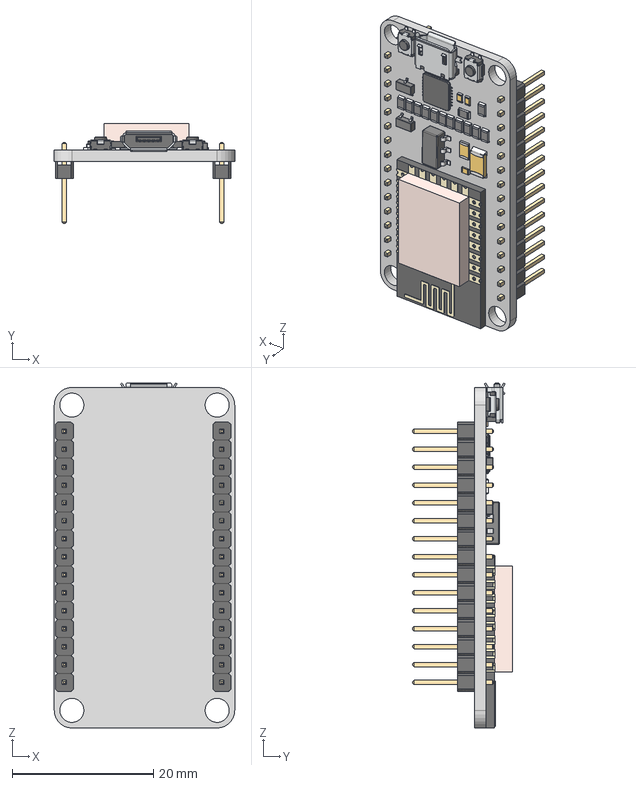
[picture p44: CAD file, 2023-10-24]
Placa de Controle/NodeMCU for Proteus (Arduino Magix)/NodeMCU for Proteus/3D Model/ESP8266 v7.stp
25.6 x 14.1 x 48.8 mm
micro usb shell
micro usb internal
micro usb contact x 5
switch v1
switch v1 (1)
spacer x 15
pin x 15
spacer (1) (1) x 15
pin (1) (1) x 15
TSOP-5 v4 v1
TSOP-5 v4 v1 (1)
TSOP-5 v4 v1 (1) (1)
R0805-NO v1 x 13
R0805-NO v1 (1) x 2
R0805-NO v1 (1) (1)
R0805-NO v1 (1) (2)
R0805-NO v1 (1) (3)
Cuerpo Microprocesador v1

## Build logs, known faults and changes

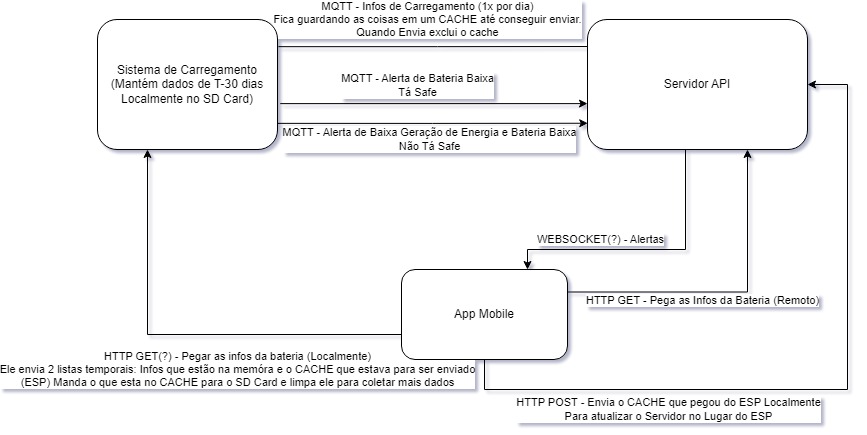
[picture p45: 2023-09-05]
Documentação/Planejamento/Diagrama do Projeto (alto nivel, sistema todo).jpg

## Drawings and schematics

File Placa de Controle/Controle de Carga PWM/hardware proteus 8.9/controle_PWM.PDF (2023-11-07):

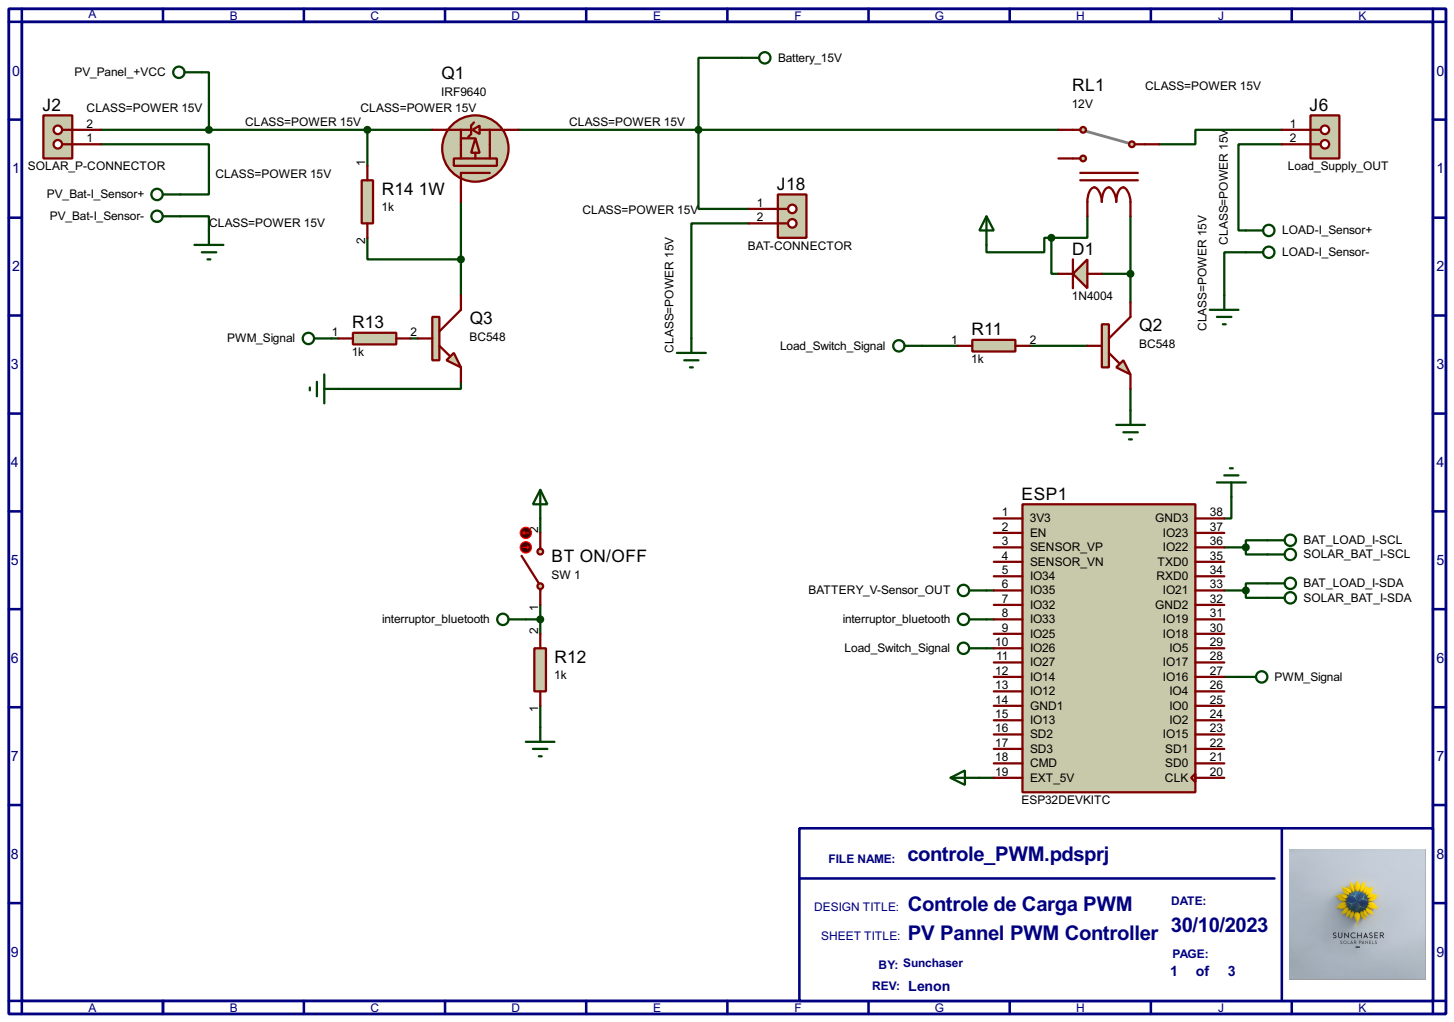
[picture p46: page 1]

CLASS=POWER 15V

SHEET TITLE: DESIGN TITLE: PV Pannel PWM Controller

Controle de Carga PWM

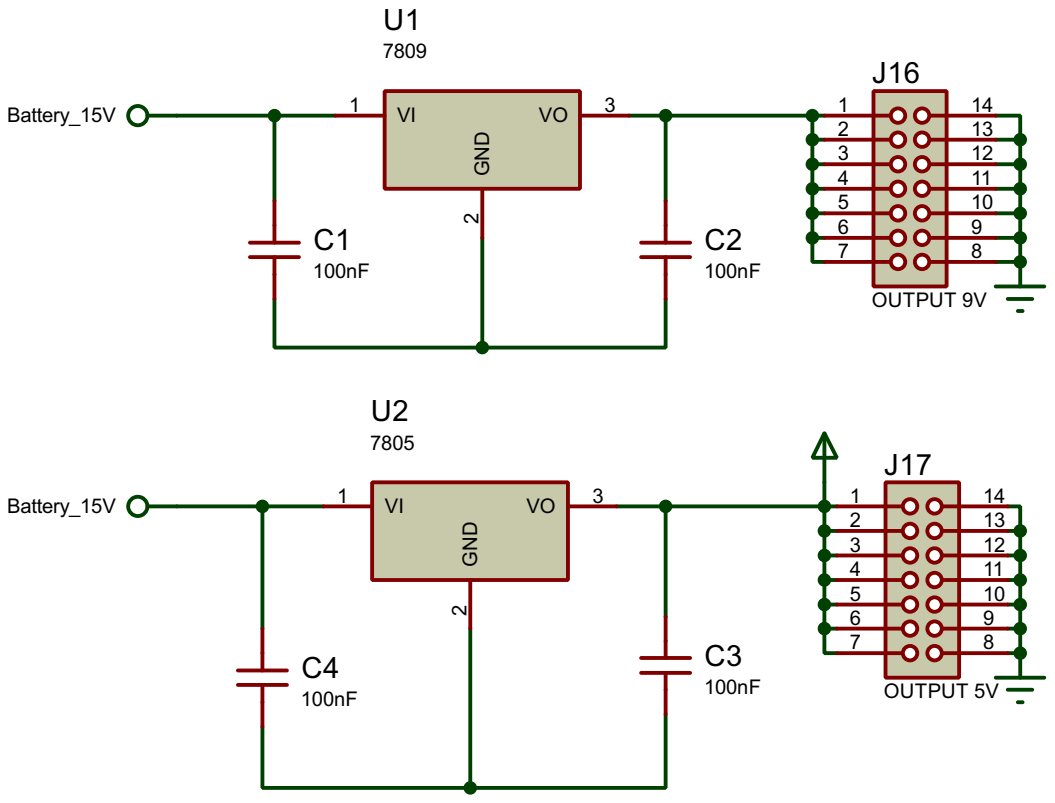
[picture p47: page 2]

SHEET TITLE: DESIGN TITLE: Reguladores de Tensão

Controle de Carga PWM

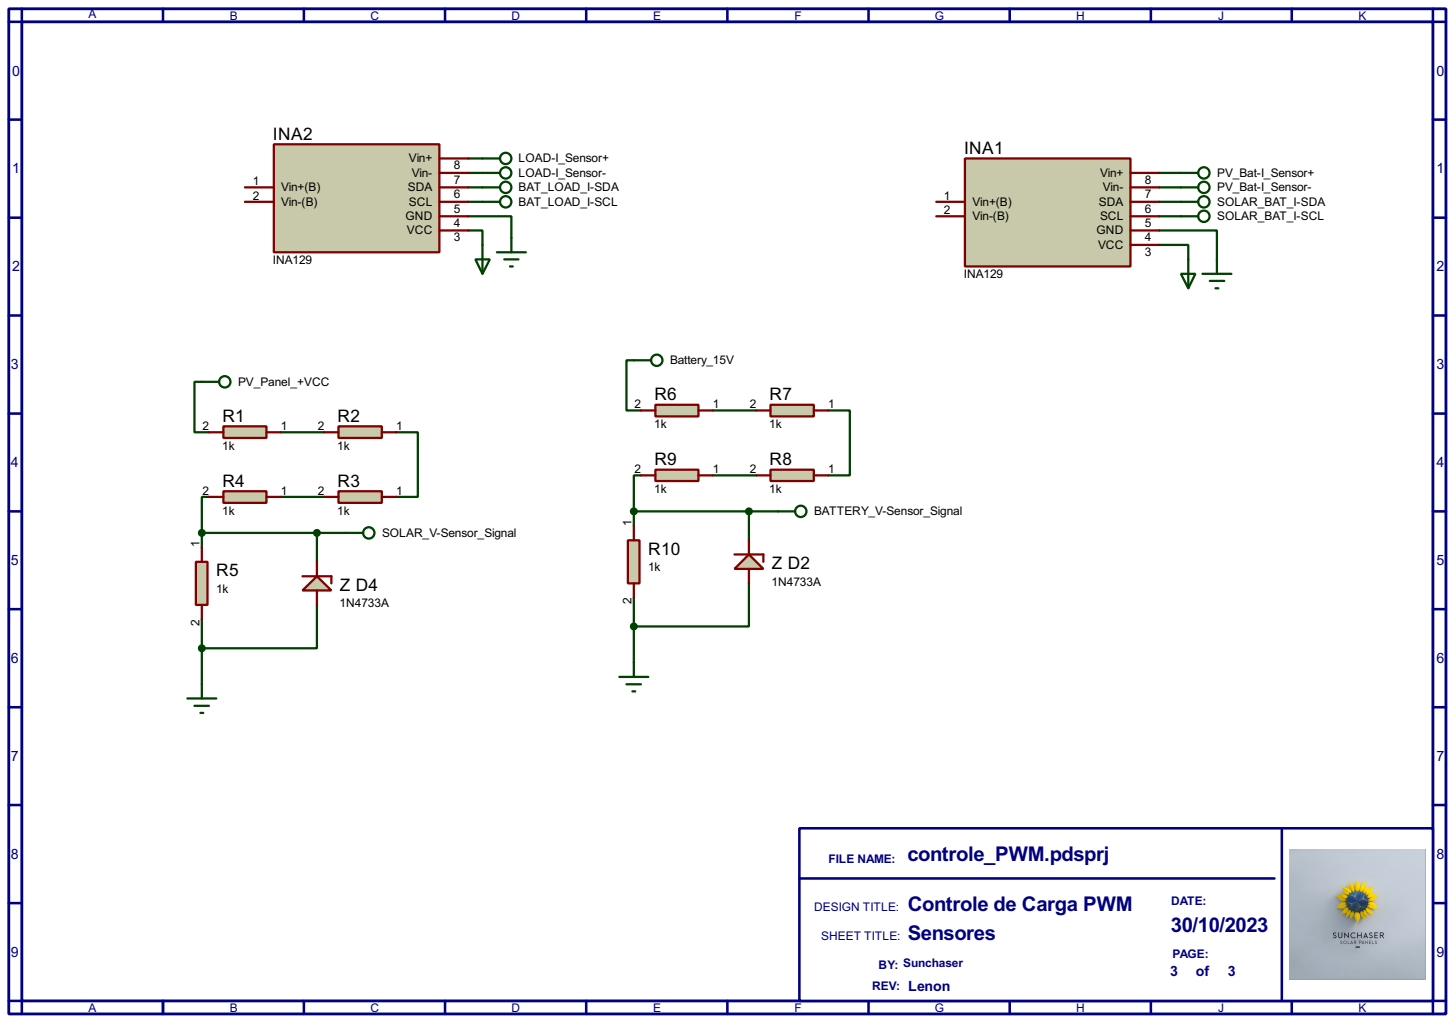
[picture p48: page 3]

SHEET TITLE: DESIGN TITLE: Sensores

Controle de Carga PWM

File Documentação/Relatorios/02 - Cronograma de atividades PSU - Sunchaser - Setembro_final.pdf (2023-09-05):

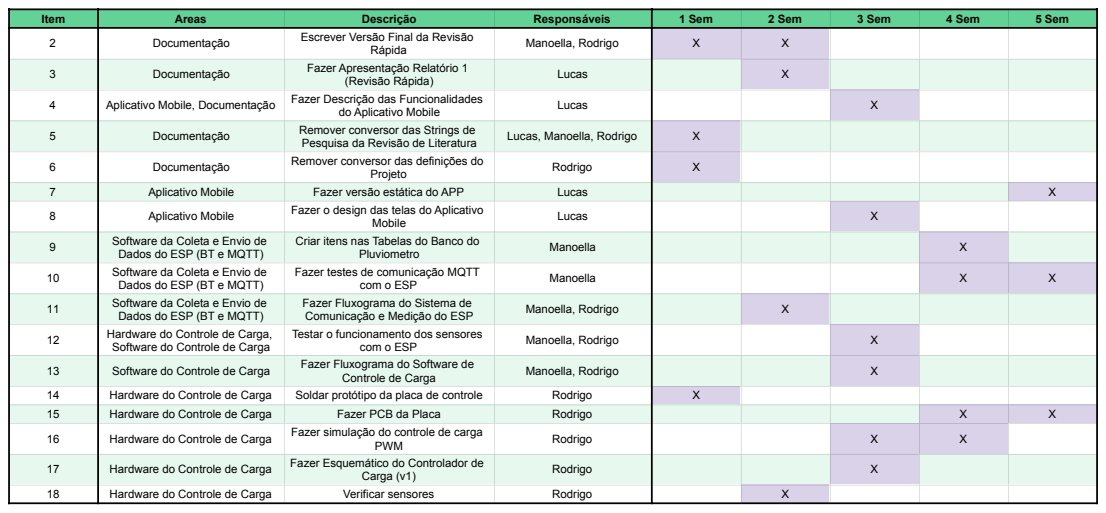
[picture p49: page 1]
Item; Areas; Descrição; Responsáveis; 1 Sem; 2 Sem; 3 Sem; 4 Sem; 5 Sem 2; Documentação; Escrever Versão Final da Revisão

Rápida Manoella, Rodrigo | X X

3 | Documentação Fazer Apresentação Relatório 1 (Revisão Rápida) Lucas | | X

4 | Aplicativo Mobile, Documentação Fazer Descrição das Funcionalidades do Aplicativo Mobile Lucas | | X

5 | Documentação Remover conversor das Strings de Pesquisa da Revisão de Literatura Lucas, Manoella, Rodrigo | X

6 | Documentação Remover conversor das definições do Projeto Rodrigo | X

7 | Aplicativo Mobile Fazer versão estática do APP Lucas | | X
8 | Aplicativo Mobile Fazer o design das telas do Aplicativo Mobile Lucas | | X

9 | Software da Coleta e Envio de Criar itens nas Tabelas do Banco do Pluviometro Manoella Dados do ESP (BT e MQTT) | | X

10 | Software da Coleta e Envio de Fazer testes de comunicação MQTT com o ESP Manoella Dados do ESP (BT e MQTT) | | X X

11 | Software da Coleta e Envio de Fazer Fluxograma do Sistema de Comunicação e Medição do ESP Manoella, Rodrigo Dados do ESP (BT e MQTT) | | X

12 | Hardware do Controle de Carga, Testar o funcionamento dos sensores com o ESP Manoella, Rodrigo Software do Controle de Carga | | X

13 | Software do Controle de Carga Fazer Fluxograma do Software de Controle de Carga Manoella, Rodrigo | | X

14 | Hardware do Controle de Carga Soldar protótipo da placa de controle Rodrigo | X
15 | Hardware do Controle de Carga Fazer PCB da Placa Rodrigo | | X X
16 | Hardware do Controle de Carga Fazer simulação do controle de carga PWM Rodrigo | | X X

17 | Hardware do Controle de Carga Fazer Esquemático do Controlador de Carga (v1) Rodrigo | | X

18 | Hardware do Controle de Carga Verificar sensores Rodrigo | | X

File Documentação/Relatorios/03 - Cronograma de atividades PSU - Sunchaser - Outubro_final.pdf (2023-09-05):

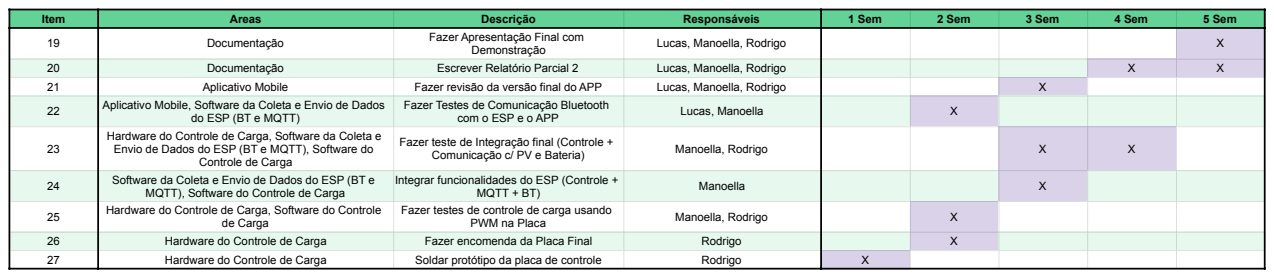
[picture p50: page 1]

Item | Areas Descrição Responsáveis | 1 Sem 2 Sem 3 Sem 4 Sem 5 Sem
19 | Documentação Fazer Apresentação Final com Demonstração Lucas, Manoella, Rodrigo | | X

20 | Documentação Escrever Relatório Parcial 2 Lucas, Manoella, Rodrigo | | X X
21 | Aplicativo Mobile Fazer revisão da versão final do APP Lucas, Manoella, Rodrigo | | X
22 | Aplicativo Mobile, Software da Coleta e Envio de Dados Fazer Testes de Comunicação Bluetooth com o ESP e o APP Lucas, Manoella do ESP (BT e MQTT) | | X

23 | Hardware do Controle de Carga, Software da Coleta e Fazer teste de Integração final (Controle + Envio de Dados do ESP (BT e MQTT), Software do Comunicação c/ PV e Bateria) Manoella, Rodrigo Controle de Carga | | X X

24 | Software da Coleta e Envio de Dados do ESP (BT e Integrar funcionalidades do ESP (Controle + MQTT + BT) Manoella MQTT), Software do Controle de Carga | | X

25 | Hardware do Controle de Carga, Software do Controle Fazer testes de controle de carga usando PWM na Placa Manoella, Rodrigo de Carga | | X

26 | Hardware do Controle de Carga Fazer encomenda da Placa Final Rodrigo | | X
27 | Hardware do Controle de Carga Soldar protótipo da placa de controle Rodrigo | X

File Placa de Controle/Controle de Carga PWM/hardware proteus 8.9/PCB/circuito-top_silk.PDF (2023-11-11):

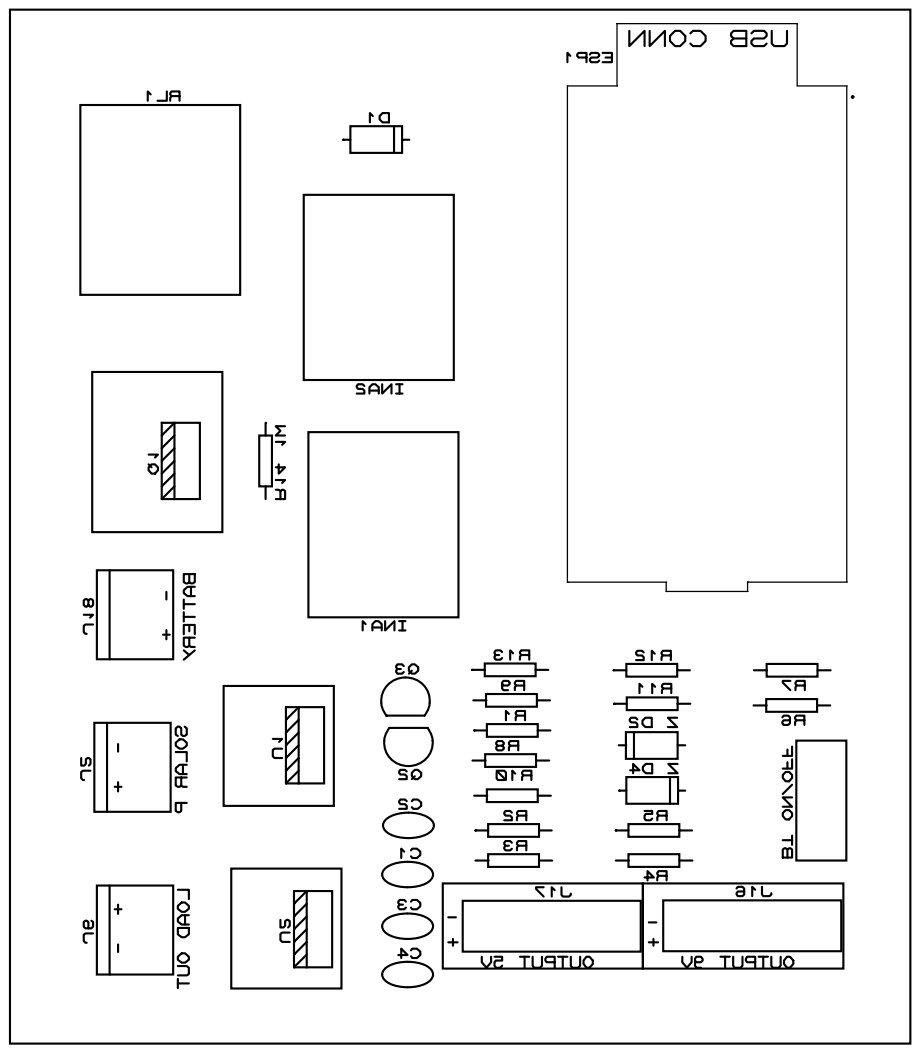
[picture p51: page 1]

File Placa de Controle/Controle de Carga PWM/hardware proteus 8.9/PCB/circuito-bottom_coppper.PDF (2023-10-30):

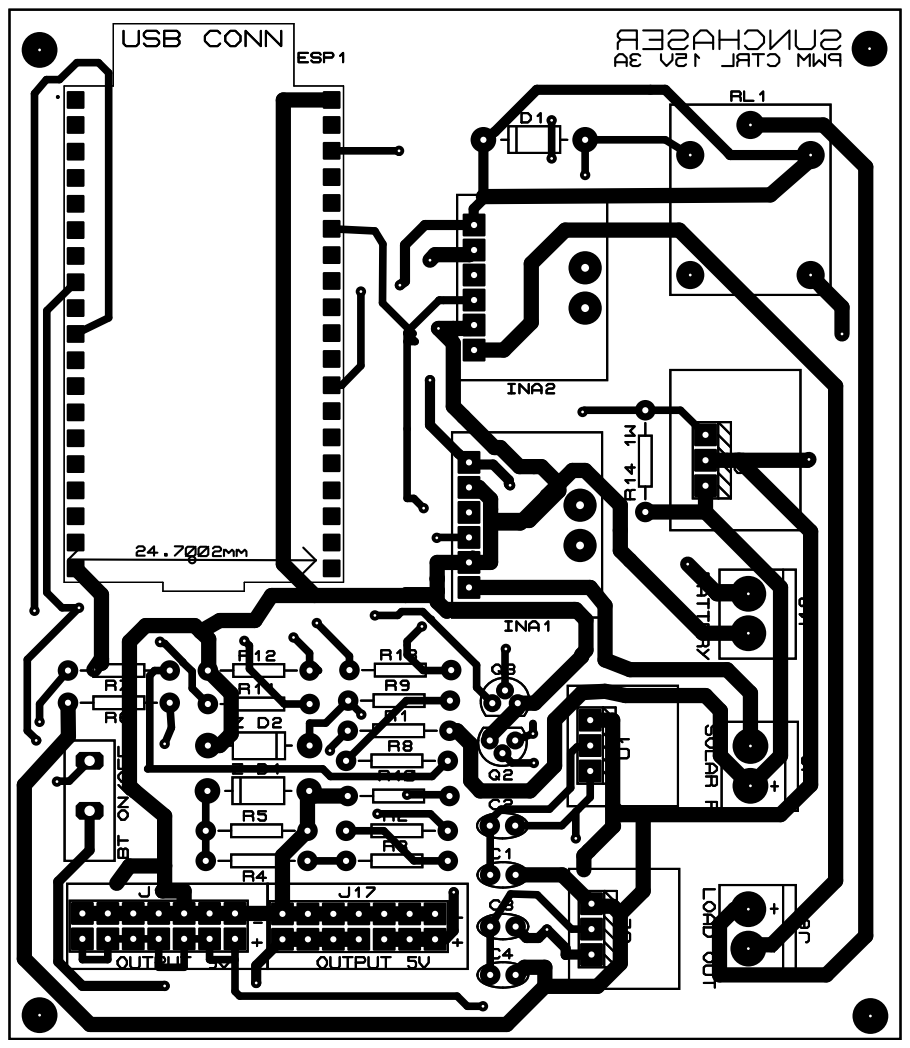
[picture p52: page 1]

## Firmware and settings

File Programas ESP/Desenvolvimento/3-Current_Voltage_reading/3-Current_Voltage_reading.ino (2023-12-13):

#include "Sensors.h"

/* calculated I2C address: 0 = GND, 1 = V+
 * The address is controlled by the A0 and A1 inputs on the INA219:
 *
 * Calculated address: b100ABCD
 * A0 controls C and D: GND = 00, V+ = 01, SDA = 10, SCL = 11
 * A1 controls A and B: GND = 00, V+ = 01, SDA = 10, SCL = 11
 *
 * E.g. if A0 is tied to ground and A1 is tied to V+,
 * the resulting address is b1000100 = 0x44
 */
Adafruit_INA219 battery_ina219(0x41);
Adafruit_INA219 pv_ina219(0x41);
Sensors sensors(battery_ina219, pv_ina219);

void setup() {
  // Open serial communications and wait for port to open:
  Serial.begin(115200);
  while (!Serial) {
    ; // wait for serial port to connect. Needed for native USB port only
  }

  sensors.INA_init();
}

void loop() {
  float bat_current, bat_voltage, pv_voltage, pv_current;
  bat_current = sensors.battery_current();
   pv_current = sensors.pv_current();
  // bat_voltage = sensors.battery_voltage();
  // pv_voltage = sensors.pv_voltage();

  Serial.print("Battery current: ");
  Serial.println(bat_current);
   Serial.print("    PV current: ");
   Serial.println(pv_current);
  // Serial.print("    Battery voltage: ");
  // Serial.print(bat_voltage);
  // Serial.print("    PV voltage: ");
  // Serial.println(pv_voltage);

  delay(1000);
}

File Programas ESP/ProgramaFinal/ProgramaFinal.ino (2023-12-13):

#include "Sensors.h"
#include "BatteryControl.h"
#include "TimerInterrupt.h"
#include "SaveToFlash.h"
#include "TimeConfigurations.h"
#include "communicator.h"

Adafruit_INA219 battery_ina219(0x40);
Adafruit_INA219 pv_ina219(0x41);
Sensors sensors(battery_ina219, pv_ina219);

BatteryControl battery_controller(&sensors);

TimeConfigurations timeConfigs;
Communicator communicator;
SaveToFlash fileSystem(&timeConfigs);
TimerInterrupt timerInterrupt(&fileSystem, &communicator, &sensors, &timeConfigs);

void setup()
{
  Serial.begin(115200);

  // faz as configurações iniciais de cada objeto, dos attach dos interrupts
  sensors.INA_init();
  battery_controller.PWM_init();
  fileSystem.mountLittleFS();
  timerInterrupt.timer_init();
  
  communicator.init(&fileSystem, &timeConfigs, &battery_controller);

  // verifica o tempo da rede (fica travado aqui até ele conseguir pegar o tempo inicial pra fazer as coisas)
  // ou seja, antes daqui tando o PWM quanto o switch do Load tem que estar abertos para não dar problema, pq o esp vai ficar travado aqui
  Serial.println("Verificando o tempo da rede");
  
  communicator.setup_datetime();
  Serial.println(DateTime.toString());
  communicator.sleep(); // chama isso pra botar pra dormir -> isso aqui desliga o AP tb, então cuidado
  
}

bool envio = true; // flag pra teste, pode excluir

void loop()
{
  // battery_controller.battery_loop();
  // chama a função de verificar flags do comunicador
  communicator.interrupt_handler();
  timerInterrupt.timer_interruption();

  if (communicator.is_server)
  {
    //   Serial.println("é server");
    communicator.run_server();
    envio = true;
  }

  battery_controller.battery_loop();

//  delay(500);
}

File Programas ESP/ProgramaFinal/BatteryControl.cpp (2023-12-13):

/*

Bulk charge stage:
- Duty_Cycle = 1 (fluxo de energia é máximo) e S1 bloqueado
- corrente de recarga = corrente de curto-circuito I_sc do gerador fotovoltaico
- Condição para mudança de estado: a tensão nos terminais do banco de baterias alcance a tensão de absorção
(Absorption Voltage AV = 14,4 V)

Absorption stage:
- A tensão do banco de baterias é igual a AV = 14,4 V
- O controlador inicia a modulação PWM da corrente de recarga (de 1 para 0), reduzindo gradativamente seu valor
médio (I_med = valor médio da corrente terminal I_t do banco de baterias) por meio da atualização do Duty_Cycle
aplicado ao interruptor S1.
- Condição para mudança de estado: a corrente de recarga decaia abaixo do valor de corrente limiar (Treshold
current TC = 0,25 A).
- Obs: Tempo máximo de permanência no estágio de absorção (Absorption Time AT) entre 1 a 3 horas no máximo.

Float stage:
- A tensão do banco de baterias é reduzida e mantida regulada em um patamar seguro de operação, denominado por
tensão de flutuação (Float Voltage FV = 13,5 V)
- A corrente de recarga assume um valor residual (Residual Current RC)

Condição para conexão da carga em S2:
    - Tensão para desconexão da carga (LDV = 11,5 V)
    - Tensão para reconexão da carga (LRV = 12,5 V)

*/

#include "BatteryControl.h"

BatteryControl::BatteryControl(Sensors *sensors)
{
  read_sensors = sensors;
}

void BatteryControl::PWM_init()
{
  pinMode(S2_Pin, OUTPUT);

  ledcSetup(PWM_Channel, freq, resolution); // Configure PWM functionalitites
  ledcAttachPin(PWM_Pin, PWM_Channel);      // Attach the channel to the GPIO to be controlled
}
void BatteryControl::changeDutyCycle()
{
  if (this->dutyCycle > 255)
  {
    this->dutyCycle = 255;
  }
  if (this->dutyCycle < 0)
  {
    this->dutyCycle = 0;
  }
  ledcWrite(PWM_Channel, this->dutyCycle); // Corrente máxima Isc, duty cycle = 1 (255)

//  Serial.print("dutyCycle: ");
//  Serial.println(this->dutyCycle);
}

void BatteryControl::bulk_stage()
{
  this->dutyCycle = 255;
  this->changeDutyCycle();
}

void BatteryControl::check_error(float error)
{
  if (error > 0)
  {
    if (dutyCycle > 1)
    {
      this->dutyCycle--; // Diminui o duty cycle em 1 para diminuir a tensão de recarga
    }
  }
  else if (error < 0)
  {
    this->dutyCycle++; // Aumenta o duty cycle em 1 para aumentar a tensão de recarga
  }

//  Serial.printf("Error: %f\n", error);
}

void BatteryControl::absorption_stage()
{ // tentar igualar a tensão lida com AV
  float BatteryVoltage = read_sensors->battery_voltage();
  float error = BatteryVoltage - AV;

  this->check_error(error);

  this->changeDutyCycle();
}

// Tensão do banco de baterias é reduzida e mantida regulada no patamar da tensão de flutuação (FV)
void BatteryControl::float_stage()
{
  float BatteryVoltage = read_sensors->battery_voltage();
  float error = BatteryVoltage - AV;

  this->check_error(error);

  this->changeDutyCycle();
}
int counter_prints_bc = 0;
int print_th = 500;
void BatteryControl::charging_control()
{
  float BatteryCurrent, BatteryVoltage, PV_Voltage;
  BatteryCurrent = read_sensors->pv_current();
  BatteryVoltage = read_sensors->battery_voltage();

  counter_prints_bc++;
  if(counter_prints_bc>print_th){
     Serial.print("Corrente PV-BAT: ");
  Serial.print(BatteryCurrent);
  Serial.print("    Tensao BAT: ");
  Serial.println(BatteryVoltage);
  Serial.print("    duty: ");
  Serial.println(this->dutyCycle);
  counter_prints_bc = 0;
  }
 

//  delay(50);

  if(BatteryVoltage < AV * 0.9 ||  BatteryCurrent == 0){
    
  if(counter_prints_bc>print_th){
      Serial.println("bulk_stage");
  }
      bulk_stage();
    }
    
    else if((BatteryVoltage <= AV* 1.1 && BatteryVoltage >= AV* 0.9 ) && (BatteryCurrent > TC ) ){
      
  if(counter_prints_bc>print_th){
      Serial.println("absorption_stage");
  }
      absorption_stage();
    }
    else if((BatteryVoltage <= AV* 1.1 && BatteryVoltage >= AV* 0.9 ) && (BatteryCurrent <= TC )){
      
  if(counter_prints_bc>print_th){
      Serial.println("float_stage");
  }
      float_stage();
    }
  else
  {
    Serial.println("Pontape inicial pra verificar a corrente");
    this->dutyCycle = 1;
    this->changeDutyCycle();
  }

  
  if(counter_prints_bc>print_th){
    counter_prints_bc = 0;
  
  }
}

void BatteryControl::load_connection()
{
  float BatteryVoltage, PV_Voltage, BatLoadCurrent;
  BatteryVoltage = read_sensors->battery_voltage();
  BatLoadCurrent = read_sensors->battery_current();
  PV_Voltage = read_sensors->pv_voltage();


  if (BatteryVoltage < LDV || BatLoadCurrent >= LDC)
  {
    Serial.println("DESCONECTANDO CARGA!");
    digitalWrite(S2_Pin, HIGH); // Corta a alimentação da carga em S2
    delay(1000);
  }
  else if (BatteryVoltage > LRV)
  {
    digitalWrite(S2_Pin, LOW); // Reconecta a carga em S2
  }
}

void BatteryControl::battery_loop()
{
  if (!started)
  {
    this->dutyCycle = 255;
    this->changeDutyCycle();
    delay(500);
    started = true;
  }
  charging_control();
  load_connection();
}

void BatteryControl::stopCharging(){
    this->dutyCycle = 0;
    this->changeDutyCycle();
}

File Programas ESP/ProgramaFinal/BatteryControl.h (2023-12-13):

#ifndef BATTERYCONTROL_H
#define BATTERYCONTROL_H

#include <Arduino.h>
#include "Sensors.h"

class BatteryControl
{
private:
    // setting PWM properties
    const int PWM_Pin = 16; // 16 corresponds to GPIO16
    const int freq = 50000; // in Hz
    const int PWM_Channel = 0;
    const int resolution = 8; // 8 bit resolution - value from 0 to 255
    int dutyCycle = 0;
    bool started = false;

    // S2 load pin configuration
    const int S2_Pin = 26; // 26 corresponds to GPIO26

    // constants definitions (pontos de ajuste)
    const float AV = 12;  // Absorption Voltage (14.4 V) - para a de teste é 12.6 (litio)
    const float TC = 22;  // Threshold Current in mA (250mA)
    const float FV = 10;  // Float Voltage (13.5 V)
    const float LDV = 9;  // Load Disconnect Voltage
    const float LRV = 11; // Load Reconnect Voltage

    const float LDC = 1100; // Load Disconnect Current

    Sensors *read_sensors;

    void bulk_stage();
    void absorption_stage();
    void float_stage();
    void charging_control();
    void load_connection();
    void changeDutyCycle();

public:
    BatteryControl(Sensors *sensors);
    void PWM_init();
    void battery_loop();
    void check_error(float error);
    void stopCharging();
};

#endif

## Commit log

2023-08-31 adicionei o controle SWITCH da carga e fiz uma sheet para o controle das saidas dos sinais dos sensores
2023-09-04 seprarei o circuito em varios designs
2023-09-05 enviei os arquivos da revisão de literatura e cronograma v1 e coloquei instruções pra cada membro
    [articles.csv, customizations_log.csv]
2023-09-11 adicionei o sensor de corrente da carga, mudei o layout do outro sensor de corrente e adicionei um zenner nos divisores de tensão
2023-09-14 troquei os resistores do divisor de tensão e coloquei um zenner. troquei os resistores para valores comerciais e fiz ser 3:1 pra não bugar com o Vdrop do zener
2023-09-16 Testes para a leitura AD da corrente e tensão
2023-09-17 adicionei os testes de controle desacoplado do mosfet
2023-09-17 mudei a tensão no gate dos IRF540 para 3V (assim só precisa de 2 pilhas AA)
2023-09-19 troquei o transistor para o que o lennon tem coloquei os reguladores de tensão coloquei os package nos resistores
2023-09-19 troquei os pinos de saida de sinal de corrente
2023-09-19 fiz o design PCB inicial do circuito
2023-09-21 coloquei o esp e os sensores de corrente na placa organizei as coisas no pcb
2023-10-01 Correções do código e criação efetiva da página de configuração
2023-10-02 Protótipo do gráfico feito e melhorias na página de configurações
2023-10-02 Melhorias nos componentes e avanço na página de gráficos
2023-10-05 Inclusão do PWM, mas ainda não testei
2023-10-05 correções do projeto que fiz com o lennon
    [pwm_control - CADCAM Bottom Copper.GBR, pwm_control - CADCAM Bottom Solder Resist.GBR, pwm_control - CADCAM Drill TOP-BOT Plated.GBR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]
2023-10-05 diagramas e relatorio de setembro
2023-10-05 quebrei o diagrama de memoria em diagramas menores
2023-10-05 atualizei os diagramas de app e alto nivel para todos terem o mesmo padrão
2023-10-06 fiz a nova placa contendo o switch para ativar e desativar o bluetooth
2023-10-06 aumentei o espaço para o dissipador do mosfet
2023-10-10 troquei pra um mosfet canal P com controle pwm em serie
2023-10-21 atualização do ircuito com mosfet tipo p
2023-10-24 ajustes no esp
    [ESP8266 v7.stp]
2023-10-24 Organização dos arquivos e lógica do controle PWM
2023-10-30 correção do tamanho do ESP
    [pwm_control - CADCAM Bottom Copper.GBR, pwm_control - CADCAM Bottom Solder Resist.GBR, pwm_control - CADCAM Drill TOP-BOT Plated.GBR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]
2023-10-31 Correções na biblioteca "Sensors"
2023-11-07 Mudança nos botões e criação da página de desconexão
2023-11-07 Botão de fechar app funcionando
2023-11-12 Testes com a interrupção de timer e BLE
2023-11-14 incrementando o codigo de requisição com a interrupção aos poucos
2023-11-14 esp funcionando como cliente e servidor de forma alternada
2023-11-14 corrigido o problema de ele não fechar o access point
    [Wifi-Server_Client.ino]
2023-11-16 diagrama de classe
2023-11-16 base para o codigo final
2023-11-18 Modifiquei para classe
2023-11-18 separei em modulos e esta funcionando com interrupção. coloquei o http e o mqtt para usar o mesmo WifiClient criei um rascunho do mqtt para editar quando estiver com o eduardo amanha
2023-11-19 pego a data com o datetime server ntp e ela fica acessivel de todo o codigo
2023-11-19 eu paro a tentativa de reconecção mqtt caso haja a interrupção do server
2023-11-19 Home funciona nessa nova config, só que está feio, to commitando como precaução
2023-11-19 Melhorias do App.js e alterações de design no graph.js e seus componentes
2023-11-19 slepp do communicator e privatização de algumas funções
2023-11-19 faz a verificação de tipo no envio
2023-11-21 ajustei o padrão de envio json das leituras
2023-11-21 troquei pra tudo funcionar com ArduinoJSON
2023-11-22 adicionei uma struct para ser uma lista de structs, pq cada ENTRADA tem 2 valores (datetime e value)
2023-11-22 corrigi o erro de que ele lia 2x no inicio
2023-11-22 grafico dinamico (mas eu acho que esse tipo de grafico não aceita dado temporal muito bem, então a distancia entre os pontos não é fiel ao real)
2023-11-23 Fiz funcionar usando a struct que a manu vai usar para os readings
2023-11-27 mudei o saveToCache para receber os parametros
2023-11-27 adicionei os arquivos da flash atualizados para o final project
2023-11-27 adicionei a coleta de dados da memoria no cache e arrumei a paginação
2023-11-28 faz o envio dos dados pro mqtt agora e aparentememte corrigiu o problema da reconecção, mas não aparece no pluviometro. parece que o problema é no broker que quer as 3 tags juntas
    [ProgramaFinal.ino, TimerInterrupt.cpp, communicator_client_module.cpp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]
2023-11-28 Melhorias do código e tratamento de erros
2023-12-02 exclui o componente que eu tava criando (rascunho)
2023-12-02 troquei o nome do projeto do proteus que tava errado
2023-12-04 correções do envio MQTT, agora funciona (mas a reconexão wifi ainda esta bugada, mas acho que é o meu spot de wifi do celular)
    [TimerInterrupt.cpp, communicator_client_module.cpp, communicator_mqtt_module.cpp]
2023-12-04 coloquei o conector para levar a tensão da pateria para a placa de reguladores (mas n fiz o pdf pq no linux eu n consigo e eu não abri a minha vm)
2023-12-11 Algumas correções no BatteryControl
2023-12-11 esqueci de colocar o sensor de tensão da bateria no esp...
2023-12-11 Continuação de melhoria e correções de falhas
2023-12-12 correções para o controle de carga. testado e funciona ate com o painel solar no sol. ele fica entre float e absorption quando a corrente ta baixa e ele se decide quando ela fica beeem baixa (quando 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
2023-12-12 Limpeza e otimização de código
2023-12-12 Correção de bug
2023-12-13 AGORA TUDO FUNCIONA!!! o ADC2 é usado pelo EIFI quando esta em AP, por isso não lê no pino 13 a tesão. e se eu usar 5v na nterrupção no pino 33, como ele esta no ADC1 junto com as leituras de tensão 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
    [5-BatteryControl.ino, BatteryControl.cpp, BatteryControl.h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]
2023-12-13 removi alguns prints de debug
2023-12-13 criei uma rota para o app checar se tem conexão
2023-12-13 correções nas placas que fizemos durante os testes e atualizei a placa master, que é a junção de todas que fizemos, usando dupla face. o que eu mudei nas placas foi: - adicionei um diodo para evitar 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
2023-12-13 esqueci o pwm
2023-12-14 circuitos proteus
2023-12-14 correções dos erros que aconteceram durante a apresentação
